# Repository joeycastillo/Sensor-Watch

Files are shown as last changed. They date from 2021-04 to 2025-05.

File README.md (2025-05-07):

The Sensor Watch
================

The [Sensor Watch](https://www.sensorwatch.net) is a board replacement for the classic Casio F-91W wristwatch. It is powered by a Microchip SAM L22 microcontroller with built-in segment LCD controller. You can write your own programs for the watch using the provided watch library, program the watch over USB using the built-in UF2 bootloader, and then install the board in your existing watch case to run your own software on your wrist.

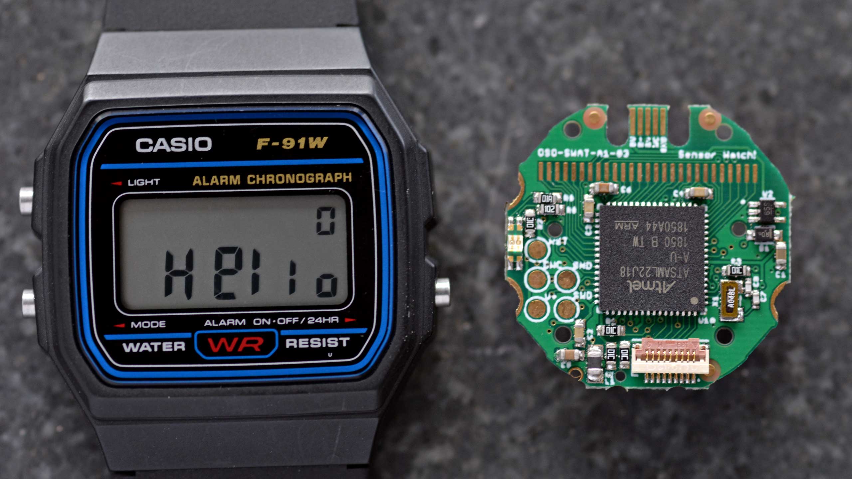
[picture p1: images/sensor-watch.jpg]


Features:
* ARM Cortex M0+ microcontroller
* 32KHz crystal for real-time clock with alarm function
* Ten digit segment LCD, plus five indicator segments
* Three interrupt capable buttons
* Red / green PWM’able LED backlight
* Optional piezo buzzer (requires some light soldering)
* On-board USB Micro B connector
* Reset button with double-tap UF2 bootloader
* Nine-pin flex PCB connector

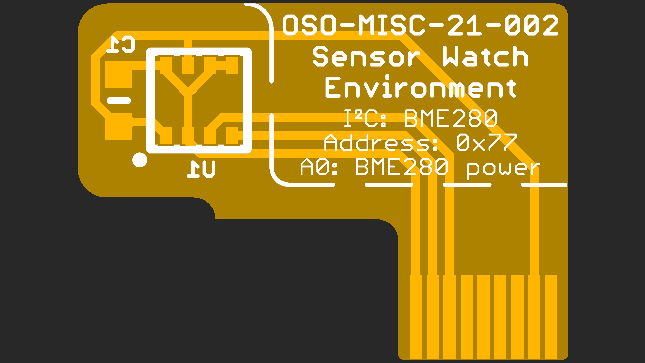
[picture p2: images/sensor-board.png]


You may have noticed that there are no sensors on this board. That is by design: rather than pick sensors for you, the goal is to add a tiny flexible PCB with the sensors YOU want, and interface them over the nine-pin connector. The connector provides the following options for power and connectivity:

* 3V power (nominal voltage from a CR2016 coin cell, can drop to ~2.7V)
* An I²C interface with built-in pull-up resistors
* Five general purpose IO pins, which can be configured as:
    * Five analog inputs
    * Five interrupt-capable digital inputs, with internal pull-up or pull-down resistors
    * Five digital outputs
    * SPI controller (with one spare analog / GPIO pin leftover)
    * One UART TX/RX pair (with three GPIO leftover)
    * Up to four PWM pins on two independent TC instances
    * Two external wake inputs that can wake from the ultra-low-power BACKUP mode

| **Pin** | **Digital** | **Interrupt** | **Analog** | **I2C** | **SPI** | **UART** | **PWM**  | **Ext. Wake** |
| :-----: | :---: | :---: | :---: | :---: | :---: | :---: | :---: | :---: |
| **A0**  | PB04 | EIC/EXTINT\[4\] | ADC/AIN\[12\] | — | — | — | — | — |
| **SCL** | — | — | — | SCL<br>SERCOM1\[1\] | — | — | — | — |
| **SDA** | — | — | — | SDA<br>SERCOM1\[0\] | — | — | — | — |
| **A1**  | PB01 | EIC/EXTINT\[1\] | ADC/AIN\[9\]  | — | SCK<br>SERCOM3\[3\]  | RX<br>SERCOM3\[3\] | TC3\[1\] | — |
| **A2**  | PB02 | EIC/EXTINT\[2\] | ADC/AIN\[10\] | — | MOSI<br>SERCOM3\[0\] | TX or RX<br>SERCOM3\[0\] | TC2\[0\] | RTC/IN\[1\] |
| **A3**  | PB03 | EIC/EXTINT\[3\] | ADC/AIN\[11\] | — | CS<br>SERCOM3\[1\] | RX<br>SERCOM3\[1\] | TC2\[1\] | — |
| **A4**  | PB00 | EIC/EXTINT\[0\] | ADC/AIN\[8\]  | — | MISO<br>SERCOM3\[2\] | TX or RX<br>SERCOM3\[2\] | TC3\[0\] | RTC/IN\[0\] |

These tiny “sensor boards” have a set outline, and the available area for your electronics is quite small (5.7 × 5.7 × 1 mm). Still, this is plenty of room for an environmental sensor, MEMS accelerometer or magnetometer and a couple of decoupling capacitors. Note that you will likely be limited to QFN and LGA type parts; SOICs are too large, and even SSOP packages are generally too thick. You can find reference designs for several sensor boards in the `PCB/Sensor Boards` directory within this repository.

Getting code on the watch
-------------------------
The watch library in this repository is very work-in-progress, but it should allow you to get started. To create a new project, copy the “starter-project” folder in the apps folder, and write your code in the app.c file.

You will need to install [the GNU Arm Embedded Toolchain](https://developer.arm.com/tools-and-software/open-source-software/developer-tools/gnu-toolchain/gnu-rm/downloads/) to build projects for the watch. The watch library has been tested with the `9-2019-q4-major` version and the `10.3-2021.07` versions. If you're using Debian or Ubuntu, it should be sufficient to `apt install gcc-arm-none-eabi`.

To build your project, open your terminal and navigate to the project's `make` folder, then type `make`.

To install the project onto your Sensor Watch board, plug the watch into your USB port and double tap the tiny Reset button on the back of the board. You should see the LED light up red and begin pulsing. (If it does not, make sure you didn’t plug the board in upside down). Once you see the “WATCHBOOT” drive appear on your desktop, type `make install`. This will convert your compiled program to a UF2 file, and copy it over to the watch.

Using the Movement framework
----------------------------
If you just want to make minor modifications and use existing code, start with the `movement` directory. You can build the default watch firmware with:

```
cd movement/make
make
```

Then copy `movement/make/build/watch.uf2` to your watch. If you'd like to modify which faces are built, see `movement_config.h`.

You may want to test out changes in the emulator first. To do this, you'll need to install [emscripten](https://emscripten.org/), then run:

```
cd movement/make
emmake make
python3 -m http.server -d build-sim
```

Finally, visit [watch.html](http://localhost:8000/watch.html) to see your work.

Hardware Schematics and PCBs
----------------------------

| Name | Color | Schematic | Gerbers |
| ---- | ----- | --- | --- |
| Sensorwatch Lite | RED | [PCB/Main Boards/OSO-SWAT-B1](PCB/Main%20Boards/OSO-SWAT-B1) | [OSO-SWAT-B1-03](PCB/Main%20Boards/OSO-SWAT-B1/OSO-SWAT-B1-03.zip) |
| Sensorwatch | GREEN | [OSO-SWAT-A1-05](PCB/Main%20Boards/OSO-SWAT-A1/OSO-SWAT-A1-05.sch) (Eagle format) | ? |
| Sensorwatch Pro  | TBD | TBD  | TBD |

License
-------
Different components of the project are licensed differently, see [LICENSE.md](https://github.com/joeycastillo/Sensor-Watch/blob/main/LICENSE.md).

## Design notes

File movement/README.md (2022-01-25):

Movement: the community watch face app
======================================

The Sensor Watch Library allows you to write your own bare-metal applications for the Sensor Watch. This is great if you want full control over the code running on the device, but it also means that you may have to implement your own UI for many common tasks like setting the time or illuminating the screen.

**Movement** is an application that manages the display of different screens of content on the watch. These screens are called **watch faces**. Watch faces can be passive displays of information like a clock or a calendar, or they can be fully interactive user interfaces like the Preferences face, which allows the user to customize Movement's behavior. Movement handles the instantiation of your watch face and manages transitions between screens. It also provides a low-power sleep mode, triggered after a period of inactivity, to preserve the watch battery.

Several faces are provided that offer baseline functionality like a clock, a settings screen and an interface for setting the time. You can change and reorder the watch faces that Movement displays by editing `movement_config.h`, and you can write your own watch face using the guidance in this document.

Watch Face API
--------------

You can implement a watch face using just four functions: 

* `watch_face_setup`
* `watch_face_activate`
* `watch_face_loop`
* `watch_face_resign`

A fifth optional function, `watch_face_wants_background_task`, will be added to the guide at a later date. You may omit it.

To create a new watch face, you should create a new C header and source file in the watch-faces folder (i.e. for a watch face that displays moon phases: `moon_phase_face.h`, `moon_phase_face.c`), and implement these functions with your own unique prefix (i.e. `moon_phase_face_setup`). Then declare your watch face in your header file as follows:

```c
#define moon_phase_face ((const watch_face_t){ \
    moon_phase_face_setup, \
    moon_phase_face_activate, \
    moon_phase_face_loop, \
    moon_phase_face_resign, \
    NULL, /* or moon_phase_face_wants_background_task, if you implemented this function */ \
})
```

You will also have to add your watch face to the `Makefile` so that it will be compiled in, and to `movement_faces.h` so that it will be available to add to the carousel. A good example of the changes required [can be found here](https://github.com/joeycastillo/Sensor-Watch/commit/2a59ae950f653a1730686ede8f77d74aea125efe).

This section will go over how each function works. The section headings use the watch_face prefix, but know that you should implement each function with your own prefix as described above.

### watch_face_setup

If you have worked with Arduino, this function is similar to setup() in that it is called at first boot. In our case, it is also called when waking from sleep mode. You will be passed three parameters:

* `settings` - a pointer to the global Movement settings. You can use this to inform how you present your display to the user (i.e. taking into account whether they have silenced the buttons, or if they prefer 12 or 24-hour mode). You can also change these settings if you like.
* `position` - The 0-indexed position of your watch face in the list of faces.
* `context_ptr` - A pointer to a pointer. On first run, the pointee will be NULL. If you need to keep track of any state within your watch face, you should check if it is NULL, and if so, set its value to a pointer to some value or struct that will keep track of that state. For example, the Preferences face needs to keep track of which page the user is viewing (just an integer), whereas the Pulsometer face needs to track several different properties in a struct.

Beyond setting up the context pointer, you may want to configure any peripherals that your watch face requires; for example, a temperature watch face that reads a thermistor output may want to configure the ADC here. Still, to save power, you should avoid leaving the peripheral enabled, and wait to set pin function in the activate function.

It was mentioned above but it's worth mentioning again: this function will be called again after waking from sleep mode, since sleep mode disables all of the device's pins and peripherals. This would give the temperature watch face a chance to re-configure the ADC.

### watch_face_activate

This function is called just before your watch enters the foreground. If your watch face has any segments or text that is always displayed, you may want to set that here. In addition, if your watch face depends on data from a peripheral (like that temperature watch face), you will likely want to enable that peripheral and set any required pin modes here. This function is also passed a pointer to the settings and your application context.

### watch_face_loop

This is a lot like your loop() function in Arduinoland in that it is called repeatedly whenever your watch face is on screen. There is one crucial difference though: it is called less often. By default, this function is called once per second, and in response to events like button presses. You can request a more frequent tick interval by calling `movement_request_tick_frequency` with any power of 2 from 1 to 64. (there is a 128 Hz prescaler tick, but Movement reserves that for its own use)

In addition to the settings and context, this function receives another parameter: an `event`. This is a struct containing information about the event that triggered the update. You mostly need to check the `event_type` to determine what kind of event triggered the loop. A detailed list of all events is provided at the bottom of this document. 

There is also a `subsecond` property on the event that contains the fractional second of the event. If you are using 1 Hz updates, subsecond will always be 0.

You should set up a switch statement that handles, at the very least, the `EVENT_TICK` and `EVENT_MODE_BUTTON_UP` event types. The mode button up event occurs when the user presses the MODE button. **Your loop function SHOULD call the movement_move_to_next_face function in response to this event.** If you have a very good reason to override this behavior (e.g. your user interface requires all three buttons), you may do so, but the user will have to long-press the Mode button to advance to the next watch face.

Note that `watch_face_loop` returns a boolean value. This boolean value indicates to Movement whether the watch can enter standby mode after handling your loop (true), or whether it should stay awake (false). You SHOULD almost always return true here, as the watch uses significantly more power when idling as opposed to standing by. The only times you would return false here are if you are PWM'ing the LED or emitting a sound from the buzzer. Your watch face would want to keep the watch awake in this case because the PWM driver does not run in standby.

### watch_face_resign

This function is called just before your watch face goes off screen. You should disable any peripherals you enabled in `watch_face_activate`. The watch_face_resign function is passed the same settings and context as the other functions.

Putting it into practice: the Pulsometer watch face
---------------------------------------------------

Let's take a look at a watch face to see how these pieces fit together. A *pulsometer* is [a mechanical watch complication designed to determine someone's pulse](https://www.ablogtowatch.com/longines-pulsometer-chronograph-watch/) by counting their heartbeats: you start the pulsometer, count heartbeats, and stop it when you reach the specified number. The needle will point to the pulse rate.

Let's implement a pulsometer for the Sensor Watch. These files are in the repository as `pulsometer_face.h` and `pulsometer_face.c`, but we'll walk through them inline here. 

### pulsometer_face.h

First, let's take a look at the header file. First we include the Movement header file, which defines the various types we need to build a watch face:

```c
#include "movement.h"
```

The pulsometer needs to track certain state to do its job, so we define a struct to contain our watch face's context:

```c
typedef struct {
    bool measuring;
    int16_t pulse;
    int16_t ticks;
} pulsometer_state_t;
```

Finally, we define the four required functions, and define the watch face struct that users will use to add the face to their watch:

```c
void pulsometer_face_setup(movement_settings_t *settings, uint8_t watch_face_index, void ** context_ptr);
void pulsometer_face_activate(movement_settings_t *settings, void *context);
bool pulsometer_face_loop(movement_event_t event, movement_settings_t *settings, void *context);
void pulsometer_face_resign(movement_settings_t *settings, void *context);

#define pulsometer_face ((const watch_face_t){ \
    pulsometer_face_setup, \
    pulsometer_face_activate, \
    pulsometer_face_loop, \
    pulsometer_face_resign, \
    NULL, \
})
```

### pulsometer_face.c

Now let's look at the implementation of the Pulsometer face. First up, we have a couple of definitions that we'll reference in the code: 

```c
#define PULSOMETER_FACE_FREQUENCY_FACTOR (4ul) // refresh rate will be 2 to this power Hz (0 for 1 Hz, 2 for 4 Hz, etc.)
#define PULSOMETER_FACE_FREQUENCY (1 << PULSOMETER_FACE_FREQUENCY_FACTOR)
```

These define the tick frequency: when the pulsometer widget is updating the screen, it will request 16 Hz updates (2^4).

#### Watch Face Setup

```c
void pulsometer_face_setup(movement_settings_t *settings, uint8_t watch_face_index, void ** context_ptr) {
    (void) settings;
    if (*context_ptr == NULL) *context_ptr = malloc(sizeof(pulsometer_state_t));
}
```

The `(void) settings;` line just silences a compiler warning about the unused parameter. The next line checks if the context pointer is NULL, and if so, allocates a `pulsometer_state_t`-sized chunk of memory to hold our state.

#### Watch Face Activation

```c
void pulsometer_face_activate(movement_settings_t *settings, void *context) {
    (void) settings;
    memset(context, 0, sizeof(pulsometer_state_t));
}
```

The pulsometer face doesn't need to keep track of context in between appearances; there's no need to keep displaying an old pulse reading hours or days after it was taken. So this line just sets the context to all zeroes before the watch face goes on screen.

#### Watch Face Loop

Next we have the loop function. First things first: it fetches our application context, and casts it to a `pulsometer_state_t` type so we can make use of it. It also creates a buffer for any text we plan to put on screen, and declares a switch statement for handling events:

```c
bool pulsometer_face_loop(movement_event_t event, movement_settings_t *settings, void *context) {
    (void) settings;
    pulsometer_state_t *pulsometer_state = (pulsometer_state_t *)context;
    char buf[14];
    switch (event.event_type) {
```

Let's go through each case one by one. In response to the user releasing the MODE button, we tell Movement to move to the next watch face.

```c
case EVENT_MODE_BUTTON_UP:
    movement_move_to_next_face();
    break;
```

Similarly in response to the user pressing the LIGHT button, we tell Movement to illuminate the LED. Movement does not do this automatically, in case your watch face UI has another use for the LIGHT button.

```c
case EVENT_LIGHT_BUTTON_DOWN:
    movement_illuminate_led();
    break;
```

The ALARM button is the main button the user will use to interact with the pulsometer. In response to the user pressing the ALARM button, we begin a measurement. We also request a faster tick frequency, so that we can update the display at 16 Hz.

```c
case EVENT_ALARM_BUTTON_DOWN:
    pulsometer_state->measuring = true;
    pulsometer_state->pulse = 0xFFFF;
    pulsometer_state->ticks = 0;
    movement_request_tick_frequency(PULSOMETER_FACE_FREQUENCY);
    break;
```

When the user releases the ALARM button, we finish the measurement. We also scale the update frequency back down to 1 Hz.

```c
case EVENT_ALARM_BUTTON_UP:
case EVENT_ALARM_LONG_PRESS:
    pulsometer_state->measuring = false;
    movement_request_tick_frequency(1);
    break;
```

The tick event handler is long, but handles all display updates. The first half of this conditional handles the case where we haven't yet measured anything: it just loops through five screens with instructions, and increments the tick count. 

```c
case EVENT_TICK:
    if (pulsometer_state->pulse == 0 && !pulsometer_state->measuring) {
        switch (pulsometer_state->ticks % 5) {
            case 0:
                watch_display_string("  Hold  ", 2);
                break;
            case 1:
                watch_display_string(" Alarn", 4);
                break;
            case 2:
                watch_display_string("+   Count ", 0);
                break;
            case 3:
                watch_display_string("  30Beats ", 0);
                break;
            case 4:
                watch_clear_display();
                break;
        }
        pulsometer_state->ticks = (pulsometer_state->ticks + 1) % 5;
```

The second half of the conditional handles the case where we are measuring or have a measurement to display. It does the math, updates the screen, and increments the tick count if needed.

```c
    } else {
        if (pulsometer_state->measuring && pulsometer_state->ticks) {
            pulsometer_state->pulse = (int16_t)((30.0 * ((float)(60 << PULSOMETER_FACE_FREQUENCY_FACTOR) / (float)pulsometer_state->ticks)) + 0.5);
        }
        if (pulsometer_state->pulse > 240) {
            watch_display_string("        Hi", 0);
        } else if (pulsometer_state->pulse < 40) {
            watch_display_string("        Lo", 0);
        } else {
            sprintf(buf, "    %-3dbpn", pulsometer_state->pulse);
            watch_display_string(buf, 0);
        }
        if (pulsometer_state->measuring) pulsometer_state->ticks++;
    }
    break;
```

Finally, the timeout event. After a period of inactivity (configurable from one to thirty minutes), Movement will send this event to indicate that the user has not interacted with your watch face in some time. Watch faces do not need to resign when they receive the timeout event, but depending on what kind of information your watch face displays, you may want to resign by asking Movement to return to the first watch face (usually a clock). The pulsometer widget has no need to remain on screen, so it opts to return to the clock when it receives the timeout event.

```c
case EVENT_TIMEOUT:
    movement_move_to_face(0);
    break;
```

#### Watch Face Resignation

The resign function doesn't have anything to do; it just has to be there.

```c
void pulsometer_face_resign(movement_settings_t *settings, void *context) {
    (void) settings;
    (void) context;
}
```

And that's that!

Low Energy Mode
---------------

To save energy, the watch enters a low energy mode after a timeout period (confugurable from 1 hour to 7 days). In this mode, the watch will turn off all pins and peripherals except for the screen and real-time clock, and will wake up once a minute to allow the current watch face to update its display.

Movement Event Types
--------------------

### EVENT_ACTIVATE

You will receive this event when your watch face is entering the foreground. You can treat it like a tick event and just update the display.

### EVENT_TICK

This is the most common event type. Your watch face is being called as a result of the real-time clock ticking. By default this tick occurs once per second, but you can request more frequent updates.

### EVENT_LIGHT_BUTTON_DOWN, EVENT_MODE_BUTTON_DOWN, EVENT_ALARM_BUTTON_DOWN

Your watch face receives these events when one of the buttons is initially depressed, but before it is released.

### EVENT_LIGHT_BUTTON_UP, EVENT_MODE_BUTTON_UP, EVENT_ALARM_BUTTON_UP

Your watch face receives these events when one of these buttons is released quickly after being depressed (i.e. held for less than one second).

### EVENT_LIGHT_LONG_PRESS, EVENT_MODE_LONG_PRESS, EVENT_ALARM_LONG_PRESS

Your watch face receives these events when one of these buttons is released after having been held down for more than two seconds.

### EVENT_TIMEOUT

Your watch face receives this event after it has has been inactive for a while. You may want to resign here, depending on your watch face's intended use case.

### EVENT_LOW_ENERGY_UPDATE

If your watch face is in the foreground when the watch goes into low energy mode, you will receive an `EVENT_LOW_ENERGY_UPDATE` event once a minute (at the top of the minute) so that you can update the screen. Note however that when you receive this event, all pins and peripherals other than the RTC will have been disabled to save energy. If your display is clock or calendar oriented, this is fine. But if your display requires polling an I2C sensor or reading a value with the ADC, you won't be able to do this. You should either display the name of the watch face in response to the low power tick, or ensure that you resign before low power mode triggers (you can do this by calling `movement_move_to_face(0)` in your `EVENT_TIMEOUT` handler).

**Your watch face MUST NOT wake up peripherals in response to a low energy update event.** The purpose of this mode is to consume as little energy as possible during the (potentially long) intervals when it's unlikely the user is wearing or looking at the watch.

### EVENT_BACKGROUND_TASK

The `EVENT_BACKGROUND_TASK` event is not yet implemented, but the plan is for this event type to allow waking peripherals even in low power mode. More information will be added in a future version of this guide.

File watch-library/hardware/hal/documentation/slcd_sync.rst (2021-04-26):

SLCD Synchronous driver
=======================

An LCD display is made of several segments (pixels or complete symbols) which
can be block light or let light through. In each segment is one electrode
connected to the common terminal (COM pin) and one is connected to the segment
terminal (SEG pin). When a voltage above a certain threshold level is applied
across the liquid crystal, it will change orientation and either let light
through or block it.

The driver supports segment on/off/blink, animation and character display.

Each segment has a unique int32 segment id which is used by the driver. The id is
combined by common number(COM) and segment number(SEG), the COM and SEG start from 0.
The unique segment id is calculated by this formula: (COM << 16) | SEG
For example a 8(coms)*8(segments)SLCD, the unique segment id for segment should be

    +-----+-----+---------+
    | COM | SEG |   ID    |
    +-----+-----+---------+
    |  0  |  0  | 0x00000 |
    +-----+-----+---------+
    |  1  |  0  | 0x10000 |
    +-----+-----+---------+
    |  7  |  7  | 0x70007 |
    +-----+-----+---------+

Segment ID can be calculated using the pre-defined macro SLCD_SEGID(com, seg).

For character display, the "segment character mapping table" and "character mapping table"
should be setup in configuration. The driver have no API to setup/change those
mapping setting.
There are two pre-defined "segment character mapping table" in this driver, 7 segments
and 14 segments. The 7 segment character mapping can display 0-9 and a-f, the 14
segments character mapping can display 0-9, A-Z and some special ASCII, for more
details please refer to hpl_slcd_cm_7_seg_mapping.h and hpl_slcd_cm_14_seg_mapping.h.
Application can also adjust this mapping table in the configuration header file,
to add more character mapping or remove some unused character.

The "character mapping" is used to setup each character in SLCD display screen.
The driver supports multiple character mapping, the max number varies on different
MCU/MPU. For example if an LCD display screen has five "7-segments character" and
eight "14-segments character", and the MCU support max 44 characters setting, then
the 13 character should be setup in configuration. Application can select any
position from those 44 characters setting to save those 13 character.
The index of character setting will be used in the driver API. For example:
five "7-segments character" setting to 0 to 4 and eight "14-segments character" setting
to 10 to 17. Then the application can use index from 0 to 4 to display the
"7-segments character" and use index from 10 to 14 to display "14-segments character".

Features
--------

* Initialization and de-initialization
* Enabling and Disabling
* Switching segment on/off
* Set segment blink
* Autonomous animation
* Character display

Applications
------------
* SLCD display control, segment on/off/blink
* Play battery animation, running wheel, wifi signal, etc.
* Display Time Clock by 7 segments character mapping
* Display ASCII character by 14 segments character mapping

Dependencies
------------
* SLCD capable hardware

Concurrency
-----------
N/A

Limitations
-----------

Known issues and workarounds
----------------------------
N/A

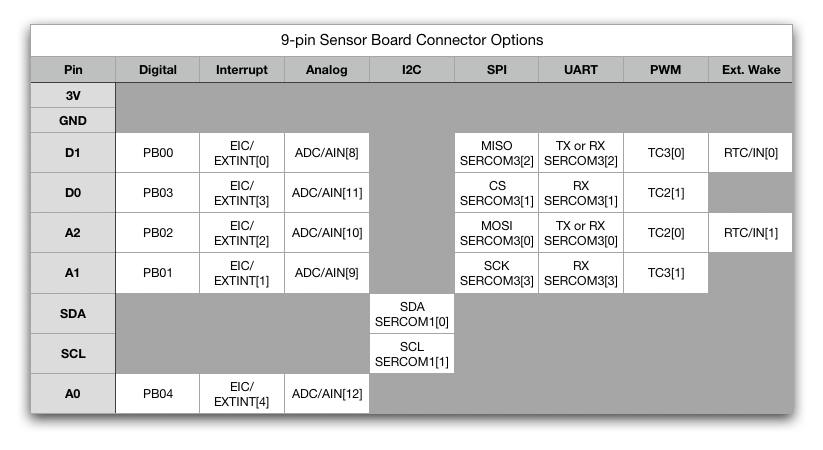
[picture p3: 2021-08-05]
images/sensor-board-pinout.png

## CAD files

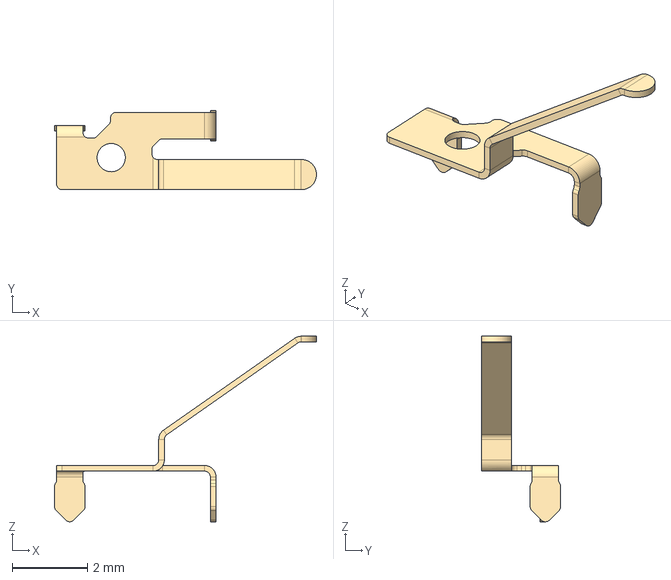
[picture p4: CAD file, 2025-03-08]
PCB/Main Boards/OSO-SWAT-C1/contact_adjusted_angle.step
6.95 x 2.10 x 4.92 mm

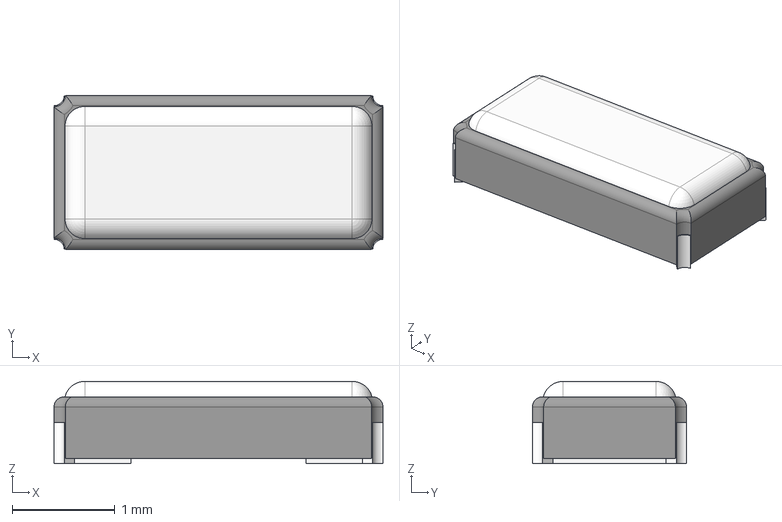
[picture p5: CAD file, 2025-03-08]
PCB/Main Boards/OSO-SWAT-C1/NX3215SA.step
3.20 x 1.50 x 0.8 mm

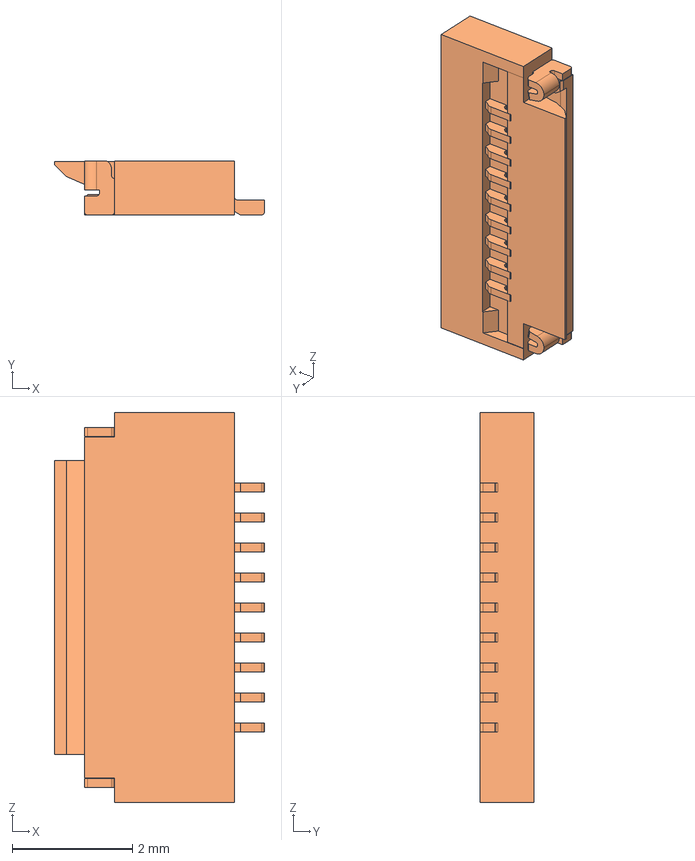
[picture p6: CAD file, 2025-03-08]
PCB/Main Boards/OSO-SWAT-C1/FH19C-9S-0.5SH.stp
3.50 x 0.9 x 6.50 mm

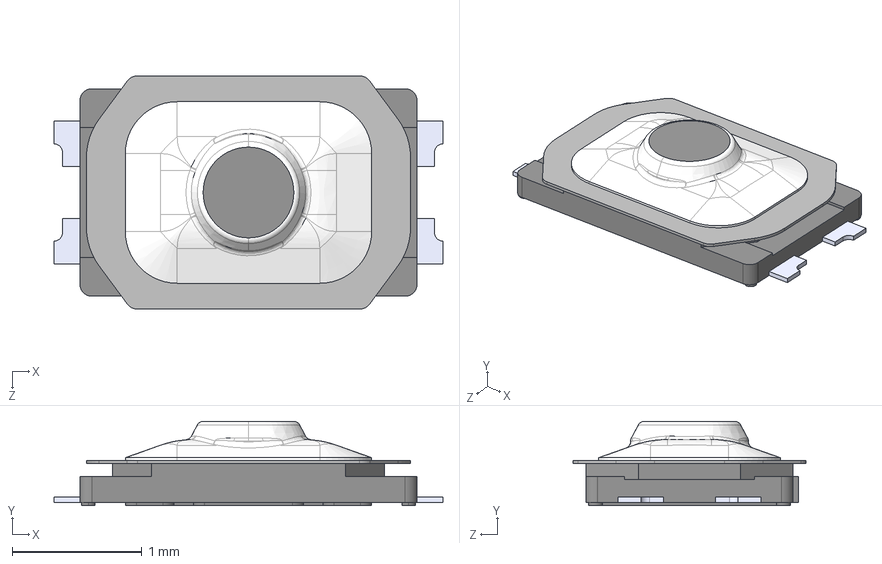
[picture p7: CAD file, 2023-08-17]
PCB/Main Boards/OSO-SWAT-C1/EVP-BB4A9B000--3DModel-STEP-56544.STEP
3.00 x 0.65 x 1.80 mm

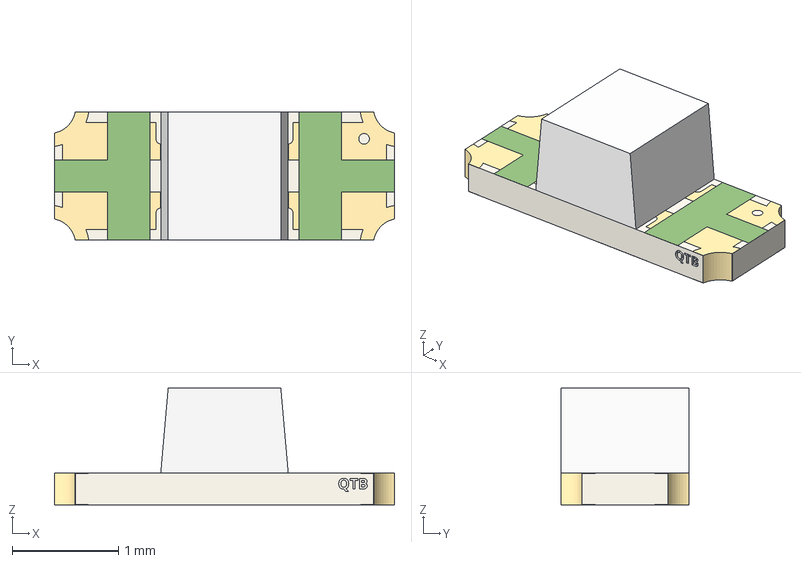
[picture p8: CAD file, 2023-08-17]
PCB/Main Boards/OSO-SWAT-C1/QBLP655_QBLP655R_BI_TRI.step
3.20 x 1.20 x 1.10 mm

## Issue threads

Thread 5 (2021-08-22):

Possibly ~8% (~5µA) Power Savings By Disabling The EIC

gennyble, 2021-08-22:
Looking at the docs, `watch_enable_buttons()` has this note attached:

> The BTN_ALARM button runs off of an interrupt in the the RTC controller, not the EIC. If your application ONLY makes use of the alarm button, you do not need to call this method; you can save ~5µA by leaving the EIC disabled and only registering a callback for BTN_ALARM.

I wonder if we can disable the EIC when we don't need it. I'll describe the strategy I'm trying in my application below. I've implemented it successfully, but I can't measure current as low as this is so I don't know if the EIC is *actually* powered down.

The watch is idle most of the time which probably means we don't need all the buttons to work. In my app I have a 5 second timeout where if no buttons were pressed, the EIC is deinitialized ([here][deinit]) and reinitialized when the alarm button is preesed ([here][reinit]). There's a 250ms green LED flash on deinit and reinit that tells the user it's gone into/come out of idle.

[deinit]: https://github.com/gennyble/neralie-sensor-watch/blob/main/app.c#L119-L129
[reinit]: https://github.com/gennyble/neralie-sensor-watch/blob/main/app.c#L95-L108

gennyble, 2021-08-22:
I looked a bit further in to the code and the SAML22's docs, and it seems it's possible to disable and enable the EIC without having to reinitialize. I ripped some code out of `hpl_eic.c` ([here](https://github.com/joeycastillo/Sensor-Watch/blob/42f0eac6d12bb354ce34f1cee42ad43f8a023282/watch-library/hpl/eic/hpl_eic.c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) and [here](https://github.com/joeycastillo/Sensor-Watch/blob/42f0eac6d12bb354ce34f1cee42ad43f8a023282/watch-library/hpl/eic/hpl_eic.c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)) and have it working as demonstrated [here](https://github.com/gennyble/neralie-sensor-watch/blob/e3730bdf09e0b594e7c1b85e995527c8e8c99d95/app.c#L50-L65).

joeycastillo, 2021-08-23:
I would definitely like to add a function to the library disable the EIC. There are also a couple of other functions missing that would disable e.g. the segment LCD controller or the ADC; I just haven't gotten around to them.

If you added this function to the library I would totally merge it in; otherwise I will take a crack at it later this week.

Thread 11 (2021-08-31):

CC2640

MstrVLT, 2021-08-31:
Can we expect a project with CC2540 / CC2640 in the future? (The BeetleBle uses a CC2540 with ATmega328, but it's a huge size 6 x 6 mm)
CC2640 size is 4 × 4 mm RSM VQFN32 (10 GPIOs)
Add a vibration motor from junk mobile phone and you have a great smartwatch (actually still need e-inc screen)

joeycastillo, 2021-09-10:
I do not have any plans in this direction, but if the required components are small enough, they may fit on a sensor board; alternatively, it may be possible to incorporate this component into another design based off of this one. The designs are open source; I'd encourage you to build on it! But I don't think this needs to be tracked an issue.

Thanks for the suggestion!

Closed 2021-09-10.

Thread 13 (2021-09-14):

App contributions?

tahnok, 2021-09-14:
I've finished writing my first app for the sensor watch, witch displays the current Swatch Internet time. You can check out the code over here (https://github.com/tahnok/Sensor-Watch/commit/bd4626ab2f1af79674947f793fff01268f459724) but before I open an PR with it, I'm curious to know you want to handle contributed apps / firmware.

I quite like the way that the [Goodwatch](https://github.com/travisgoodspeed/goodwatch/tree/master/firmware) handles this, which that there is a single firmware codebase. A user can configure what functionality they want at build time by changing a Makefile. App writers don't have to worry about code for the 'core' functionality of watch (like setting the time).

Basically, I would love if there was a way to have firmware with some normal watch functionality (like a stopwatch or a countdown timer) and some weird watch functionality (like a random number generator or weird time keeping systems) combined into a single codebase somehow, while still allowing someone to toss it all and use the (wonderful) framework you are putting together

joeycastillo, 2021-09-15:
This is awesome!! I totally agree that a system like what's offered by the Goodwatch would be ideal, but I haven't finished thinking through the UI for it. Whereas the Goodwatch has a button matrix as well as a side button, the F91-W only has three buttons; claiming the Mode button for switching apps only leaves two buttons for apps to work with. Perhaps a two-button gesture or a press-and-hold could move between apps? Either way, I think that whatever "launcher" app ends up making sense will be one level of abstraction up from this library; that is to say, it will probably be another project at the root of the repo, and apps that want to be a part of it will go inside of that project and interact with a more high-level API.

For now, though, I think that there should probably be an 'apps' folder for apps like yours that work with the low-level library directly, but I think I need to do a Makefile tweak to make that make sense. I will update this issue when I make that change (tho it may require a small change to your project's Makefile).

joeycastillo, 2021-09-16:
OK! I've rearranged the repo slightly: there is now an "apps" directory, and your project can go in there.

The Makefile changes required are small and you can see them [here](https://github.com/joeycastillo/Sensor-Watch/blob/main/apps/Sensor%20Watch%20BME280%20Project/make/Makefile). In short:

* add `TOP = ../../..` at the beginning
* change the make.mk line to `include $(TOP)/make.mk`
* change the rules.mk line to `include $(TOP)/rules.mk`

tahnok, 2021-09-25:
Yeah, the 3 buttons certainly poses a user interface challenge. I think a long press would be easier to use then a double tap, but I think a more complex 'button input handling + callback' library would be useful. I'd like to take a crack at that, but I might not get to it for a week or 2. My dream is to have a quick and easy shortcut from the main watchface to start a 3min tea timer

I've applied the Makefile changes you've suggested and opened up a PR: https://github.com/joeycastillo/Sensor-Watch/pull/15

joeycastillo, 2021-10-04:
Renamed this issue to focus on what you mentioned in your initial comment (firmware with some normal watch functionality and some weird watch functionality). I've been working on something like that [in this branch](https://github.com/joeycastillo/Sensor-Watch/compare/wip-launcher); it's not ready to merge and the nomenclature / API is likely to change, but figured I'd put it forward as a source for ideas.

The gist is that the "launcher" is a bare metal app much like the apps we've been writing so far, and it manages the display of a number of "widgets" that can take over the display, one at a time. Each widget has:

* a setup function (called at boot and wake from sleep)
* an activate function (called before coming on screen)
* a loop function, which is also passed an event (like a button press) that caused the function to be called
* a resign function (called before going off-screen)

I made a few widgets just to test out the system (clock, preferences, and set time), and it seems like it might be workable. This may not be as powerful or customizable as someone rolling their own app from scratch, but could be a starting point for folks who want to add one interesting screen without having to worry about core functions like setting the time.

Open to thoughts and comments from anyone!

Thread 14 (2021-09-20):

Build PCB

elalemanyo, 2021-09-20:
Hi,
Maybe this is a rookie question, but how can I get/build the PCB?

Thanks

joeycastillo, 2021-09-20:
I'm working on having a run of 100 manufactured in the near future; that will be a way to get the fully assembled gadget.

You can order the PCB yourself using the gerbers; they're in the `OSO-SWAT-A1-05-BLUE_2021-09-20.zip` file in [PCB/Main Boards](https://github.com/joeycastillo/Sensor-Watch/tree/main/PCB/Main%20Boards). Note that if you do this, you will need to order the PCB in 0.6 mm thickness for it to fit in the watch case.

Still, I would recommend waiting for the fully assembled boards; the ATSAML22J18A-MUT that I'm using is out of stock basically everywhere right now, so you would have a hard time building it on your own right now regardless.

tangbao, 2021-09-29:
Hi,

It is exciting to know that I can buy fully assembled boards in the future!!

For ATSAML22J18A-MUT, have you ever tried to find sellers from China (like AliExpress)? For example, you can buy 10 pcs for $37.8 at https://www.aliexpress.com/item/4000775253513.html. I believe that it will be cheaper if you buy 100 or more. Some other things like resistances, sensors, and PCB manufacturing are cheaper in China as well. The only thing we need to worry about is the shipping time, which could take one month or more (but the shipping is cheap as well).

I'm glad to help you if you think it could be a good idea (I'm not sure) to contact AliExpress sellers / PCB manufacturers in Chinese.

Thank you for your great project! I cannot wait to get my own sensor watch!

tangbao, 2021-10-08:
Would you please consider this suggestion? @joeycastillo

tangbao, 2021-10-11:
> > Would you please consider this suggestion? @joeycastillo
>
> I am currently on track to produce a first run of 100 boards domestically, using chips sourced from Mouser before the shortage. I am not as certain about sourcing chips from Aliexpress; either way, right now my focus is on getting this run produced and in folks’ hands before considering anything like that.

Yes, I fully understand that. I thought you did not have enough chips to make 100 boards. I was just providing some suggestions on where to buy chips and other supplies.

Thank you for your work and looking forward to its publish day!

Closed 2021-09-20.

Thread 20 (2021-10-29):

Enabling BLE

trash-anger, 2021-10-29:
Hi Joey,

Do you think there space for tiny ble antena and ship ?

joeycastillo, 2021-11-11:
I have my doubts, if I'm being perfectly honest. The only space available for something like this would be on a small sensor board connected over the 9-pin connector, and there's just not a lot of room in there. Additionally, the power budget for this device has a hard ceiling at 100 milliampere hours due to the size and shape of the coin cell involved. To keep the thing as small as it is, and to make it work for as long as we want it to, my sense is that BLE is going to be out of scope.

Having said that, far be it from me to say what is and isn't possible. The sensor board spec is open, and [others have suggested chips that may make this possible](https://github.com/joeycastillo/Sensor-Watch/issues/11). It's not something I personally foresee putting on the roadmap (which is why I'm closing the issue), but if the someone wants to try making a tiny BLE add-on board for the watch, I'd be thrilled to see what they can do.

Closed 2021-11-11.

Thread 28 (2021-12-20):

Movement: more granular timing of background tasks

tahnok, 2021-12-20:
I've been thinking on and off how to implement some kind of countdown timer and I wanted to start a discussion around it.

From what I understand, the SAM L22 only has the one RTC. The alarm is being used to fire the once a minute wake up in low power mode. Movement apps can hook into background task callbacks if they want, but the 'granularity' is limited to once a minute.

Given the above, I don't see a way to make a timer that runs in the background that can fire at a granularity of more than a minute. I think that could be fine for some use cases (I'm thinking a pomodoro app would be neat) but I like to make tea using a 3 minute timer.

The best I can come up with at the moment is to have 2 kinds of timers, a short accurate one that must run in the foreground so it can receive 1Hz updates and a long / low power one that is limited to firing on the minute

joeycastillo, 2021-12-20:
The granularity thing is a problem with movement as implemented, but I think with some changes we can get there. The main thing isn't necessarily that the watch face needs to be in the foreground, just that as long as a countdown is running, someone needs to be checking for a match every second. I think we can have Movement do this, and notify the watch face when there is a match. It would mean the watch can't enter low energy mode while a timer is running, but I sense we only need second-level granularity for minutes to hours at a time; a daily alarm or weeks-long countdown can work fine on the minute boundary.

I'm going to play with this today; my instinct is to add a function like:

```void movement_schedule_background_task(watch_date_time date_time)```

Each watch face can schedule one background task, and as long as a background task is scheduled, the watch won't enter low energy mode. Each tick, Movement will compare the current timestamp to the scheduled task's timestamp, and on a match, call the watch face's `loop` function with an `EVENT_BACKGROUND_TASK`. The watch face can then use the background task event to play a sound.

I would like for there to be some way for the watch face to request a move to the foreground (i.e. to play an alarm and display a message), but for now I think allowing a more granular background task will be enough to implement a countdown timer.

joeycastillo, 2021-12-20:
I think [this code](https://github.com/joeycastillo/Sensor-Watch/compare/scheduled-background-tasks) should do what we need; let me know what you think?

The one big limitation is, you can only schedule a background task while active and in the foreground. This is probably fine for a countdown timer since the task will be scheduled in response to the wearer pressing a button, but it may be a challenge for something like a pomodoro app that would want to start a new timer as soon as a previous timer fires. We'd likely need to implement forced foregrounding to allow for that use case, or add an index parameter to this API (which is a challenge since currently watch faces don't know their index in the list of watch faces).

tahnok, 2021-12-21:
Code looks good, I don't see anything that would stop a countdown face from being written. From the background, can watch face play a tone?

I agree that having a face be able to bring itself to the foreground would be really handy though. Maybe when the faces are initialized they can be handed their index which they can store if they want? Or when processing background tasks maybe the face can return true/false if it wants to be brought to the foreground?

joeycastillo, 2021-12-21:
A watch face can play a short two-beep signal (`movement_play_signal`) from the background; alas the longer alarm sound (`movement_play_alarm`) wouldn't work. You could play a longer signal by using a series of `watch_buzzer_play_note` calls, but these block the UI while playing a note or a rest.

Anyway! I merged in changes that address two items in this thread:

* You can now schedule one background task per watch face. As long as the background task is active, the watch won't enter low energy mode, and whether you're in the foreground or not, you'll get an EVENT_BACKGROUND_TASK at the specified time.
* Watch faces now receive their index in the watch face array in the setup function. Watch faces can [stash this index in their context](https://github.com/joeycastillo/Sensor-Watch/blob/6256e709bf0e29444f6d5383897bc77acd242529/movement/watch_faces/clock/simple_clock_face.c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), and use it later to [force themselves into the foreground](https://github.com/joeycastillo/Sensor-Watch/blob/6256e709bf0e29444f6d5383897bc77acd242529/movement/watch_faces/clock/simple_clock_face.c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). One issue is that if you have a blocking task like playing a sound on the buzzer, the display won't refresh and display your watch face until after the sound finishes playing and control is returned to Movement. Fixing this could be a useful enhancement later.

I also added an option in simple_clock_face to turn on an hourly signal, just like the F-91W's hourly signal, that [can trigger both in the normal and low energy modes](https://github.com/joeycastillo/Sensor-Watch/blob/6256e709bf0e29444f6d5383897bc77acd242529/movement/watch_faces/clock/simple_clock_face.c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). This can be a template for folks who want to implement alarms in response to a background task.

Closed 2021-12-21.

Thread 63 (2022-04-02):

Milestone: getting to version 0.1.0

joeycastillo, 2022-04-02:
The first 90 Sensor Watch boards are going to be going out to the first backers later this month, and as such I would like to move the library toward something resembling a production quality release. There are a few changes I want to make that I don't think will break what anyone has done so far, but I want to announce them here just in case.

First: I plan to remove all deprecated functions from the library, including the Debug UART. I don't expect this to be an issue; as far as I can tell, no existing watch faces or apps use any deprecated functions at this time.

The bigger change for folks with early hardware: I plan to make the default board `OSO-SWAT-A1-05` instead of `OSO-SWAT-A1-04`. This won't have any impact on builds once the watch is installed in a watch case. _However:_ the USB serial console (which you print to with printf) will not function, as the pin for detecting a USB connection has changed. You will still be able to build firmware for the old boards by running `make BOARD=OSO-SWAT-A1-04`, but if you are not using printf to log things over USB, there should be no difference whatsoever if you just run `make`.

In addition, if anyone has suggestions for other things that we might want to do before this first milestone release, please let me know in this thread!

davidskeck, 2022-04-05:
Hi Joey, as far as suggestions would you want to perform any static analysis before this release?

joeycastillo, 2022-04-05:
I would love to perform static analysis; I'm down with anything that improves the firmware's reliability and correctness. Do you have a particular tool that you would suggest using?

davidskeck, 2022-04-06:
I really like [Cobra](http://spinroot.com/cobra/).

I use the built in rule sets, not the interactive portion (though that is cool too).

I'm not sure if you want to try to adhere to MISRA or anything, but the basic ruleset and cwe are pretty good. I can help configure it if you want to try it out!

davidskeck, 2022-04-06:
I got this working in the previous version of Cobra. Here's an attachment of the basic ruleset output.
[cobra_basic.txt](https://github.com/joeycastillo/Sensor-Watch/files/8422924/cobra_basic.txt)

davidskeck, 2022-04-06:
'metrics' is the rule file that Cobra is wanting to use. There are a few rulesets that come with Cobra. I ran 'basic' and 'misra2012'. Typically I run all of them but I didn't add all of that to the Makefile yet.

There is a configuration step in the Cobra docs that puts the path to the rulesets where Cobra can see them. Did you run that step?

It is on [this page](http://spinroot.com/cobra/downloads.html) -- 'cobra -configure $COBRA/rules'

joeycastillo, 2022-04-06:
Ah, got it! I had put the binaries in kind of an odd spot so the rules directory was configured awkwardly. Also it looks like the `bad field type 'fct'` lines aren't going to stdout (maybe to stderr?) so they're likely not related to the analysis.

There are definitely some actionable things in there, but I'm a bit confused by some of the other results; for example, I'm getting several of these:

```
=== Inconsistent checks of function return values:
 1: _update checked 2 times out of 4
```

The thing is, _update is a void function and we never seems to check the return value at all. I can silence the warning by changing lines like

```
if ((date_time.unit.minute == 0) && (date_time.unit.second == 0)) _update(settings, state, state->offset);
```

to

```
if ((date_time.unit.minute == 0) && (date_time.unit.second == 0)) {
    _update(settings, state, state->offset);
}
```

but I'm unclear as to whether what I was doing previously is actually incorrect, or if this is a false positive.

Similarly it's firing on some "empty while statements" like `while(!SUPC->STATUS.bit.VREGRDY);`. I get this one: since the condition is just a bit in memory, static analysis sees it as a while(0) or while(1). But since the register's value will change when the underlying state of the hardware changes, this is actually correct.

Basically I'm wondering how I should interpret what it's telling me, whether the goal is to get to zero warnings, and if in cases where some of what's there is known to be correct, if there's a way to tell this to the tool so it can become part of the build steps and alert us when something is really off.

davidskeck, 2022-04-10:
Hey there. Sorry for the delayed reply.

Great point about the lines potentially going to stderr.

Yes, so I have used Cobra on a few projects, and it does generate some false positives, The void function one appears to be one,

For the while loops, itt isn't saying that the value won't change, just that the `while` doesn't contain any statements, like there are no curly braces that contain code to be executed as part of the `while`. I get it for the same reason though -- waiting on a register to change.

The goal is not to get zero warnings, and yes there are cases where it can be incorrect. I always check the results however to determine for myself if it is a false positive. So far there isn't a way that I know of to silence any particular warning though there is an `[effort](https://github.com/nimble-code/Cobra/issues/20)` to have Cobra support `[SARIF](http://docs.oasis-open.org/sarif/sarif/v2.0/csprd01/sarif-v2.0-csprd01.html)` which would allow it to work with some static analysis tool sets.

Basically I like using Cobra since it is freely available and has caught many true issues when using CWE/MISRA/JPL/P10 rulesets. Though you have described some of the rough edges. I have a tool (that I unfortunately can't open source at the moment) that interprets Cobra logs and allows you do perform some filtering on them to make things a little easier in the meantime.

joeycastillo, 2022-04-10:
Thanks so much, this is very helpful! It did expose several actionable things, both style and substance. One of the inconsistently checked return value warnings helped explain a glitch in the World Clock when exiting settings mode! And it also seemed wise to add comments to those empty loops to make it clear what they're for.

One other thing it exposed is some lazy coding on my part: the underlying IO calls for SERCOMs (SPI, I2C, UART) return status codes to indicate whether reads and writes were successful. Ideally, the watch API for this would return at least boolean values for success or failure, but as of now all my calls are `void` (or in the case of `watch_uart_getc`, the received character). This feels like a good place for future improvement, but it's not something I addressed in this round.

Closed 2022-04-21.

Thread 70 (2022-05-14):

Automated settings restore

davidskeck, 2022-05-14:
Hello,

I've been wondering if it would be possible to create a script that runs at build time to automatically set a few things.

It could set Lat Long,  date, Time + some offset to allow for reassmbly, and some things like world clock, timeout, etc.

Would this even be possible? I tried to find a place to set some of these, but I'm not sure where to look for everything.

A user could, for example, set their desired settings in JSON file and the initial setting could be inserted into the code where appropriate. Just something I've been thinking about.

joeycastillo, 2022-05-14:
I love this idea and there are a couple of places where I think it could hook in nicely. For situations where we want a given firmware to have certain presets, we could do it at build time; for example, the Deep Space Now firmware uses the `MOVEMENT_CUSTOM_BOOT_COMMANDS` definition to [preset the World Clocks to Goldstone, Madrid and Canberra](https://github.com/joeycastillo/Sensor-Watch/blob/main/movement/alt_fw/deep_space_now.h#L30). Stargazer does something similar to [preset the LED to red](https://github.com/joeycastillo/Sensor-Watch/blob/main/movement/alt_fw/the_stargazer.h#L30) for night vision reasons.

Location is something I've thought about, but I don't think it would make a huge amount of sense to be compiled in. Instead I wonder if we could add it as a command the wearer could issue after flashing the firmware. Now that we have 7-8 kilobytes of nonvolatile storage (in [the LFS branch](https://github.com/joeycastillo/Sensor-Watch/tree/lfs)), I could see either writing a lat/lon to a text file that we parse, or adding a command like `setloc 40.70, -73.95` that would write the location to a hidden file that Movement could expect to read in at boot. Right now Movement just reads from the USB serial console and lets the "filesystem.c" file [parse out a command](https://github.com/joeycastillo/Sensor-Watch/blob/lfs/movement/movement.c#L432) (itself a pattern I'm not wild about). But if we gave Movement more of a command line interface while plugged in to USB, we could let folks store all kinds of settings on the filesystem that watch faces could then read back when installed in a watch case.

Date+time offset, perhaps we could add a "save" option somewhere in settings that would write the current configuration to the file system, and a "load" option that would read it back out after i.e. disassembling to replace the battery?

davidskeck, 2022-05-18:
Oh nice! I love LFS! I have used that on another project and it was a wonderful project.

I like the idea of putting the location, time, and possible future data into files via command. That makes a lot of sense and would, as you said, persist across battery replacements which is nice.

In the meantime, if you have any questions about LFS let me know and I'll field them as best as I can. The issues page for that project is pretty active as well.

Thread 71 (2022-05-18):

Stange behavior with side light

davidskeck, 2022-05-18:
Hello,

I was using my watch, and attempted to use the side light and got some odd behavior.

For context, I did have the light set to mix the green and red colors to make a somewhat yellow color. This had worked previously, but I had noticed it was a little slower to respond, and then the attached video occurred. I was able to stop this but only by going into settings and turning off the red portion of the light.

Any ideas? I have since reflashed my board (to get the new tomato face!)

https://user-images.githubusercontent.com/1740630/168938319-c504408b-673a-4f4b-a52f-2a2dafda4e32.mp4

joeycastillo, 2022-05-18:
interesting! I would expect the light to get stuck on red when the watch enters standby mode, as the PWM driver stops running in standby. But Movement should prevent the watch from entering standby for as long as the LED is on.

My guess is that this is a glitch with the `light_ticks` property in movement_state; I'll see if I can replicate it.

davidskeck, 2022-05-19:
I wanted to mention that when I disassembled the watch after this occurred I noticed that the metal tab to press the light button was flaky due to it being bent. I replaced it and it works well now, but it could have been hammering the contact multiple times a press if it was making intermittent contact.

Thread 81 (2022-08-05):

Easier UF2 mode?

tahnok, 2022-08-05:
While working on #76 I find myself flashing firmware repeatedly and getting annoyed at finding the reset button to double tap each time. Is there a way to reboot into UF2 mode with code in normal mode? That way you could extend the movement USB cli to have a `reboot` command, or do some other trick so that the programming computer could reset the sensorwatch into UF2 mode

joeycastillo, 2022-08-14:
This is a great idea! And sorry for the delay in responding; this issue caught me during a week I was traveling. I'm adding a new function, `watch_reset_to_bootloader()`, that does exactly this.

Background: to realize the double tap reset function, the UF2 bootloader sets a magic number at a specific location in RAM when the board resets. It then waits 500 ms and clears it. If the user taps reset a second time within that 500 ms interval, the magic number is still set; the bootloader recognizes that case, and takes control.

The `watch_reset_to_bootloader` function fakes out the bootloader by setting the magic number, and immediately calling `NVIC_SystemReset()`. At that point, the bootloader believes that this is the second tap of the reset button, and enters bootloader mode. Try it out and reopen if you find any issues, but I think it should be good to go as soon as I close this!

Closed 2022-08-14.

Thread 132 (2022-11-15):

Inconsistent bell/signal indicator usage

wryun, 2022-11-15:
Previously, faces (e.g. wake/countdown/tomato) used the `WATCH_INDICATOR_BELL` to say that there was an alarm coming up. The cool new alarm face (and the 'alarm_enabled' bit of simple_clock) now use `WATCH_INDICATOR_SIGNAL`.

I'm guessing that those faces should be changed to use `WATCH_INDICATOR_SIGNAL`.

On the other hand, I'm not sure I like the change. The thermistor/voltage/accelerometer faces use `WATCH_INDICATOR_SIGNAL` when they read data, and this fits better than the bell IMO. i.e. we're now overloading SIGNAL, and under-using BELL (which will be left with only the hourly chime?).

Thoughts - @TheOnePerson , @joeycastillo ?

joeycastillo, 2022-11-15:
For the hourly signal, this was originally a mistake of mine: the usage on the original F-91W is that the bell icon indicates the status of the hourly signal, and the signal icon indicates the status of the alarm. To make it feel consistent for folks, we swapped them to match.

I'm of the opinion that watch faces should feel free to use whatever indicator makes the most sense for their UI:

* Wake should probably switch over to signal, since it is an alarm.
* In the case of sensor faces, I think the signal icon also makes sense; it feels to me like data being sampled.
* In the case of countdown/tomato, I'm agnostic about which one is used. Signal would match the "alarm"iness of the main face, but the bell could indicate a warning or alert condition, like “Be vigilant, you have cookies in the oven”.

I think it's fine to underuse bell, especially if lots of watch faces do use it in that manner. Signal is kind of a versatile indicator that's useful in a lot of places, whereas bell is more specific.

joeycastillo, 2023-01-11:
I'm going to close this issue, as the transition from signal to bell for hourly chime seems to have gone over okay with folks. If there are other areas where indicator selection is causing confusion, feel free to reopen or start a discussion in the Discord.

Thanks for the feedback!

Closed 2023-01-11.

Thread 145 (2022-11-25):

Are the BOMs for the sensor boards?

danielzfranklin, 2022-11-25:
I couldn't find any sort of BOM for the sensor boards. Am I missing something, or is what specific component to use something I should figure out myself?

(I'm mainly interested in the hiking log board.)

tahnok, 2022-11-27:
I don't believe there are BOMs, you'll have to look at the schematic and
make your own (or maybe eagle can export one?)

On Fri, Nov 25, 2022, 17:34 Daniel Franklin ***@***.***>
wrote:

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

jackbondpreston, 2022-11-27:
Eagle can indeed export BOMs. For example, for the hiking log:
```
Partlist exported from C:/Users/jackb/Sensor-Watch/PCB/Sensor Boards/OSO-MISC-21-008 Hiking Log.sch at 27/11/2022 23:50

Part Value                 Device                Package                Description                                                                                    DESCRIPTION                                                              DIGI-KEY_PART_NUMBER DIGI-KEY_PURCHASE_URL                                                                                                                                     MF                 MP       PACKAGE          
C1   10µF                  CAP_CERAMIC_0402MP    _0402MP                Ceramic Capacitors                                                                                                                                                                                                                                                                                                                                                                                  
C2   0.1uF                 CAP_CERAMIC_0402MP    _0402MP                Ceramic Capacitors                                                                                                                                                                                                                                                                                                                                                                                  
R1   1% 10K                RESISTOR_0402MP       _0402MP                Resistors                                                                                                                                                                                                                                                                                                                                                                                           
RT1  NTC 10K               RESISTOR_0402MP       _0402MP                Resistors                                                                                                                                                                                                                                                                                                                                                                                           
U$3  FH19C-9S-0.5SH_10-FFC FH19C-9S-0.5SH_10-FFC FH19C9S05SH10-FFC                                                                                                                                                                                                                                                                                                                                                                                                          
U1   LIS2DHTR              LIS2DHTR              PQFN35P200X200X100-14N MEMS digital output motion sensor: ultra low-power high performance 3-axes femto accelerometer  Accelerometer X, Y, Z Axis ±2g, 4g, 8g, 16g 0.5Hz ~ 672Hz 14-LGA _2x2_  497-13795-1-ND       https://www.digikey.com/product-detail/en/stmicroelectronics/LIS2DHTR/497-13795-1-ND/4209308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 STMicroelectronics LIS2DHTR LGA-14 STMicroelectronics
```

note that `FH19C-9S-0.5SH_10-FFC` is not something you need as this is the watch-side connector for the sensor PCBs. so the only specific component you need is the `LIS2DHTR`, which you can google (or use the DigiKey link provided). the rest are fairly generic components, as long as you buy something fitting the specified package size, resistance/capacitance, etc.

joeycastillo, 2022-11-28:
So FYI, I haven't tested all of the boards in that folder. The project kind of migrated from "thing I'm hacking on" to "product that people use" without me doing a pass to clean up a lot of sort of draft work. Case in point: I never actually tested the Hiking Log board, as the LIS2DH was way too fine-pitched for me to place consistently. Instead I've moved on to using the LIS2DW. That accelerometer does technically have a temperature sensor inside, tho I haven't written code to make use of it yet or gotten a sense for its accuracy.

There's a tested design called Sensor Watch Motion II in there (OSO-MISC-21-021), and the BOM for that is just the LIS2DW and two 0603 capacitors (10µF and 100nF).

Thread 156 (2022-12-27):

GPS Sensor watch accessory board

Asalle, 2022-12-27:
First of all, thanks for this amazing project, it's high-key genius!

I wanted to ask if it's realistic to add a gps module, save gps data and offload it to a PC via usb(or somehow else)?

joeycastillo, 2022-12-28:
Hey and thanks for the kind words!

Unfortunately, a GPS module is unlikely to be a good fit for Sensor Watch. The antennas required for GPS reception are generally more bulky than could fit in the Casio watch enclosure, and even the most power efficient modules consume double digit milliamperes when getting a fix. For a device that has only 100 milliampere hours of energy to work with, this would kill the battery in a matter of days, instead of the year of battery life we get by sticking to the microampere range.

Hope this helps and sorry if it's not the answer you were hoping for!

Hein-NonesensE, 2023-01-22:
Just for the record, as I had the same thought and looked into it: I've found small package GPS sensors by u-blox that might just fit the watch, but only with a custom antenna. Some of these can operate in the single digit milliampere range in 1Hz power saving mode (don't know if that mode works right after cold start). Might just work when deactivated completely while GPS face not active, but requires a lot of work (as I said: Custom antenna etc). Maybe in a few years we'll see modules that are small and economical enough to simply drop in.

Closed 2022-12-28.

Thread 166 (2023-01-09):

movement_illuminate_led() mangles long press behavior

enthdegree, 2023-01-09:
`EVENT_LIGHT_LONG_UP` should happen when you release the light button after an `EVENT_LIGHT_LONG_PRESS`.
However, if you call `movement_illuminate_led()` when processing `EVENT_LIGHT_LONG_PRESS`, then when you release the button, a `EVENT_LIGHT_BUTTON_UP` happens instead.

Here is an example loop:

````
 bool test_face_loop(movement_event_t event, movement_settings_t *settings, void *context) {
    (void) settings;
    (void) context;
switch(event.event_type) {
        case EVENT_MODE_LONG_PRESS:
            movement_move_to_next_face();
            break;
        case EVENT_LIGHT_LONG_PRESS:
            movement_illuminate_led(); // If you comment out this line everything works properly
            watch_display_character('L', 4);
            watch_display_character(' ', 6);
            watch_display_character(' ', 7);
            break;
        case EVENT_LIGHT_LONG_UP:
            watch_display_character('L', 5);
            break;
        case EVENT_LIGHT_BUTTON_DOWN:
            watch_display_character('S', 6);
            break;
        case EVENT_LIGHT_BUTTON_UP:
            watch_display_character('S', 7);
            break;
        case EVENT_ALARM_BUTTON_UP:
            watch_display_string("    ", 4);
            break;
    }
}
````
-

TheOnePerson, 2023-01-11:
I think I found to source of this behavior: In `movement.c`, the function `movement_illuminate_led()` calls `_movement_enable_fast_tick_if_needed()`, which looks like this:
```
133    static inline void _movement_enable_fast_tick_if_needed(void) {
134        if (!movement_state.fast_tick_enabled) {
135            movement_state.fast_ticks = 0;
136            watch_rtc_register_periodic_callback(cb_fast_tick, 128);
137        }
138    }
```

The problem here is, that `_movement_enable_fast_tick_if_needed()` does not set `movement_state.fast_tick_enabled = true`. So each time this function is called, the fast_ticks counter is reset so zero. Since both the button long press timer *and* the timer for the led rely on fast_ticks, the timing for long pressing of a button gets messed up when you initiate the led.

The solution should be trivial: Just add a `movement_state.fast_tick_enabled = true` at line 135 and we should be good to go.

Could you perhaps test this with your build?

enthdegree, 2023-01-18:
Thank you for tracking this down @TheOnePerson . My test face has the expected behavior on your branch in #183 with the latest merged in from joeycastillo/Sensor-Watch:main ([5163cf1](https://github.com/joeycastillo/Sensor-Watch/commit/5163cf1fe1e8bf878bf8d4e54b1fa24dccb4e116)).

enthdegree, 2023-01-25:
I think that merge resolved it.

Closed 2023-01-25.

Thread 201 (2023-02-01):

Watch locked/frozen up on interval face

kingannoy, 2023-02-01:
My watch locked up today.

I asked for help on the [discord](https://discord.com/channels/969627287429459988/1070303222297792573) and was asked to write a bug report, so the problem could be tracked. I'm going to put in all the information that I think might be relevant.

It got in this state when I long pressed the alarm button on the interval face. I think I was on the 5th default alarm, with the 25/5 pomodoro timer. This was about 10 hours ago, and it's currently still in that state.

It is only showing the starting time of the break period on the interval face. Not counting down, no way to move away from there. This was the first time I was attempting to use this face, so I'm unsure if this is a fluke. I'll open up the watch and see if I can reproduce if I restart the watch without changing the code. I'll update when I know more.

I think this is the relevant bit of my `movement_config.h`:

```
const watch_face_t watch_faces[] = {
    simple_clock_face,
    alarm_face,
    stopwatch_face,
    interval_face,
    countdown_face,
    totp_face,
    day_one_face,
    thermistor_logging_face,
    thermistor_readout_face,
    weeknumber_clock_face,
    preferences_face,
    set_time_face,
};
```

It was built on a friends computer on 21 Jan.

I've not been able to reproduce this behavior in the emulator

Now that I've played with the emulator (and understand better what the interval face is supposed to do) I think it is interesting that it's locked up on the starting time of the "break" period. So not on the "work" period where it is supposed to start. I'm including a photo because think the state it got stuck in might contain a hint for someone that knows the code :sweat_smile:

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

kingannoy, 2023-02-01:
I have not been able to reproduce the behavior after a restart, so it seems like I was just unlucky somehow.

I also think I was wrong. In the emulator the interval I used was the fifth one. I think my friend may have changed this, or the interval face defaults may have changed in the past month. But on my watch the first timer is set to be the pomodoro (I've not changed the timers from how they were set in the image).

I've included some photo's of the settings I see on the interval that I think triggered the lock-up, in the order in which they show in the carousel:
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

That explains why the top and bottom right numbers are 1 and 4, because that is also how they show in the carousel. So not as much of a hint as I had thought or hoped...

TheOnePerson, 2023-02-04:
Oh, this look really odd, esp. the last picture showing the cool-down phase. First of all, there is no regular way of setting this to 22 seconds, since the settings mode counts in steps of five. Secondly the lower right hand corner is supposed to be blank - I wonder where the 6 comes from? It looks to me like the internal settings state has been messed up. By what? No clue so far...

TheOnePerson, 2023-02-04:
You mentioned on discord that your friend has made some (minor) modifications to the face's code for you. Could you send me the version of interval_face.c that you actually used for your watch?

kingannoy, 2023-02-21:
I wish I could, but my friend is not sure he still has this file, and hasn't found the time to search for it yet. So I think based on the pictures not looking like they should, we can close this issue and say that it was probably a bug introduced by the editing of the face.

Closed 2023-02-21.

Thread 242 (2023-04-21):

Clock running too fast

EmiliaBlasten, 2023-04-21:
My watch seems to gain about 30 seconds every couple of months. This makes the 2-factor authentication watch face useless unless I reset the time once or twice a month. The gain seems to be consistent but I haven't measured it.

Do others have the same issue?
- If yes it's probably due to the code.
- If not then the issue is likely due to manufacturing tolerances of the quartz resonator in which case (if it's a consistent gain for each resonator) we should create a calibration watch face or code.

DefProc, 2023-04-21:
I used to see a higher drift than that, but there's a very accurate calibration procedure now: https://www.sensorwatch.net/docs/watchfaces/nanosec/

neutralinsomniac, 2023-04-21:
Have you flashed a recent version of the firmware? The frequency correction offset was changed within the last couple months to bring the watch closer to an acceptable average drift. You don't need the nanosec face unless you want extremely accurate precision.

EmiliaBlasten, 2023-04-21:
Thanks! The version I have flashed is more than a few months old. I will try the new version (and also look at the nanosec watch face for curiosity) and report if there's any noticeable drift in a few months.

EmiliaBlasten, 2023-05-06:
So 15 days ago (when I posted the last comment), I synchronized the watch with the clock on my phone. I used the old firmware till today. Today the watch is 24 seconds in the future. I will now pull and install the latest firmware.

814d3, 2023-05-10:
I experienced the same behavior, also with a newer firmware (Jan/Feb '23). But finetune and nanosec do a fantastic job. Try them out and your watch will be very precise compared to not using them.

EmiliaBlasten, 2023-06-25:
It's been a around 50 days after synchronizing time on the new firmware. It's 11 seconds late compared to the phone's time. That's good enough for using 2-factor authentication. I will try nanosec / finetune next, when I have time.

annuvin, 2024-11-06:
my watch ran far too fast also, investigation of the ceramic capacitors on the quartz oscillator revealed one had been placed incorrectly making it out of circuit. i had to resolder it, it's quite tiny so if this is your issue i wish you good luck. my watch is dead accurate now.

EmiliaBlasten, 2024-11-07:
Forgot to close earlier. The issue was solved by upgrading to newer firmware.

Closed 2024-11-07.

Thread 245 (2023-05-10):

timer face only shows 5 of 9 presets

814d3, 2023-05-10:
Hi all and hi @TheOnePerson,

I'm using my Sensor Watch since Jan/Feb '23 without any changes in the firmware and without battery replacements and I recognized today, that I can only scroll from preset 1 to 5. After 5 it jumps to 1 again. I remember that I scrolled through all 9 presets one or two weeks ago.
I tried to do some adjustments of the given presets, hoping this could bring back all 9 presets, but it didn't. Is there anything I can do/try?
Thanks and greetings

TheOnePerson, 2023-05-10:
Hi @814d3, I guess this is just a handling issue: When you „scroll“ through the timers in normal mode by short pressing the alarm button, only those timers with a valid pre-set time will show up. Empty timers are not shown there. This is to avoid forcing the user pushing all the way through all nine timers when he/she, perhaps by accident, has pressed the alarm button once. When you are in settings mode (light button long press) and the timer number is blinking, you can cycle through all of the timers, whether set or unset.
Does this solve your problem?

TheOnePerson, 2023-05-10:
Yes, please do so! I cannot rule out the possibility of some strange edge cases causing a messing up of the stored timers. But for now, I will close this issue.

Closed 2023-11-19.

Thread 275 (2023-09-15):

hourly chime not working in standby mode

Niehztog, 2023-09-15:
Some time ago I flashed a new firmware to my sensor watch built directly from the up-to-date main branch. Since then the hourly chime is not working in standby mode. My watches buzzer is working fine, so it is not related to that. It must have been some of the commits from the last few months which broke the feature.

Can anyone running a more resent built of movement on his watch confirm this?

CarpeNoctem, 2023-09-15:
Hmm. I'm running a pretty fresh build. I'll enable the chime and comment back here later today.

CarpeNoctem, 2023-09-16:
I can confirm that my watch is missing these hourly chimes in LE mode as well. I'll check my other watch when I get home. Its firmware was compiled (by me) from source as well, but sometime earlier. If it doesn't have the issue, that could help narrow down when the issue crept in.

CarpeNoctem, 2023-09-17:
So I haven't made it home yet, but did another check out of curiosity. I set an alarm for a time during LE mode. Paying closer attention the second time, I confirmed that it actually wakes the watch up out of LE mode into normal mode. I'm not sure whether or not this used to be the case for the hourly chime, but may be worth noting.

fedpost, 2023-09-18:
I have had this issue for a while. It has been intermittent and I haven't cared enough to investigate or give it any further thought, but I can confirm it happens with my build as well.

Niehztog, 2023-09-21:
Commit c1580b356d16cc49db873b020d72465a5f8b3a45 replaced the function call that plays the hourly chime from [watch_buzzer_play_note](https://github.com/joeycastillo/Sensor-Watch/blob/main/watch-library/hardware/watch/watch_buzzer.c#L171-L180) with [watch_buzzer_play_sequence](https://github.com/joeycastillo/Sensor-Watch/blob/main/watch-library/hardware/watch/watch_buzzer.c#L75-L91).
`watch_buzzer_play_note` works in low energy mode, `watch_buzzer_play_sequence` obviously doesn't. (I tested that on my watch by reverting the change and the hourly chime worked again in low energy mode).

@TheOnePerson and @neutralinsomniac , does maybe one of you have an idea how we can get the beautiful custom hourly chime tunes from #209 working in low energy mode?

TheOnePerson, 2023-09-22:
As far as I know does neither of `watch_buzzer_play_note` or `watch_buzzer_play_sequence` work in LE mode.
Just from looking at the code:

The changes in the internal logic of `movement_play_signal` have led to tunes being played asynchronously. Consequently, the function returns immediately after initializing the buzzer, rather than waiting for the tune to finish playing. This means that the implementation here in [simple_clock_face.c](https://github.com/joeycastillo/Sensor-Watch/blob/bc9b4ce700d3f12adc0daceaa880e3d638df0c2b/movement/watch_faces/clock/simple_clock_face.c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) does not work as expected any more. When an hourly chime is to be played while the watch is in LE mode, it first enables the buzzer (which is good), initializes the sequence - and immediately after that the buzzer is disabled again (which is bad).

My take on this problem would be:

a) Restore `movement_play_signal()` to its former version, using `watch_buzzer_play_note` again. This approach would also maintain compatibility with other watch faces that rely on this function (e.g., `tomato_face.c` or `rpn_calculator_alt_face.c`). (However, we could consider whether playing a more elaborate hourly chime is appropriate in these contexts.)

b) Implement the hourly chime sequence directly in `simple_clock_face.c`, utilizing the callback functionality of `watch_buzzer_play_sequence` to control when the buzzer is disabled. This approach may provide more control over the chime's behavior and timing, ensuring it works as expected in LE mode.

What do you think, @neutralinsomniac ?

neutralinsomniac, 2023-09-22:
How about this approach? https://github.com/joeycastillo/Sensor-Watch/pull/283

I kinda like this since it pulls the sleep-specific code into its own function for easier use by the watch faces (they don't have to manually enable/disable the buzzer). I left the tunes code in movement instead of moving it into simple clock face so that other watch faces can opt-in to playing hourly tunes if they want.

TheOnePerson, 2023-09-22:
I like your approach, too @neutralinsomniac . This looks fine to me (haven't had a chance to test it yet).

neutralinsomniac, 2023-09-23:
Thinking about this further, what if we moved the `watch_is_buzzer_or_led_enabled()` call and appropriate buzzer enabled/disable logic into `movement_play_signal()` and `movement_play_tune()` so that these functions always "just work" and don't require a decision to be made in every watch face before calling these library functions?

neutralinsomniac, 2023-09-23:
I pushed this change into my MR if you want to see what it looks like

synthead, 2023-10-16:
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

I have built and flashed my red board with the latest main at 5c94111ea20e50cb9dab8f416603403185e933b3, and I can still reproduce this bug.  I have `SIGNAL_TUNE_ZELDA_SECRET` defined in `movement/movement_config.h`, if it matters.

814d3, 2023-11-07:
I can confirm, that the `SIGNAL_TUNE_DEFAULT` is not working, when the watch is in low energy mode. I am using the latest ([67be6af](https://github.com/joeycastillo/Sensor-Watch/commit/67be6affd3367c4f6c302a57fdb35fc2bda50ce6)) version. Only two short clicks are recognizable, but no signal.
I did not test timers or the alarm sound, when in LE mode, but probably they won't work either.
Greetings

WesleyAC, 2023-11-13:
My PR above fixes this for the default tune by using the legacy functions, but I started looking into fixing this for custom tunes as well. The gist of it is that the main problem is that we are immediately turning the TCC off, because `watch_buzzer_play_sequence` is async, so as soon as we call that, the watch face exits its loop and calls `watch_enter_sleep_mode` which calls `_watch_disable_all_peripherals_except_slcd` which calls `_watch_disable_tcc`. The fix is probably for movement to know when a sequence has been requested to be played, and in that case, turn off all peripherals except slcd and tcc.

However, even doing that doesn't get it quite working — when I ensure the TCC is enabled the whole time, the tune still sounds quiet and muted. My phone mic can't really pick it up well, but https://hack.wesleyac.com/tune_sleep_mode.aac and https://hack.wesleyac.com/tune_no_sleep_mode.aac show the difference. My guess is some kind of clock scaling difference but I need to track it down.

underscorephil, 2023-12-25:
I put this fix on my watch today. Will report back on any issues.

maxz, 2024-01-08:
This issue still persists (or returned) in the current head of the main branch (Commit `63d6bc6aa0ddf4cc1ce1918ef7650852a25e581b`.)

WesleyAC, 2024-01-09:
@maxz that's because the PR fixing it (#325) hasn't been merged in yet. should be very soon, but you can grab the code from that PR if you want a fix now.

maxz, 2024-01-10:
Ah, thank you for the update.

I was not sure about the current state with various reverts I encountered when trying to check what's actually merged right now and already though about band-aid fixing it myself in my local copy.

Closed 2024-01-12.

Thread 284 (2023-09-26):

LED always on

roguepullrequest, 2023-09-26:
LITE pcb the LED just stays full YELLOW. Pressing the Light button does turn off the GREEN for the set duration.

Am i missing some default value or something.

roguepullrequest, 2023-09-27:
I did use the color RED. Sadly the Green led has burnt out because it was on too long.

aronhegedus, 2023-09-27:
I hit this today, and `make COLOR=RED` worked for me. I have a red board.

roguepullrequest, 2023-10-05:
So i have use clean repo and still the same issue. I always make sure color is RED.
i even tried other machines to rebuild and still same issue.

The LED both green/red stay on.

joeycastillo, 2023-10-05:
To be clear, you're running `make COLOR=RED` (with both COLOR and RED in all capital letters)?

roguepullrequest, 2023-10-05:
> To be clear, you're running `make COLOR=RED` (with both COLOR and RED in all capital letters)?

Yup. Had to triple check my shell history to be sure but using `make COLOR=RED` to build.

Thanks for everything.

h6y3, 2023-10-07:
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

I ran into this issue as well. I did a make clean before I issued the make command and that did the trick for me.

theorangerider, 2023-12-17:
Seems like this issue can be closed?

WesleyAC, 2024-01-21:
Going to close this as it seems to be the `COLOR` issue? @roguepullrequest if you're still having problems, definitely open a new issue.

Closed 2024-01-21.

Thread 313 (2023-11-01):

WATCHBOOT drive not showing up on Windows 10

stolksdorf, 2023-11-01:
Tried plugging my sensor watch board (red) into two different Windows 10 machines, and no additional disk drives popped up. Double tapped the reset button, the led was pulsing red, and tried both usb orientations just in case.

Can you only flash firmware via a unix machine?

joeycastillo, 2023-11-01:
It should work from Windows, Mac or Linux. Have you double checked that your USB cable isn’t a charge-only cable?

stolksdorf, 2023-11-01:
I tried two different cables, but third time's a charm! The cable was definitely the problem, thanks for the assist.

BrianBinFL, 2023-11-01:
> I tried two different cables, but third time's a charm! The cable was definitely the problem, thanks for the assist.

Also note that it matters which direction you face the board when you plug it in to the cable. You have to ensure that the side of the board with the contacts is facing the inside edge of the connector that has contacts. I've talked to at least one person who did not realize that.

Closed 2023-11-01.

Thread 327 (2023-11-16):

Simple Watch Face Softlocked at Midnight w/ Hourly Chime Enabled

sntyj-dev, 2023-11-16:
I flashed firmware back on October 16th this year with only a few complications. I've also set the hourly chime to be the Zelda Tune.

This morning, when I went to look at my watch it is stuck on midnight from today. It has the animation like it is still in standby, but I cannot wake it with the normal Alarm button press.

This hasn't happened before, but the only thing that is different than normal is that I accidentally left the hourly chime on (typically I will keep that off, as I'm aware of issue #275  where the chime doesn't work in standby anyways.)

I have a few hours before I'm able to crack into the watch to pull the battery to reset. Is there something I should be dumping or checking?

WesleyAC, 2023-11-16:
If you wanted to give #325 a shot (it fixes the problem with the buzzer not working in LE mode), that would be useful — I'm curious if that would fix this or not, although it sounds like it isn't very reproducible, so it'd be hard to say for sure.

sntyj-dev, 2023-11-17:
Thank you for the suggestion. I've compiled new firmware from your fork, and will leave the hourly chime on overnight to see if it at least gets past midnight tonight.

I have copied the same modifications from my previous build into the new build. Specifically the `movement_config.h` and `totp_face.c` files.

While I won't share what I'm doing in `totp_face.c` for obvious reasons, I will share the parts of  my `movement_config.h`  config that are different for reference just in case:
```

const watch_face_t watch_faces[] = {
    simple_clock_face,
    timer_face,
    world_clock2_face,
    sunrise_sunset_face,
    thermistor_readout_face,
    totp_face,
    time_left_face,
    rpn_calculator_face,
    voltage_face,
    preferences_face,
    set_time_face,
    finetune_face,
    nanosec_face
};

#define MOVEMENT_NUM_FACES (sizeof(watch_faces) / sizeof(watch_face_t))

/* Determines what face to go to from the first face on long press of the Mode button.
 * Also excludes these faces from the normal rotation.
 * In the default firmware, this lets you access temperature and battery voltage with a long press of Mode.
 * Some folks also like to use this to hide the preferences and time set faces from the normal rotation.
 * If you don't want any faces to be excluded, set this to 0 and a long Mode press will have no effect.
 */
#define MOVEMENT_SECONDARY_FACE_INDEX (MOVEMENT_NUM_FACES - 8) // or (0)

/* Custom hourly chime tune. Check movement_custom_signal_tunes.h for options */
#define SIGNAL_TUNE_ZELDA_SECRET
#include "movement_custom_signal_tunes.h"
```

sntyj-dev, 2023-11-17:
Update on this. My original issue has been resolved probably, as it made it past midnight without freezing with the chime on. Thanks again!

However, the chime itself still doesn't technically work as it should in LE mode. I can hear faint clicks when the buzzer is supposed to kick off, but the actual tune doesn't happen. Not sure if that's helpful @WesleyAC

sntyj-dev, 2023-11-18:
New build with proper branch and edits in place, the chime does work as expected! Even in LE mode using the Zelda tune. Nice work.

As you said, the issue itself doesn't seem to be reproducible, so I'll close this out assuming that it has been worked out for now. Since I don't have anything else to try/troubleshoot. :shrug:

theorangerider, 2023-12-13:
I ran into the same issue and don't use totp, but do have the hourly chime with zelda. Thanks for the patch, @WesleyAC, I'll also give it a go.

theorangerider, 2023-12-13:
I wonder if the fact that it gets soft locked at midnight means it's conflicting with some other daily activity or default alarm.

Closed 2023-11-18.

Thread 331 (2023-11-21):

Sensor-Watch Lite temperature offset

drtrigon, 2023-11-21:
Dear Sensor-Watch Makers

Thanks for this nice and clever product. I quite like it!

While using it as a thermometer I found that the temperature reported is about +1°C compared to other thermometers palced close to it.

Is there a easy way e.g. using preferences to calibrate respective set the temperature offset such that it shows the correct temperature?

Thanks and Greetings

bricewge, 2023-12-04:
I can confirm, the sensor watch lite report higher temperature than the actual temperature even after leaving it away of a wrist for some time.

If some settings have to be adjusted, it's probably these:
https://github.com/joeycastillo/Sensor-Watch/blob/1b90a4a07a591c6f074eacb0f0dae9cabc7e0f90/watch-library/shared/driver/thermistor_driver.h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

BrianBinFL, 2023-12-12:
> I can confirm, the sensor watch lite report higher temperature than the actual temperature even after leaving it away of a wrist for some time.

Of course there will be some delay for the temperature of the sensor inside the watch to rise and fall in response to changes in the environmental temperature and/or the presence or absence of a warm wrist. But I have generally found the watches to respond rather quickly to on/off wrist - likely due to the fact that the watches aren't very thick and the case back is metal.

I have two watches in a laboratory incubator for some rate experiments and keep the "thermistor face" active on them. The temperature shown on the watches is generally within about 0.4 degrees Celsius of the temperature the incubator is set to, and of course some of that will be variances in the actual temperature as the incubator works to keep it constant.

drtrigon, 2024-10-11:
Would it be possible to add configuration to the temperature watch face? E.g. an offset value that can be set for adjustment?

bricewge, 2024-10-11:
A few months ago I tried to reproduce the issue again, but I wasn't, this time the temperature reported by the watch left on a desk for a few hours was in sync with other thermometer in the room. I didn't update it since my first test in December of last year.

A week ago, in the [second project update for the Sensor Watch Pro](https://www.crowdsupply.com/oddly-specific-objects/sensor-watch-pro/updates/fully-funded-in-under-a-week-also-a-tour-of-second-movement-the-new-community-firmware-fo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) I spotted this:

 > Things like cleaning up brittle ADC code for the temperature [...]

I didn't managed to find the commit(s) in question.

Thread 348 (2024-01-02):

TOTP no longer works as of 2 January 2024

matthewcmead, 2024-01-02:
I've had working a totp face since February 2023.  I haven't used the watch in a couple weeks for totp, and much to my surprise, it doesn't work today.  I've validated with another totp generator which has the same seeds that the values the watch is producing are different.  I used the watch for totp successfully three weeks ago.  The timezone is still set the same and the time is synchronized.

Any idea what might be going on?  Nothing's changed with the watch -- it's been sealed since I installed the firmware last February.

Thanks!

tahnok, 2024-01-02:
I think there was a bug in the timestamp calculation that was fixed, you
may want to see if upgrading your firmware fixes it

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

matthewcmead, 2024-01-03:
That did it.  Thanks!  Please feel free to close the issue.

joeycastillo, 2024-01-03:
I’d like to leave this issue open until I address it in the posted firmware images on sensorwatch.net

thanks so much to everyone for reporting and recognizing the issue!

EmilienCourt, 2024-01-07:
For completeness (and since I encountered this issue myself), this bug occurred on the 1st January of 2024, since it's a leap year and (as @tahnok pointed out) there was a bug in the timestamp calculation for those years.

The bug was raised [here](https://github.com/joeycastillo/Sensor-Watch/issues/261) and fixed [here](https://github.com/joeycastillo/Sensor-Watch/pull/262)

joeycastillo, 2024-01-09:
Thanks so much to everyone for identifying and addressing this bug, and sorry for being asleep at the wheel deploying the fix. As mentioned, this bug has been fixed in main; you will need to rebuild and reflash your board to get the fix.

I've also updated all the [prebuilt firmware images on sensorwatch.net](https://www.sensorwatch.net/docs/firmware/prebuilt/); while none of these firmware images contained the TOTP function, some contained [timers](https://github.com/joeycastillo/Sensor-Watch/issues/353) and [countdowns](https://github.com/joeycastillo/Sensor-Watch/issues/352) that were affected. Reflashing with an updated firmware image should address the issue folks were seeing as we entered this leap year.

Closed 2024-01-09.

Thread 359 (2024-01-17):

Watch Freezes at Midnight in LE

Dabaraboo, 2024-01-17:
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
I've woken up to find the sensor watch frozen at midnight a couple times, its unresponsive to an alarm press to wake, and the second ticker is still running. I'm wondering if anyone else has experienced this issue?
I've been using the unofficial firmware builder.

814d3, 2024-01-20:
How did you solve the issue? Was it because of an outdated firmware version?

Dabaraboo, 2024-01-22:
> How did you solve the issue? Was it because of an outdated firmware version?

Dabaraboo, 2024-01-22:
It may be solved with the updated firmware. closed the issue given the lack of relevant info I had.
Accidentally closed it again just now because I have no idea what i'm doing, lol

Closed 2024-01-22.

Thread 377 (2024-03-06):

timer_face sometimes no/aborted/quiet buzzing

814d3, 2024-03-06:
Hi there,

I use the timer_face regularly and recognized that sometimes it doesn't buzz after the time is over or if I start/stop and scroll through different presets.
What I can tell is that normal button pushes activate the buzzer normally. But when I use timer_face there is sometimes no beep. In addition there is no beep after the set timeout, when it switches back to simple_clock_face.

I'm not sure if I got it right, but there was one time I used timer_face but after the set time was over, there was no buzzing 5 times, but only 1 or 2 times. I can't  tell if the other 3-4 buzzes were just very quiet or nonexistent. But this reminded me of the general issue with the buzzer/hourly chime we had some weeks before.

matheusmoreira, 2024-03-08:
To me it sounds like there's a race condition in here somewhere. The watch face uses the following functions to activate the buzzer:

 - `watch_buzzer_play_note`
   - Synchronous
 - `watch_buzzer_play_sequence`
   - Asynchronous

They could get interrupted by ticks or user input. It's not immediately clear to me what's supposed to happen to the buzzer when that happens. It's possible that when we press buttons the buzzer state gets overwritten. What if that happens while it's in the middle of playing a sequence of notes? That operation probably gets cancelled.

The complexity of this project seems to be quickly approaching that of real time operating system.

814d3, 2024-03-09:
Well, I checked it again and I can somehow reproduce the behavior:
Just scroll through the presets fast and activate a timer and deactivate it afterwards (after ~1 second). (Maybe do it again) Then there is either no buzz/a short or aborted buzz or very quiet buzz when doing the above steps again.

But why it sometimes is not/very quiet buzzing if I just activate e.g. a 5 min. timer....idk

814d3, 2024-05-28:
I cleaned the buzzer contacts a while ago and somehow thought, that this has brought improvement. But I noticed it again: Set a 2 hours timer. After the time expired, there was only one really short buzz instead of 5 clear beeps...  :-(

814d3, 2024-06-29:
Thanks for your comment, so it seems to be no individual problem/cause. Hopefully someone could dive into it.
I'll try a W-59 to rule out that the cause lies with other hardware.

Closed 2024-08-05.

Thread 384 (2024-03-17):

Lite board fails to boot if too many totp codes are configured.

madhogs, 2024-03-17:
If, on the totp_face, I add more than just a few totp codes the watch fails to boot and doesn't display anything. I think this is to do with the new credentials configuration as I have the same credentials working on my other (also sensor watch lite) watch which is still on the old firmware.

I have created a branch here - https://github.com/joeycastillo/Sensor-Watch/compare/main...madhogs:Sensor-Watch:example-too-many-totp
The above has some example credentials that are the same length and number as the real ones i have. After building the above with 'make color=RED' and flashing the watch it no longer displays anything when the battery is connected. Reducing the list to 5 or less entries and it works again.

It always works when running in the emulator, it only fails on the physical watch, i wonder if it is some hardware limitation when converting these codes.

matheusmoreira, 2024-03-17:
I tested this on my watch with 5 entries. I suppose I was just under the limit. :(

Could it be running out of memory? In order to achieve that `CREDENTIAL` interface, I made the watch decode the base 32 strings at runtime. The TOTP LFS face works like that too so I thought it was OK. Now I'm assuming it's going to run into the same limitations you described. Looks like the impact on RAM usage was higher than expected...

There are some improvements I can make to both faces to immediately reduce memory usage: decoding the string every time the face activates instead of decoding them all at once during initialization. Can you help me test these fixes and confirm whether it resolves the issue?

The other alternative is to go back to storing the raw decoded byte arrays in the source code which in my opinion made the face very hard to use since web sites don't output that format. @maxz has submitted a Python script to generate those arrays from a separate file at compile time, we should probably make that a priority.

madhogs, 2024-03-17:
Not sure really how to even work out what is failing on the physical watch as the emulator works fine. I was also unable to get the lfs face to work on the physical watch too, could be related? In that case it would load the first two but the rest would not appear (possible i've done something wrong there though).

More than happy to test your changes if you have some ideas already on how to reduce the memory usage.

I definitely prefer not having to input the raw decodes bytes, but obviously if that works better/allow more credentials than happy to go back to that method.

matheusmoreira, 2024-03-17:
> More than happy to test your changes if you have some ideas already on how to reduce the memory usage.

Thanks!! I'm developing a hot patch right now, I'll post the branch here once it's compiling.

> I was also unable to get the lfs face to work on the physical watch too, could be related?

Yes. I used the same algorithm as the TOTP LFS face. That made it require more RAM.

> In that case it would load the first two but the rest would not appear (possible i've done something wrong there though).

That's weird. I expected the limitations to be around the same but TOTP LFS supports even less codes? I didn't touch the TOTP LFS face in the latest commits either, so I conclude this problem must have been there for a while now.

If the hot patch fixes the issue for you, I'll apply it to the LFS version as well.

> I definitely prefer not having to input the raw decodes bytes, but obviously if that works better/allow more credentials than happy to go back to that method.

Wish C had better compile time code generation support. Macros are extremely crude tools. Something like Zig's `comptime` would completely solve this.

Guess we'll have to make do with a Python script.

> Not sure really how to even work out what is failing on the physical watch as the emulator works fine.

QEMU would have been really useful right now. I need to figure out how to port the Sensor Watch board to it.

matheusmoreira, 2024-03-17:
Okay, I developed a hot patch which refactors the face's memory allocation.

https://github.com/matheusmoreira/sensor-watch/tree/totp-hot-patch

Please verify if it solves the problem. I'll submit a pull request immediately if it does.

madhogs, 2024-03-17:
That branch seems to fix the issue :+1: , was able to load the example codes from the above branch no problem.

I've only done a quick test as its quite late here, only checked it loaded, happy to test it more + check the values tomorrow.

Thanks for looking into this so quickly.

matheusmoreira, 2024-03-17:
Great! Thanks for testing!

maxz, 2024-03-18:
Oh boy. Unless you find another solution to the possible repeated runtime allocation (on a quick glance it at least does not seem to call malloc for the same entry twice but to use memset) and decoding I guess I would prefer for the solution in the main branch to be the one from my PR #356 which has to deal with the explicit key array but has very little runtime overhead.
I will at least maintain my own patch for my watch if this behaviour remains.

@joeycastillo also spoke out against runtime heap allocation within faces in the past (But I can't find the PR right now, it was some PR by @theAlexes so they might remember which one it was.)
In that particular case I think he accepted the allocation in the face's initialisier.

matheusmoreira, 2024-03-18:
@maxz I have eliminated the dynamic memory allocation. Now there is a single user overridable 128 byte buffer. Only the runtime decoding overhead remains which will also be eliminated when the Python script is integrated.

> Frankly I'd prefer a more complicated setup over increased battery usage.

Me too... But we are programmers. Users might not be comfortable with munging bytes and editing them into source code. The watch face's documentation also suggests using a web service to decode the bytes which could leak the secret. I really wanted to avoid the need for that.

> @joeycastillo also spoke out against runtime heap allocation within faces
> In that particular case I think he accepted the allocation in the face's initialisier.

Yes, [in the discord][joey]:

> fwiw I think it’s a best practice to avoid dynamic memory allocation outside of the watch face setup function. As it stands now (at least in the case where the watch is on-wrist and not plugged into USB) memory is only allocated once, at boot, and that doesn’t change until the battery dies. this feels good for the stability of the thing when it has to run for, y’know, two years

I agree with him and have therefore removed the dynamic memory allocation.

[joey]: https://discord.com/channels/969627287429459988/1029086310192918538/1216075700965212220

Closed 2024-03-31.

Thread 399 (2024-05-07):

How to get serial output from USB?

RubenSandwich, 2024-05-07:
I just got my sensor watch a week ago and have already started developing for it. ([I just finished creating a watch face](https://github.com/RubenSandwich/Sensor-Watch/commit/fa35b8bb77f687fdd0eba09a6d8e3b49e72ab272).)

I am now interested in using the accelerator data from the `lis2dw` to create a simple pedometer using [existing open source algorithms](https://github.com/nerajbobra/embedded_pedometer). However because getting accurate reading from this sensor requires the actual watch board, and not just he simulator, I am struggling to debug certain parts of my code.

So my question is, how do I get serial output from the watch board when plugged into it with USB? (So I can view my `printf` statements.)

wryun, 2024-05-11:
It should come up on your computer as a standard serial port when you connect it via USB, and you can use the terminal program of your choice to communicate with it.

What OS are you using?

By the way, if you got your sensor watch a week ago I'm guessing you got the sensor watch lite, so it doesn't have the port to add an accelerometer. Not sure if you've already hacked your way around this :)

(PS might be good to open this sort of thing in 'Discussions' next time)

RubenSandwich, 2024-05-13:
I was able to get serial output with minicom. I'm till new to embedded development, for forgiven my ignorance.

You're right that I have a sensor watch lite. When looking through the code I got confused between OSO-SWAT-B1 (the sensor watch lite board) and OSO-SWAB-B1-00 (the upcoming sensor board) which has the LIS2DW12TR accelerometer on it.

It does look like it _might_ be possible to wire the sensor watch lite to the LIS2DW12TR sensor board with the pins:
* 59 - SDA
P (as used in the original sensor watch, but unused on sensor watch lite)
* 60 - SCL (as used in the original sensor watch, but unused on sensor watch lite)
* 61 - A4 pad
* 64 - CS (as used in the original sensor watch, but unused on sensor watch lite)
* 3v - through debugging pins
* GND - through debugging pins

However, I think micro soldering to microcontrollers unused pins is currently beyond my soldering ability.

Closed 2024-05-13.

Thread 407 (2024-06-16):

Yellow LED constantly on for red board

rieck, 2024-06-16:
The yellow LED on my red board stays on continuously, which typically signals an incorrect firmware version (color). However, I have compiled the firmware correctly using `make COLOR=red`, and the watch is actuially functioning normally. The only issue is that the yellow LED remains lit. It’s not due to a short circuit from the case, as the LED remains on even when connected to USB. Does anyone have any ideas about what might be causing this?

joeycastillo, 2024-06-16:
Alas the issue is with uppercase vs lowercase: you have to `make COLOR=RED` for it to work.

Is there some make-fu we can use to make [these lines](https://github.com/joeycastillo/Sensor-Watch/blob/main/make.mk#L220) case insensitive? Or uppercase whatever the input is?

rieck, 2024-06-16:
Oh, thanks for the swift response!!

`COLOR := $(shell echo $(COLOR) | awk '{print toupper($$0)}')`

or

`COLOR := $(shell echo $(COLOR) | tr '[:lower:]' '[:upper:]')`

would be two options. They require the `shell` subcommand, which is not present in BSD make to my knowledge, and likely they both do not work on Windows.

wryun, 2024-06-16:
I think the best thing to do is to have it abort if the COLOR line has an unrecognised colour.

chris-v8, 2024-06-16:
or modify the makefile to skip the COLOR argument, and always run it with your watch colour

orhun, 2024-06-27:
I'm having the same issue. Is there way to turn this off for the pre-built firmware? Do I need to build the firmware with the flag?

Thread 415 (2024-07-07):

Battery drain

shmoun, 2024-07-07:
I have the green Sensor-Watch board and have been experiencing extreme battery drain ever since i first installed it in January 2023. I have done the following steps to troubleshoot the issue:

- Tried different battery brands: Panasonic, Varta and Duracell, all brand new and measured before install
- Removed thermistor
- Tried different screens
- Tried different housings
- With piezo contact soldered
- Without piezo contact soldered
- With another piezo metal contact soldered
- With another battery metal spring thing
- With only minimal faces (watch, volt, countdown, settings) and always latest clean main pulled

Every time the battery is down to ~1.5V within 60 to 70 days, then it will stop displaying things. If I leave it in longer it will end up at ~0V.

What other things can I try?

814d3, 2024-07-08:
Maybe you could measure the current that the controller/board is drawing?
The watch should run until ~2,2 V. What do you mean with 1,5 V?

shmoun, 2024-07-08:
Thanks for your suggestion! I will try to measure the current drawn and come back with a number.

> What do you mean with 1,5 V?

The ~1.5V reading i got from the voltage face, the lowest reading I got before the display went blank. It was already hovering around 2V a bit below and then a bit above. But when trying the light while in the voltage face it dived to 1.5V display blanking and never got back.

That was yesterday evening (17 hours ago).  Now I took out battery and it seems to have continued draining, my multi meter measures 0.10V

shmoun, 2024-07-08:
My cheap multimeter reading for 30 seconds after boot is as follows (multimeter set to 2000uA):
Boot -> 380
Wake operation -> varying rhytmically between 010, 012, 019

I didn't have the patience and steady hand to get to LE mode (yet)

814d3, 2024-07-08:
I remember runtime measurements done by Joey while testing and optimizing the green boards. Maybe you can find those and compare with your values.

shmoun, 2024-07-10:
Thank you @814d3

I found the Sensor-Watch discord and someone reporting what I'm seeing with the same board:
https://discord.com/channels/969627287429459988/1029086310192918538/1107111421940076555

>I'll dig up the message chain... in particular I (and I think another person) were observing fresh coin cells deplete in ~30 min to 1 hour (on the voltage face I saw the battery start well above 3V and quickly tank to, like, 2.7V, confirmed with multimeter)

I see that behavior, the battery starts at 3V and goes down in the first hour(s) to the 2.7V.

shmoun, 2024-07-16:
My battery drain issue is fixed \o/

Using a tiny USB magnifying camera I noticed a lot of chunky pieces of what i think is flux residue spreaded over the board. The biggest chunk was covering a large part of led. It was such a big piece that on previous inspections i thought it was some kind of hard epoxy cover to protect the led, but when carefully prying it with plastic tweezers it moved and was soft and rubbery. Very sticky too. I removed all the big blobs i could find from the board.

Battery drain has stopped, I can actually watch the battery recovering, voltage increasing since yesterday when i did the clean-up.

I included a picture of the LED blob after i already loosened it and moved it to the side of the LED.
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

nrob81, 2024-08-04:
Hello, I have the same problem now. I have my clock one week now and my first battery drained in ~6 days. Yesterday I replaced my battery. It has 3.30V, today the clocks voltage meter displayed 3.13V. I used custom FW with simple clock, sun times, moon phases, countdown, tomato, alarm, thermistor readout, voltage. today replaced it to prebuild FW Focus. Hope it helps. I did not find anything on my board with microscope.

Closed 2024-07-16.

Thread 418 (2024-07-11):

Watch resets every 2 days

sajingeo, 2024-07-11:
Here is my config and my watch resets every 2 days.

```
const watch_face_t watch_faces[] = {
    simple_clock_face,
    stopwatch_face,
    alarm_face,
    world_clock2_face,
    sunrise_sunset_face,
    counter_face,
    timer_face,
    totp_face,
    preferences_face,
    set_time_face,
    thermistor_readout_face,
    voltage_face
};
```
battery voltage is at 3.2 v (tried with the new battery - same issue).  I don't think it is a hardware issue, I have tried to apply some force on the watch to see if the power drops out or tried to recreate the resets with button press or motion. It only happens at night, since I always see the time reset first thing in the morning. So the reset is happening when I am not actively using the watch.

shmoun, 2024-07-13:
In the original F91W watches I've opened I have found a tiny piece of good quality double sided tape/sticky material keeping the battery in place. I put a piece of 3M double sided adhesive ~2mm width when installing fresh batteries.

Another thing to pay attention to is the little clips of the metal cover, are they really all settled over the plastic base? Since the fit of the board is tight, it needs some extra attention to fit the clips properly.

On the software side you can start with excluding watch faces one by one. Or start with the most minimal set of faces.

sajingeo, 2024-07-16:
Its fixed now... not exactly sure what fixed it here are all the steps.

1. Removed the tape under the battery and put a new one in
2. cleaned all the contacts with alcohol
3. removed the totp_face

Watch has been running for 3 days wihout any issues.

Closed 2024-07-16.

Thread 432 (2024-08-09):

VCC element

tomekskuta, 2024-08-09:
Hello 👋 I bought my sensor watch some time ago and i broke it 😬 I broke it during soldering the buzzer connector. probably temperature was too high. the sensor watch works correctly, but it drains battery really fast (it's empty in 1 hour). I made some debugging on the pcb elements and my suspicion goes to VCC element. now it has no resistance when I check it with multimeter. I am no good in electronics so I am not sure if it is accurate shot but it's all I have in my mind for now. Could you please give me some info about what element is used there? thanks in advance 🙌

BarsMonster, 2024-09-03:
VCC is power supply line - it's not an element.

Unfortunately, rough handling of buzzer can damage microcontroller pin, it apparently causes internal silicon damage. So full fix requires microcontroller replacement.

The only potential easier solution is disable all sounds (hourly chime, alarms e.t.c) and disabling buzzer pin in software - switching it to high impedance input state permanently. I am not sure if this partial fix is available as a patch.

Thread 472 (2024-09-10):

beep_face causes build failure

CarpeNoctem, 2024-09-10:
Testing out the next branch, and beep_face causes the build to fail for both firmware and for the simulator.

**Branch:** [next](https://github.com/joeycastillo/Sensor-Watch/tree/next)
**Revision:** [44b5434](https://github.com/joeycastillo/Sensor-Watch/commit/44b543421da5a310c53cc9c68bdd47c0eb2c9cf3)
**Board color:** GREEN

**Customizations:** Only adding the below faces list to movement_config.h
```
const watch_face_t watch_faces[] = {
    simple_clock_face,
    world_clock2_face,
    french_revolutionary_face,
    alarm_face,
    timer_face,
    stock_stopwatch_face,
    tachymeter_face,
    sunrise_sunset_face,
    moon_phase_face,
    minimal_clock_face, // Helping test these from next branch
    close_enough_clock_face,
    countdown_face,
    alarm_thermometer_face,
    beeps_face,
    higher_lower_game_face,
    thermistor_readout_face, // These last 6 via long press from simple_clock_face
    voltage_face,
    preferences_face,
    set_time_face,
    finetune_face,
    nanosec_face
};

```

**Hardware FW build errors:**
```
LD build/watch.elf
/usr/lib/gcc/arm-none-eabi/12.2.1/../../../arm-none-eabi/bin/ld: ./build/movement.o:(.rodata.watch_faces+0x104): undefined reference to `beeps_face_setup'
/usr/lib/gcc/arm-none-eabi/12.2.1/../../../arm-none-eabi/bin/ld: ./build/movement.o:(.rodata.watch_faces+0x108): undefined reference to `beeps_face_activate'
/usr/lib/gcc/arm-none-eabi/12.2.1/../../../arm-none-eabi/bin/ld: ./build/movement.o:(.rodata.watch_faces+0x10c): undefined reference to `beeps_face_loop'
/usr/lib/gcc/arm-none-eabi/12.2.1/../../../arm-none-eabi/bin/ld: ./build/movement.o:(.rodata.watch_faces+0x110): undefined reference to `beeps_face_resign'
Memory region         Used Size  Region Size  %age Used
      bootloader:          0 GB         8 KB      0.00%
             rom:      131760 B       240 KB     53.61%
          eeprom:          0 GB         8 KB      0.00%
             ram:       15824 B        32 KB     48.29%
collect2: error: ld returned 1 exit status
make: *** [../../rules.mk:27: build/watch.elf] Error 1

```

**Simulator build errors:**
```
[...]
HTML build-sim/watch.html
error: undefined symbol: beeps_face_activate (referenced by top-level compiled C/C++ code)
warning: Link with `-s LLD_REPORT_UNDEFINED` to get more information on undefined symbols
warning: To disable errors for undefined symbols use `-s ERROR_ON_UNDEFINED_SYMBOLS=0`
warning: _beeps_face_activate may need to be added to EXPORTED_FUNCTIONS if it arrives from a system library
error: undefined symbol: beeps_face_loop (referenced by top-level compiled C/C++ code)
warning: _beeps_face_loop may need to be added to EXPORTED_FUNCTIONS if it arrives from a system library
error: undefined symbol: beeps_face_resign (referenced by top-level compiled C/C++ code)
warning: _beeps_face_resign may need to be added to EXPORTED_FUNCTIONS if it arrives from a system library
error: undefined symbol: beeps_face_setup (referenced by top-level compiled C/C++ code)
warning: _beeps_face_setup may need to be added to EXPORTED_FUNCTIONS if it arrives from a system library
Error: Aborting compilation due to previous errors
emcc: error: '/usr/bin/node /usr/share/emscripten/src/compiler.js /tmp/tmp14ordblc.json' failed (returned 1)
make: *** [../../rules.mk:19: build-sim/watch.html] Error 1
emmake: error: 'make COLOR=GREEN' failed (returned 2)
```

CarpeNoctem, 2024-09-10:
Found it: It was added to movement_faces.h, but not to the Makefile. Adding it to the latter resolves this.

```
user@a34e984b5762:/tmp/Sensor-Watch/movement/make$ git diff Makefile
diff --git a/movement/make/Makefile b/movement/make/Makefile
index 42c3106..a310c99 100644
--- a/movement/make/Makefile
+++ b/movement/make/Makefile
@@ -68,6 +68,7 @@ SRCS += \
   ../watch_faces/demo/lis2dw_logging_face.c \
   ../watch_faces/demo/demo_face.c \
   ../watch_faces/demo/hello_there_face.c \
+  ../watch_faces/demo/beeps_face.c \
   ../watch_faces/complication/pulsometer_face.c \
   ../watch_faces/complication/day_one_face.c \
   ../watch_faces/complication/stopwatch_face.c \

```

Closed 2024-09-17.

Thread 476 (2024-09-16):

Leading-Zero 24hr Bugs

CarpeNoctem, 2024-09-16:
Branch: [next](https://github.com/joeycastillo/Sensor-Watch/tree/next)
Most recent revision tested & present: [c9cbb82](https://github.com/joeycastillo/Sensor-Watch/commit/c9cbb8216365b07b9d8d8a9aa7fd521639fc155b)
Board color: GREEN

**Issue 1:** When switching from 024hr mode to 12hr mode, there is a leftover leading zero in front of the hour. This goes away if the user goes back to the usual 24hr mode, then back to 12hr mode. Seems like it could be a stuck "pixel" due to the way simple_clock_face conserves power, except that this happens in both am/pm and an example of this happening includes going from 16:xx to 04:xx PM. (note that the first digit is 1, not 0.) This only appears to be happening in simple_time_face, and not in others such as set_time_face, alarm_face

**Issue 2:** 24hr Indicator missing from `alarm_face` when in 024h mode.

matheusmoreira, 2024-09-16:
1. Ah, I see what you mean. The clock faces try to conserve power by comparing timestamps and only drawing what has changed. They do not currently take into account whether the display mode has changed. I'll try to push a fix!

2. Understood, I'll track it down and put it in.

CarpeNoctem, 2024-09-16:
> 1. Ah, I see what you mean. The clock faces try to conserve power by comparing timestamps and only drawing what has changed. They do not currently take into account whether the display mode has changed. I'll try to push a fix!

Well, just don't go down too much of a rabbit hole on that one. As I said, it's changing a 1 to a 0, so I'm not sure it's simply a matter of it not updating that digit. (Because it is indeed updating it.) I'm not sure how the leading-zero bit works, but maybe one of the display conditions just isn't quite right?

Thanks for looking into it!

matheusmoreira, 2024-09-16:
The `024h` mode works by ensuring there are always 2 digits in the hours display. So instead of ` 1:00` it displays `01:00`.

The relevant display logic in the `simple_clock_face` is just this:

https://github.com/joeycastillo/Sensor-Watch/blob/c9cbb8216365b07b9d8d8a9aa7fd521639fc155b/movement/watch_faces/clock/simple_clock_face.c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

I believe the problem happens because it does not unset the `0` pixels in LCD position 4 when the watch is not configured to display it. So if the watch was in `024h` mode before and it is switched back to `24h` or `12h`, the pixels are not cleared, they remain there until the screen fully updates.

Simply adding an `else` clause to that `if` should at least partially solve the issue.

```C
if (set_leading_zero) {
    watch_display_string("0", 4);
} else {
    watch_display_string(" ", 4);
}
```

In the refactored `clock_face` I already handled that case by using `snprintf` which has built in support for the leading zero format:

https://github.com/joeycastillo/Sensor-Watch/blob/c9cbb8216365b07b9d8d8a9aa7fd521639fc155b/movement/watch_faces/clock/clock_face.c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

A problem remains though: the above lines will only run when a full screen update is done, which occurs only when the current hour changes.

https://github.com/joeycastillo/Sensor-Watch/blob/c9cbb8216365b07b9d8d8a9aa7fd521639fc155b/movement/watch_faces/clock/simple_clock_face.c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

https://github.com/joeycastillo/Sensor-Watch/blob/c9cbb8216365b07b9d8d8a9aa7fd521639fc155b/movement/watch_faces/clock/clock_face.c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

In order to fully resolve this issue, I will decompose those hours/minutes checks into actual bits of information in the clock's state structure: `hours_dirty` and `minutes_dirty`. The display code will simply check those bits instead of concerning itself with computing them. I'll add functions which compute whether the hours or minutes are dirty and set those bits. Finally, the problem will be fixed by simply setting `hours_dirty = true` when the user changes the display mode via the watch face iself, causing the face to redraw the hours in the new format.

Compared to all this I expect the `alarm_face` fix to be much simpler, if not a one liner.

matheusmoreira, 2024-09-16:
OK issue should be fixed. Turned out to be much simpler than I initially thought it would be.

When I read the code again, I realized there was no way to change the display mode from inside the face, the user must go to preferences screen. That causes a face activation when the user returns to the clock face. Activating the clock face resets the previous time value's bits to all ones which ensures a full repainting. That means the bug actually had nothing to do with what I described above.

The _real_ problem turned out to be the fact that there's a `24h_mode` bit and a `leading_0` bit, switching from 024h mode back to 12h mode cleared `24h_mode` but not `leading_0`, and only `leading_0` was being taken into account when the time came to decide whether to add a leading zero. Changing it to `24h_mode && leading_0` solved the problem, at least in the simulator.

I have also added the 24h indicator back to the alarm face. All issues should be resolved. Would appreciate further testing for confirmation.

CarpeNoctem, 2024-09-16:
I've just run through all my testing again, and can confirm that these two issues are fixed. Good job and thanks!

> and only `leading_0` was being taken into account when the time came to decide whether to add a leading zero. Changing it to `24h_mode && leading_0` solved the problem

Doh. This is exactly what I meant when I said _"but maybe one of the display conditions just isn't quite right?"_ in [my comment above](#issuecomment-2353350822). Sorry for not being clearer; it was very late at night here. >__<

Thanks again!

Closed 2024-09-17.

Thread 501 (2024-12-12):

battery drained in several days on sensorwatch light board

vagrantc, 2024-12-12:
I finally installed my sensorwatch light, but the battery only lasts maybe 3-4 days.

At first, I just had the default firmware, but have since tried some of the prebuilt images and also a custom image.

I just swapped in a fresh battery last night, which was reading over 3.2v when i installed it, but as of this morning, it is down to 3v.

The seconds display does change behavior which *might* indicate it is going to low-power/sleep mode, although there is constant activity on it... e.g. not displaying numbers, but displaying some segment changes every second.
so i am not sure how low power that actually is.

Any thoughts or suggestions?

joeycastillo, 2024-12-12:
No worries! Your battery is doing fine. It’s normal for the battery voltage to decline from 3.2 volts to 3 volts over the first few days. It’ll then remain at 2.9-3.0 volts for six to nine months — that’s the first half of the battery’s life — before beginning a decline to 2.9, 2.8 and then 2.7 volts; that’s the normal discharge curve for a 3 volt coin cell. Below 2.65 volts you’re living on borrowed time, but that shouldn’t happen for many, many months :)

The change in the seconds display is also normal: it’s the watch going into low energy mode, which by default happens after an hour without pressing any buttons. You can wake it up by pressing the bottom right button, and configure the low energy timeout in the “LE” settings screen.

vagrantc, 2024-12-13:
I did have the first battery drained down all the way to 0V, though I did not measure the voltage on that one at the start, as it was from a newly purchased watch... so I guess that is why I am a bit nervous.

That said, we'll see how long this new one lasts... if it doesn't plummet wildly outside of the curve you describe in the next couple days I guess I will know.

:)

Thanks!

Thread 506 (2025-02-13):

Screen displays odd data after red board swap

whyleyc, 2025-02-13:
I recently bought a red board and followed [the tutorial](https://www.youtube.com/watch?v=Zr0pKeC2VFU) to swap out the buzzer connector and board in place of a standard F-91W version, but ran into some issues after re-assembling the watch. Specifically the display does not show any meaningful data:

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

To rule out any firmware issues I haven't installed any custom software on there, just the base ["Movement Standard" for red boards](https://www.sensorwatch.net/docs/firmware/download/standard-red.uf2) (I have also tried installing custom firmware with the same resulta).

The LED works fine:

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

And it is able to scroll through "modes", but doesn't show anything of use when doing that. It also appears to be possible to put it into the mode to set the time (or some version of it!):

https://github.com/user-attachments/assets/3a1ce4bc-fc0a-499c-8b4f-d5a69af6b9e2

I swapped the standard F-91W board back in thinking it might be an issue with the display, but this works fine - I can see all the usual functions on the display exactly as before the swap.

Here is the board in various stages of construction in case anyone is able to spot anything odd in the way I'm putting it back together (or any defects in the board itself):

**Side 1:**
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

**Side 2 (with battery connector):**
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

**With case:**
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

**With battery:**
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

**Assembled Back:**
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

**Assembled Front:**
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

Does anyone know what could be causing this issue or how to resolve? Could it be a defective board?

whyleyc, 2025-02-13:
> You have used a counterfeit watch. They are not compatible with the sensor watch board.

I'm not so sure - the watch came with Casio tags and the standard Casio F-91W branded manual - what makes you think the watch is a counterfeit?

Yometalc, 2025-02-13:
The pink zebra strip and the issue you have with the LCD.  The counterfeits are very good now but there are tell tale signs when you know what to look for.  Where did you purchase it? I see you are in the UK, Argos sells genuine ones for £11…

whyleyc, 2025-02-13:
Replacing the watch worked - I grabbed a new one from Argos, popped the board into it and everything sprang into life, so it looks like the first watch was indeed a fake.

Thanks for your assistance @Yometalc !

Closed 2025-02-13.

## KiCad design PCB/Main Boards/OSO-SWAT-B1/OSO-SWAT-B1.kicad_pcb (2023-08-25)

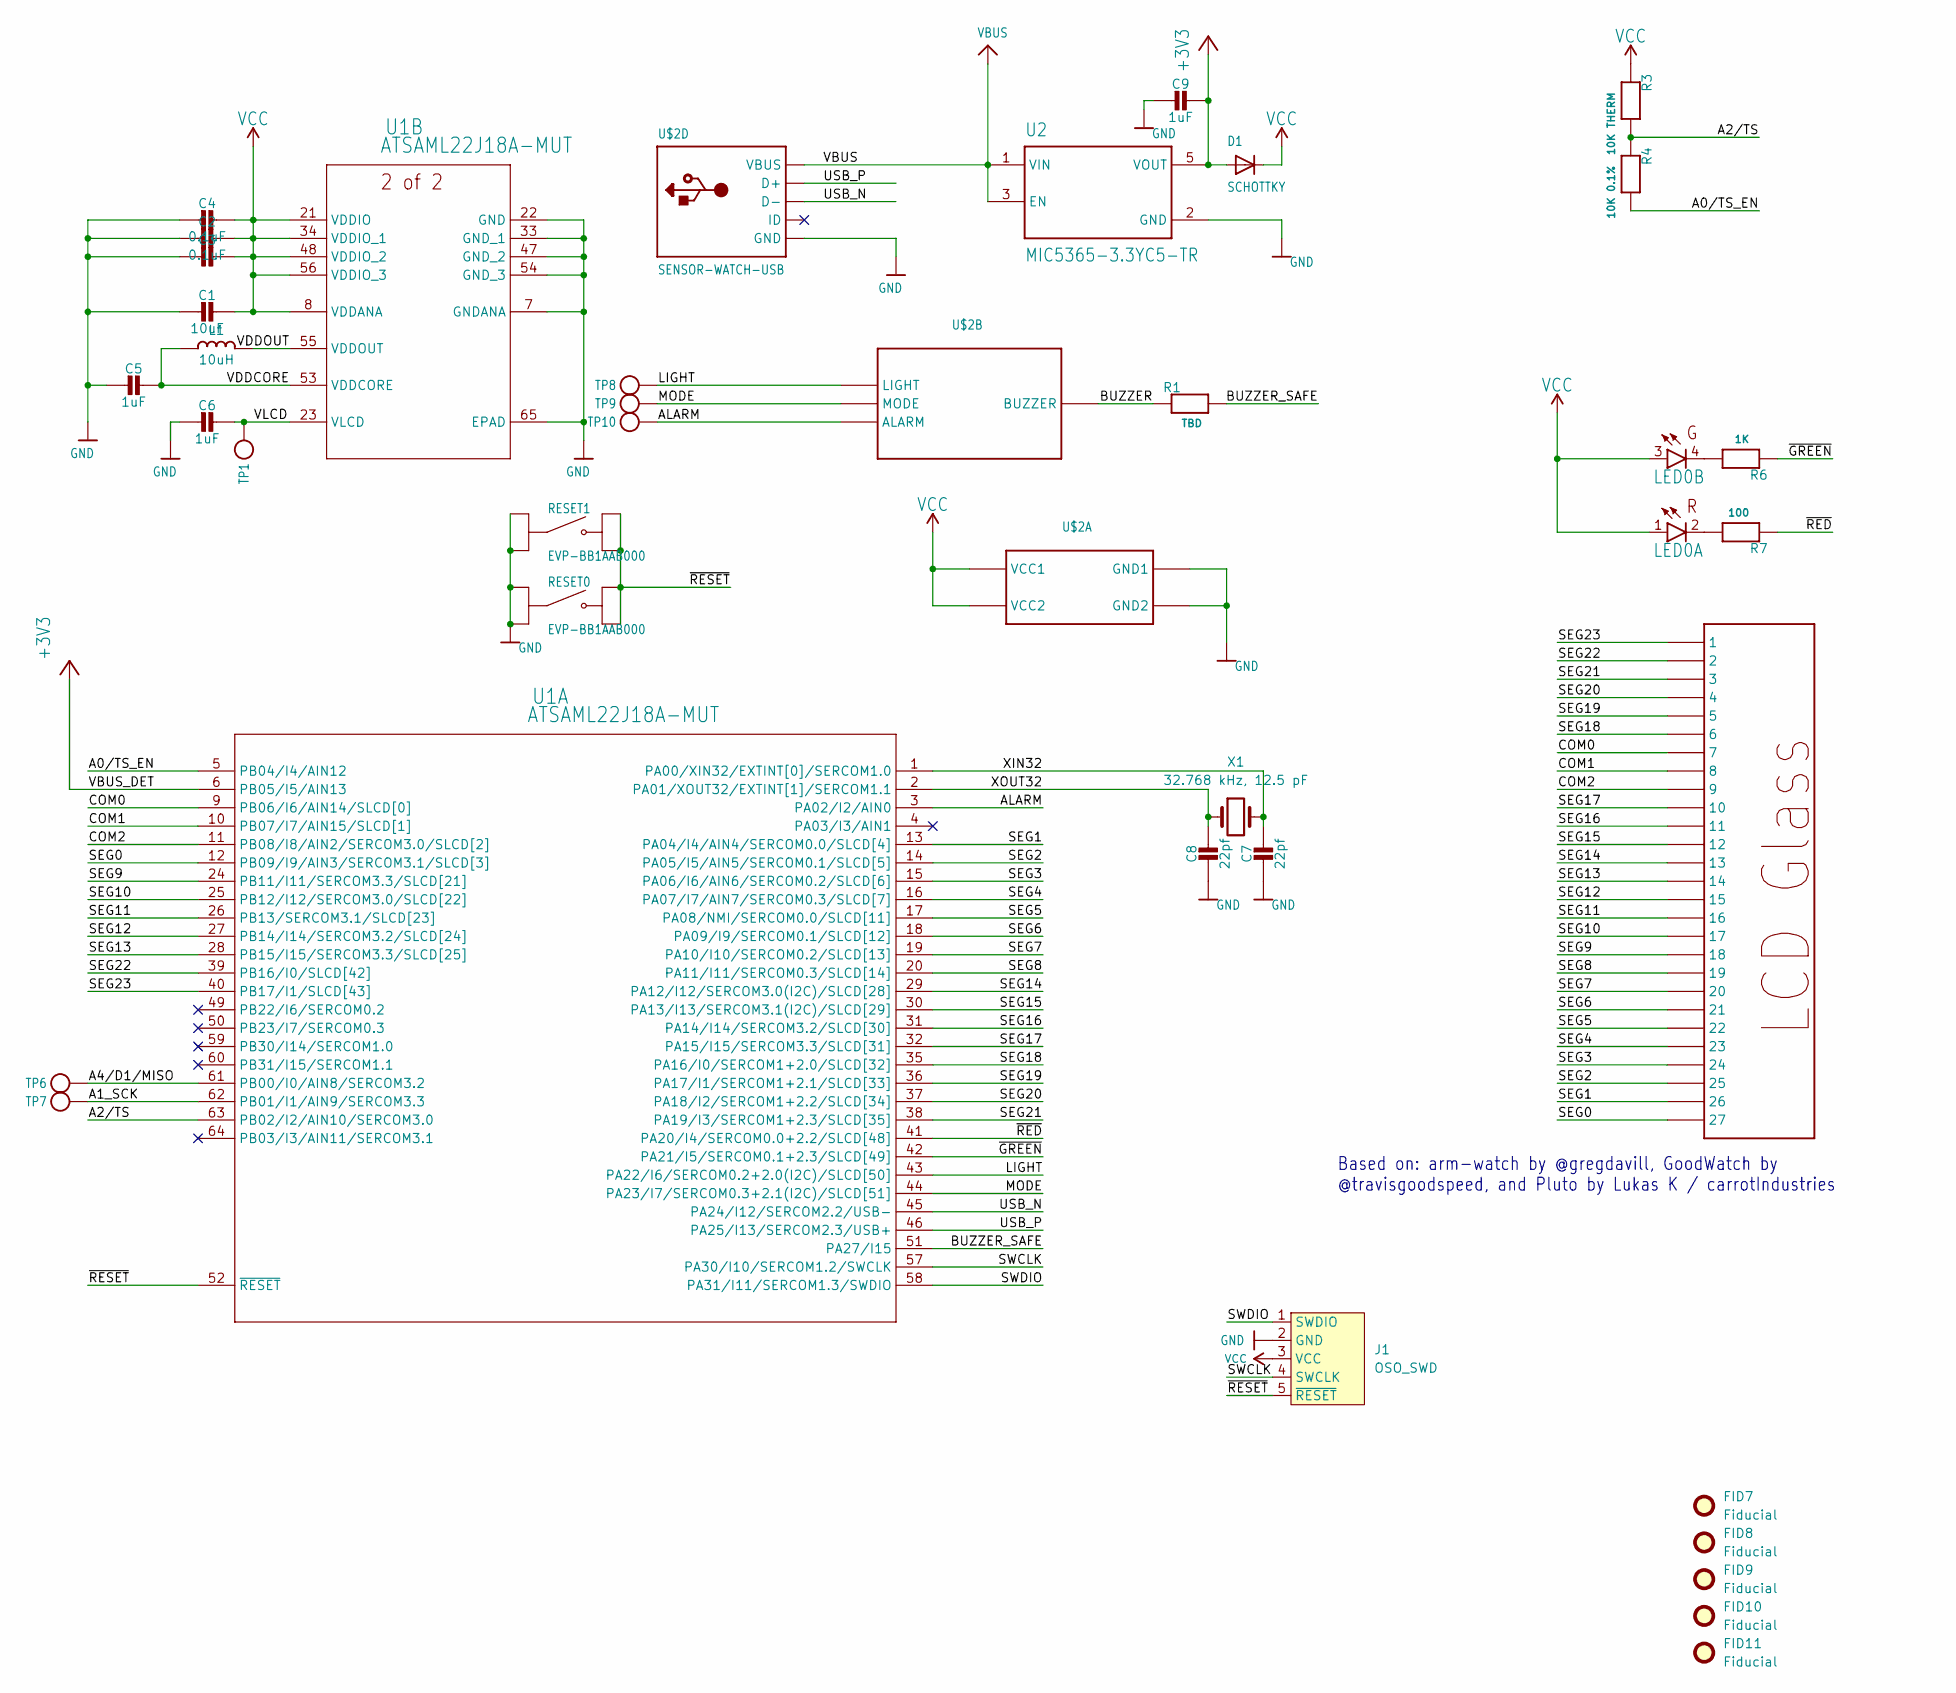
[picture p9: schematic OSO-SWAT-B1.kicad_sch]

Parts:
C1: 10uF; _0603MP
C2, C3, C4: 0.1uF; _0603MP
C5, C6, C9: 1uF; _0603MP
C7, C8: 22pf; _0402MP
D1: SCHOTTKY; SOD-323F
FID7, FID8, FID9, FID10, FID11: Fiducial; Fiducial_0.75mm_Mask1.5mm
J1: OSO_SWD; OSO_SWD_2x3
L1: 10uH; MICROBUILDER__0805MP
LED0: QBLP655-RIG; LED_QBLP655
R1: TBD; _0603MP
R3: 10K THERM; _0603MP
R4: 10K 0.1%; _0603MP
R6: 1K; _0603MP
R7: 100; _0603MP
RESET0, RESET1: EVP-BB1AAB000; SW_EVP-BB1AAB000
TP1, TP6, TP7, TP8, TP9, TP10: MICROBUILDER_TESTPOINTROUND1.5MM; MICROBUILDER_TESTPOINT_ROUND_1.5MM
U1: ATSAML22J18A-MUT; QFN64_9X9MC_MCH
U2: MIC5365-3.3YC5-TR; SOT65P210X110-5N
U$2: SENSOR-WATCH-USB; CASIO-F91W-OUTLINE-USB
X1: 32.768 kHz, 12.5 pF; Crystal_SMD_3215-2Pin_3.2x1.5mm

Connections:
+3V3: C9.1, D1.A, U1.6 (PB05/I5/AIN13), U2.5 (VOUT)
/A0/TS_EN: R4.2, U1.5 (PB04/I4/AIN12)
/A1_SCK: TP7.P$1, U1.62 (PB01/I1/AIN9/SERCOM3.3)
/A2/TS: R3.2, R4.1, U1.63 (PB02/I2/AIN10/SERCOM3.0)
/A4/D1/MISO: TP6.P$1, U1.61 (PB00/I0/AIN8/SERCOM3.2)
/ALARM: TP10.P$1, U1.3 (PA02/I2/AIN0), U$2.ALARM
/BUZZER: R1.1, U$2.BUZZER
/BUZZER_SAFE: R1.2, U1.51 (PA27/I15)
/COM0: U1.9 (PB06/I6/AIN14/SLCD[0]), U$2.7
/COM1: U1.10 (PB07/I7/AIN15/SLCD[1]), U$2.8
/COM2: U1.11 (PB08/I8/AIN2/SERCOM3.0/SLCD[2]), U$2.9
/LIGHT: TP8.P$1, U1.43 (PA22/I6/SERCOM0.2+2.0(I2C)/SLCD[50]), U$2.LIGHT
/MODE: TP9.P$1, U1.44 (PA23/I7/SERCOM0.3+2.1(I2C)/SLCD[51]), U$2.MODE
/SEG0: U1.12 (PB09/I9/AIN3/SERCOM3.1/SLCD[3]), U$2.27
/SEG1: U1.13 (PA04/I4/AIN4/SERCOM0.0/SLCD[4]), U$2.26
/SEG2: U1.14 (PA05/I5/AIN5/SERCOM0.1/SLCD[5]), U$2.25
/SEG3: U1.15 (PA06/I6/AIN6/SERCOM0.2/SLCD[6]), U$2.24
/SEG4: U1.16 (PA07/I7/AIN7/SERCOM0.3/SLCD[7]), U$2.23
/SEG5: U1.17 (PA08/NMI/SERCOM0.0/SLCD[11]), U$2.22
/SEG6: U1.18 (PA09/I9/SERCOM0.1/SLCD[12]), U$2.21
/SEG7: U1.19 (PA10/I10/SERCOM0.2/SLCD[13]), U$2.20
/SEG8: U1.20 (PA11/I11/SERCOM0.3/SLCD[14]), U$2.19
/SEG9: U1.24 (PB11/I11/SERCOM3.3/SLCD[21]), U$2.18
/SEG10: U1.25 (PB12/I12/SERCOM3.0/SLCD[22]), U$2.17
/SEG11: U1.26 (PB13/SERCOM3.1/SLCD[23]), U$2.16
/SEG12: U1.27 (PB14/I14/SERCOM3.2/SLCD[24]), U$2.15
/SEG13: U1.28 (PB15/I15/SERCOM3.3/SLCD[25]), U$2.14
/SEG14: U1.29 (PA12/I12/SERCOM3.0(I2C)/SLCD[28]), U$2.13
/SEG15: U1.30 (PA13/I13/SERCOM3.1(I2C)/SLCD[29]), U$2.12
/SEG16: U1.31 (PA14/I14/SERCOM3.2/SLCD[30]), U$2.11
/SEG17: U1.32 (PA15/I15/SERCOM3.3/SLCD[31]), U$2.10
/SEG18: U1.35 (PA16/I0/SERCOM1+2.0/SLCD[32]), U$2.6
/SEG19: U1.36 (PA17/I1/SERCOM1+2.1/SLCD[33]), U$2.5
/SEG20: U1.37 (PA18/I2/SERCOM1+2.2/SLCD[34]), U$2.4
/SEG21: U1.38 (PA19/I3/SERCOM1+2.3/SLCD[35]), U$2.3
/SEG22: U1.39 (PB16/I0/SLCD[42]), U$2.2
/SEG23: U1.40 (PB17/I1/SLCD[43]), U$2.1
/SWCLK: J1.4 (SWCLK), U1.57 (PA30/I10/SERCOM1.2/SWCLK)
/SWDIO: J1.1 (SWDIO), U1.58 (PA31/I11/SERCOM1.3/SWDIO)
/USB_N: U1.45 (PA24/I12/SERCOM2.2/USB-), U$2.USB_N (D-)
/USB_P: U1.46 (PA25/I13/SERCOM2.3/USB+), U$2.USB_P (D+)
/VDDCORE: C5.1, L1.1, U1.53 (VDDCORE)
/VDDOUT: L1.2, U1.55 (VDDOUT)
/VLCD: C6.1, TP1.P$1, U1.23 (VLCD)
/XIN32: C7.1, U1.1 (PA00/XIN32/EXTINT[0]/SERCOM1.0), X1.2
/XOUT32: C8.1, U1.2 (PA01/XOUT32/EXTINT[1]/SERCOM1.1), X1.1
/~GREEN: R6.1, U1.42 (PA21/I5/SERCOM0.1+2.3/SLCD[49])
/~RED: R7.1, U1.41 (PA20/I4/SERCOM0.0+2.2/SLCD[48])
/~RESET: J1.5 (~RESET), RESET0.B1, RESET0.B2, RESET1.B1, RESET1.B2, U1.52 (~RESET)
GND: C1.2, C2.2, C3.2, C4.2, C5.2, C6.2, C7.2, C8.2, C9.2, J1.2 (GND), RESET0.A1, RESET0.A2, RESET1.A1, RESET1.A2, U1.7 (GNDANA), U1.22 (GND), U1.33 (GND_1), U1.47 (GND_2), U1.54 (GND_3), U1.65 (EPAD), U2.2 (GND), U$2.GND, U$2.GND1, U$2.GND2
unnamed: LED0.2 (C), R7.2
unnamed: LED0.4 (C), R6.2
VBUS: U2.1 (VIN), U2.3 (EN), U$2.VBUS
VCC: C1.1, C2.1, C3.1, C4.1, D1.C, J1.3 (VCC), LED0.1 (A), LED0.3 (A), R3.1, U1.8 (VDDANA), U1.21 (VDDIO), U1.34 (VDDIO_1), U1.48 (VDDIO_2), U1.56 (VDDIO_3), U$2.VCC1, U$2.VCC2

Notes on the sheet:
Based on: arm-watch by @gregdavill, GoodWatch by @travisgoodspeed, and Pluto by Lukas K / carrotIndustries

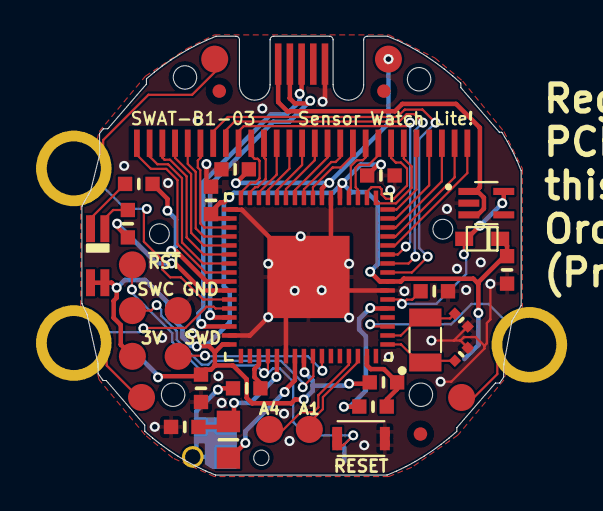
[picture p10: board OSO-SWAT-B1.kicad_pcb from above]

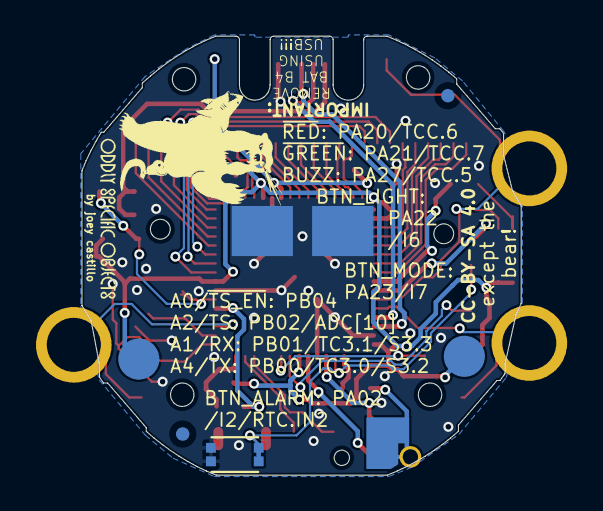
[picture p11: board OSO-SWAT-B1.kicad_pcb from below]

Board: 2 copper layers, 24.4 x 24.4 mm, 37 parts (5 on the bottom side), 54 nets.

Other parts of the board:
U$5: OSO_BEAR_250X360MIL_1000DPI
U$6: OSO_WORDMARK_ONELINE_350MIL_1000DPI

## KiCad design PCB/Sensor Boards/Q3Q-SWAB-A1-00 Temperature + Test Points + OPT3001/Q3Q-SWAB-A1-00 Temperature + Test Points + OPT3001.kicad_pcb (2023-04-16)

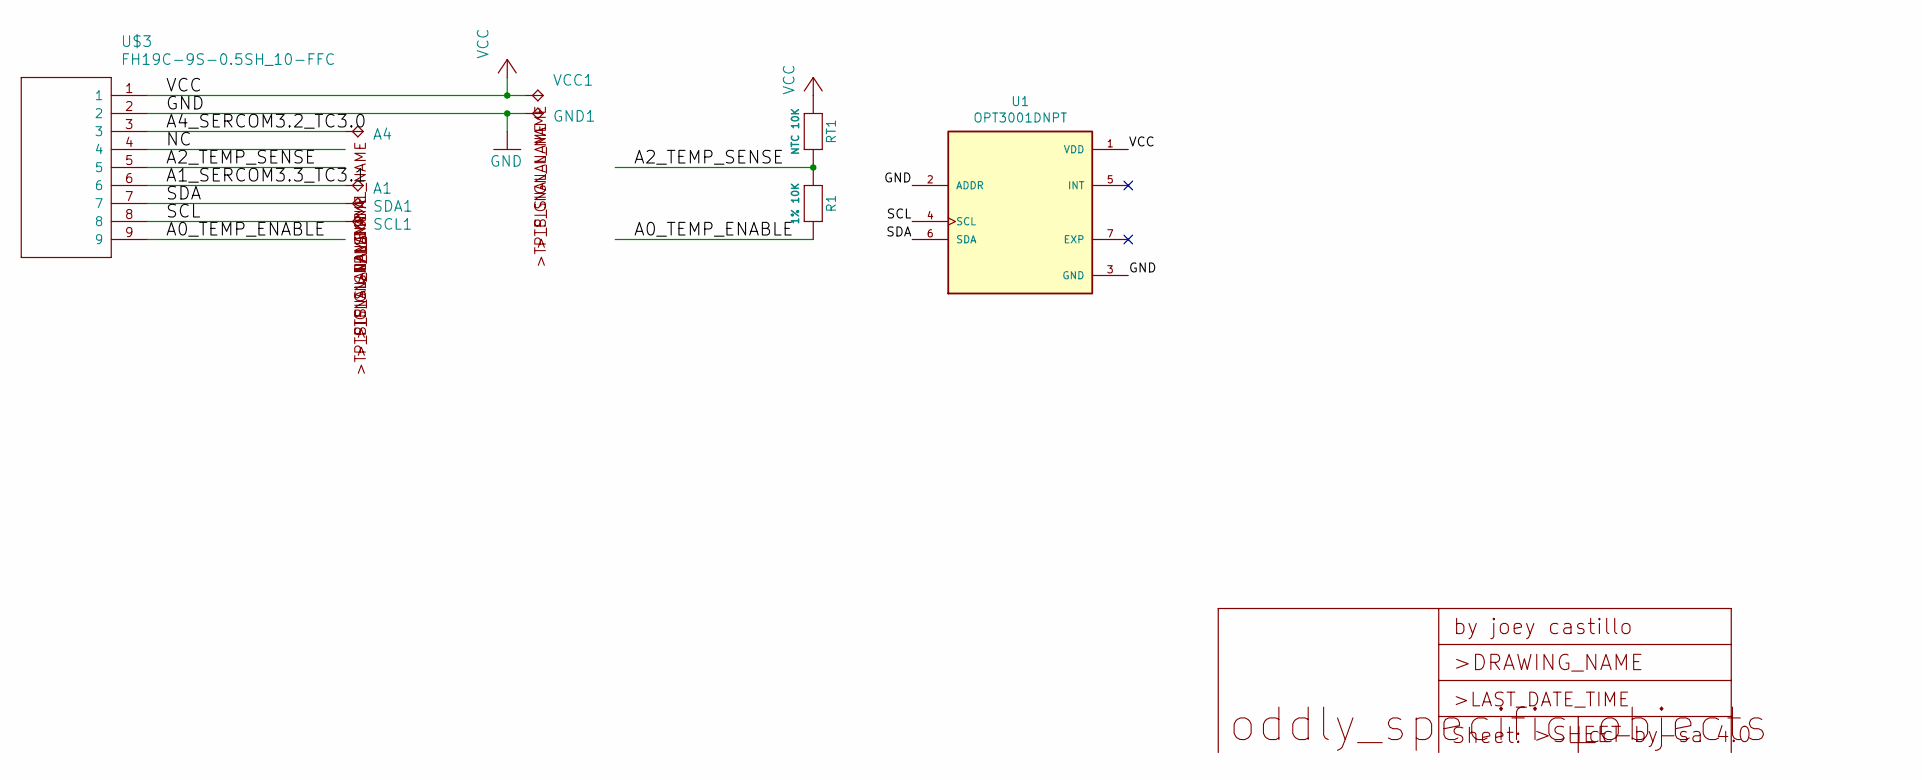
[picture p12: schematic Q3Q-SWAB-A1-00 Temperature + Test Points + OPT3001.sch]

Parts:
A1, A4: TPB1,27; B1,27
GND1: TPB1,27; B1,27
R1: 1% 10K; _0603MP
RT1: NTC 10K; _0603MP
SCL1: TPB1,27; B1,27
SDA1: TPB1,27; B1,27
U1: OPT3001DNPT; SON65P200X200X65-7N; PARTREV 01/2018
U$3: FH19C-9S-0.5SH_10-FFC; FH19C9S05SH10-FFC
VCC1: TPB1,27; B1,27

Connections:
/A0_TEMP_ENABLE: R1.2, U$3.9
/A1_SERCOM3.3_TC3.1: A1.TP, U$3.6
/A2_TEMP_SENSE: R1.1, RT1.2, U$3.5
/A4_SERCOM3.2_TC3.0: A4.TP, U$3.3
/NC: U$3.4
/SCL: SCL1.TP, U1.4 (SCL), U$3.8
/SDA: SDA1.TP, U1.6 (SDA), U$3.7
GND: GND1.TP, U1.2 (ADDR), U1.3 (GND), U$3.2
VCC: RT1.1, U1.1 (VDD), U$3.1, VCC1.TP

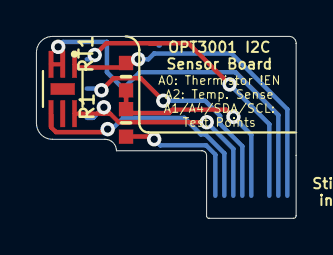
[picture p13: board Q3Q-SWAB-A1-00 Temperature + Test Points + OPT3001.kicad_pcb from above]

Board: 2 copper layers, 14.4 x 10.1 mm, 10 parts (0 on the bottom side), 8 nets.

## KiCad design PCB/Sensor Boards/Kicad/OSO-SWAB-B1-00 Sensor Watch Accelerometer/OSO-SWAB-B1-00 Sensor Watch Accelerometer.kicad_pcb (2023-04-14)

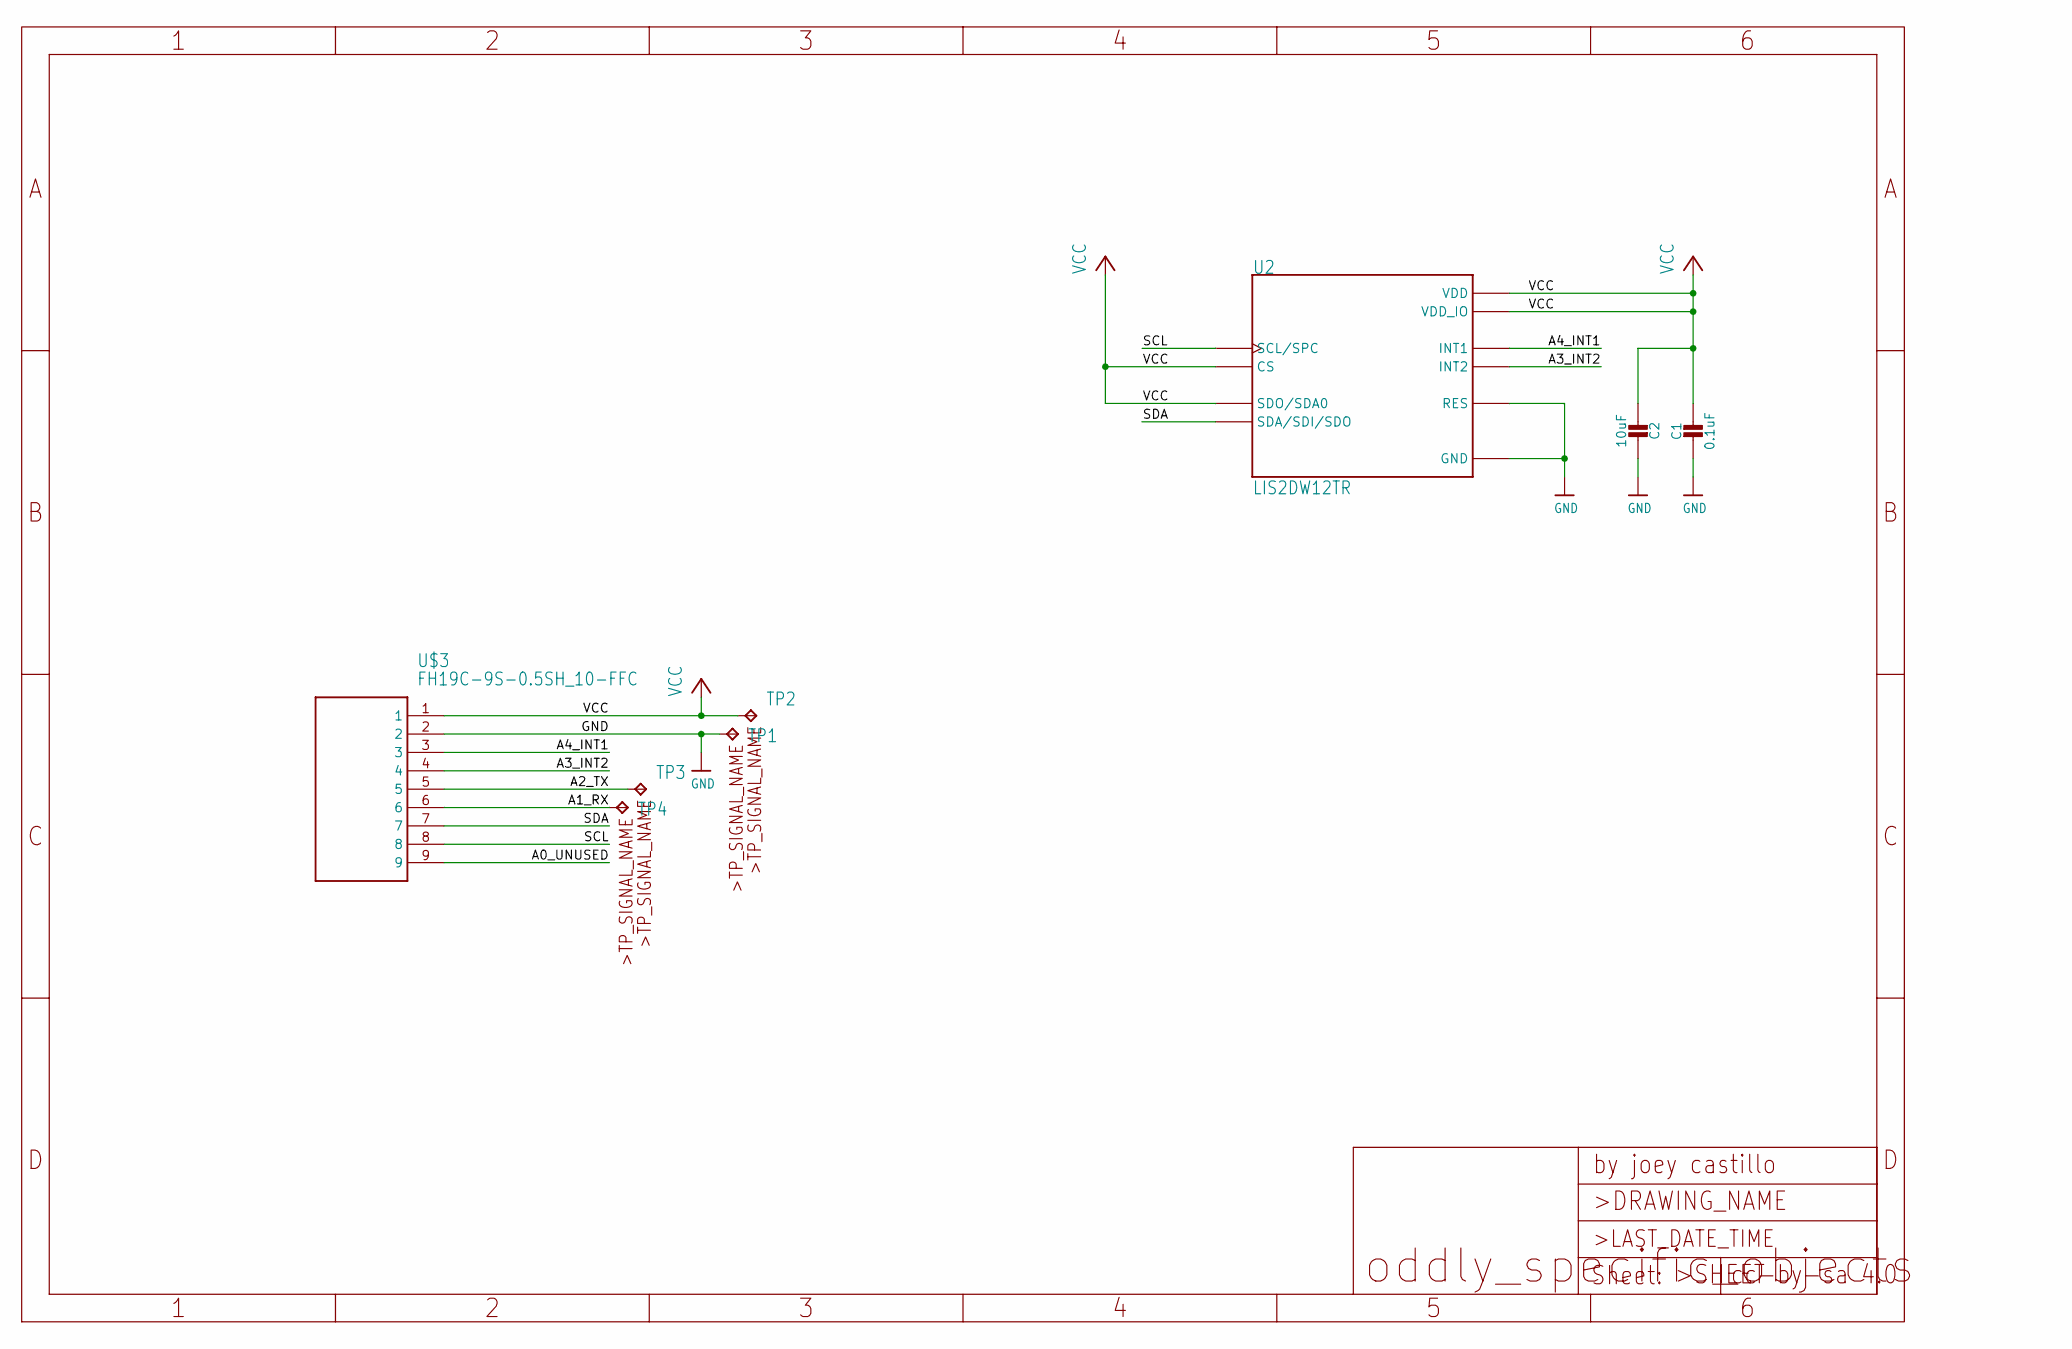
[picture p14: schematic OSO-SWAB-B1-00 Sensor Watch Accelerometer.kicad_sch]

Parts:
C1: 0.1uF; _0603MP
C2: 10uF; _0603MP
TP1, TP2, TP3, TP4: TPB1,27; B1,27
U2: LIS2DW12TR; LGA12R50P4X4_200X200X70
U$3: FH19C-9S-0.5SH_10-FFC; FH19C9S05SH10-FFC

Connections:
/A0_UNUSED: U$3.9
/A1_RX: TP4.TP, U$3.6
/A2_TX: TP3.TP, U$3.5
/A3_INT2: U2.11 (INT2), U$3.4
/A4_INT1: U2.12 (INT1), U$3.3
/SCL: U2.1 (SCL/SPC), U$3.8
/SDA: U2.4 (SDA/SDI/SDO), U$3.7
GND: C1.2, C2.1, TP1.TP, U2.6 (GND), U2.7 (RES), U2.8 (GND), U$3.2
VCC: C1.1, C2.2, TP2.TP, U2.2 (CS), U2.3 (SDO/SDA0), U2.9 (VDD), U2.10 (VDD_IO), U$3.1

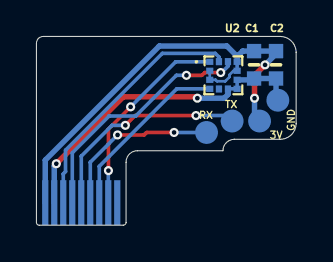
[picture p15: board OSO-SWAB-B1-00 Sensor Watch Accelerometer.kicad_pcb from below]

Board: 2 copper layers, 14.4 x 10.5 mm, 8 parts (7 on the bottom side), 8 nets.

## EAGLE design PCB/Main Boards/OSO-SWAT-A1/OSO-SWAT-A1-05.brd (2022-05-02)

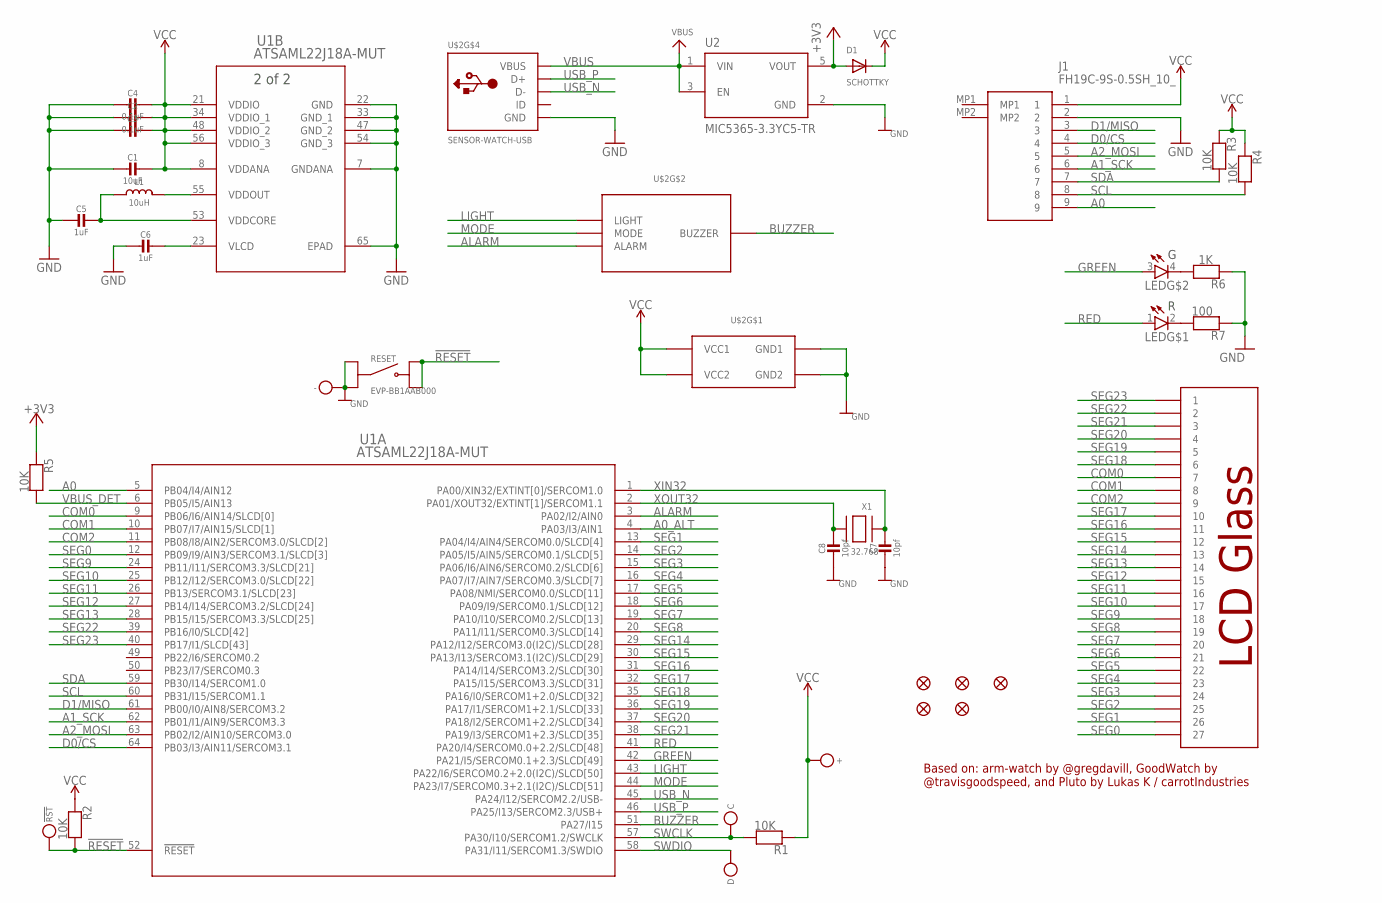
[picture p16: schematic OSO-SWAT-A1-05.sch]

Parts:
!RST: MICROBUILDER_TESTPOINTROUND1.5MM; MICROBUILDER_TESTPOINT_ROUND_1.5MM
+: MICROBUILDER_TESTPOINTROUND1.5MM; MICROBUILDER_TESTPOINT_ROUND_1.5MM
-: MICROBUILDER_TESTPOINTROUND1.5MM; MICROBUILDER_TESTPOINT_ROUND_1.5MM
C: MICROBUILDER_TESTPOINTROUND1.5MM; MICROBUILDER_TESTPOINT_ROUND_1.5MM
C1: 10uF; _0603MP
C2, C3, C4: 0.1uF; _0603MP
C5, C6: 1uF; _0603MP
C7, C8: 10pf; _0402MP
D: MICROBUILDER_TESTPOINTROUND1.5MM; MICROBUILDER_TESTPOINT_ROUND_1.5MM
D1: SCHOTTKY; SOD-323F
FID1, FID2, FID3, FID4, FID6: FIDUCIAL_1MM
J1: FH19C-9S-0.5SH_10_; FH19C9S05SH10
L1: 10uH; MICROBUILDER__0805MP
LED: QBLP655-RIG; LED_QBLP655
R1, R2, R3, R4, R5: 10K; _0603MP
R6: 1K; _0603MP
R7: 100; _0603MP
RESET: EVP-BB1AAB000; SW_EVP-BB1AAB000
U1: ATSAML22J18A-MUT; QFN64_9X9MC_MCH
U2: MIC5365-3.3YC5-TR; SOT65P210X110-5N
U$2: SENSOR-WATCH-USB; CASIO-F91W-OUTLINE-USB
X1: 32.768; XTAL3215

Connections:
!RESET: !RST.P$1, R2.2, RESET.B1, RESET.B2, U1.52 (!RESET)
+3V3: D1.A, R5.1, U2.5 (VOUT)
A0: J1.9, U1.5 (PB04/I4/AIN12)
A0_ALT: U1.4 (PA03/I3/AIN1)
A1_SCK: J1.6, U1.62 (PB01/I1/AIN9/SERCOM3.3)
A2_MOSI: J1.5, U1.63 (PB02/I2/AIN10/SERCOM3.0)
ALARM: U1.3 (PA02/I2/AIN0), U$2.ALARM
BUZZER: U1.51 (PA27/I15), U$2.BUZZER
COM0: U1.9 (PB06/I6/AIN14/SLCD[0]), U$2.7
COM1: U1.10 (PB07/I7/AIN15/SLCD[1]), U$2.8
COM2: U1.11 (PB08/I8/AIN2/SERCOM3.0/SLCD[2]), U$2.9
D0/CS: J1.4, U1.64 (PB03/I3/AIN11/SERCOM3.1)
D1/MISO: J1.3, U1.61 (PB00/I0/AIN8/SERCOM3.2)
GND: -.P$1, C1.2, C2.2, C3.2, C4.2, C5.2, C6.2, C7.2, C8.2, J1.2, R6.1, R7.1, RESET.A1, RESET.A2, U1.7 (GNDANA), U1.22 (GND), U1.33 (GND_1), U1.47 (GND_2), U1.54 (GND_3), U1.65 (EPAD), U2.2 (GND), U$2.GND, U$2.GND1, U$2.GND2
GREEN: LED.3 (A), U1.42 (PA21/I5/SERCOM0.1+2.3/SLCD[49])
LIGHT: U1.43 (PA22/I6/SERCOM0.2+2.0(I2C)/SLCD[50]), U$2.LIGHT
MODE: U1.44 (PA23/I7/SERCOM0.3+2.1(I2C)/SLCD[51]), U$2.MODE
unnamed: LED.4 (C), R6.2
unnamed: LED.2 (C), R7.2
RED: LED.1 (A), U1.41 (PA20/I4/SERCOM0.0+2.2/SLCD[48])
SCL: J1.8, R4.2, U1.60 (PB31/I15/SERCOM1.1)
SDA: J1.7, R3.2, U1.59 (PB30/I14/SERCOM1.0)
SEG0: U1.12 (PB09/I9/AIN3/SERCOM3.1/SLCD[3]), U$2.27
SEG1: U1.13 (PA04/I4/AIN4/SERCOM0.0/SLCD[4]), U$2.26
SEG2: U1.14 (PA05/I5/AIN5/SERCOM0.1/SLCD[5]), U$2.25
SEG3: U1.15 (PA06/I6/AIN6/SERCOM0.2/SLCD[6]), U$2.24
SEG4: U1.16 (PA07/I7/AIN7/SERCOM0.3/SLCD[7]), U$2.23
SEG5: U1.17 (PA08/NMI/SERCOM0.0/SLCD[11]), U$2.22
SEG6: U1.18 (PA09/I9/SERCOM0.1/SLCD[12]), U$2.21
SEG7: U1.19 (PA10/I10/SERCOM0.2/SLCD[13]), U$2.20
SEG8: U1.20 (PA11/I11/SERCOM0.3/SLCD[14]), U$2.19
SEG9: U1.24 (PB11/I11/SERCOM3.3/SLCD[21]), U$2.18
SEG10: U1.25 (PB12/I12/SERCOM3.0/SLCD[22]), U$2.17
SEG11: U1.26 (PB13/SERCOM3.1/SLCD[23]), U$2.16
SEG12: U1.27 (PB14/I14/SERCOM3.2/SLCD[24]), U$2.15
SEG13: U1.28 (PB15/I15/SERCOM3.3/SLCD[25]), U$2.14
SEG14: U1.29 (PA12/I12/SERCOM3.0(I2C)/SLCD[28]), U$2.13
SEG15: U1.30 (PA13/I13/SERCOM3.1(I2C)/SLCD[29]), U$2.12
SEG16: U1.31 (PA14/I14/SERCOM3.2/SLCD[30]), U$2.11
SEG17: U1.32 (PA15/I15/SERCOM3.3/SLCD[31]), U$2.10
SEG18: U1.35 (PA16/I0/SERCOM1+2.0/SLCD[32]), U$2.6
SEG19: U1.36 (PA17/I1/SERCOM1+2.1/SLCD[33]), U$2.5
SEG20: U1.37 (PA18/I2/SERCOM1+2.2/SLCD[34]), U$2.4
SEG21: U1.38 (PA19/I3/SERCOM1+2.3/SLCD[35]), U$2.3
SEG22: U1.39 (PB16/I0/SLCD[42]), U$2.2
SEG23: U1.40 (PB17/I1/SLCD[43]), U$2.1
SWCLK: C.P$1, R1.2, U1.57 (PA30/I10/SERCOM1.2/SWCLK)
SWDIO: D.P$1, U1.58 (PA31/I11/SERCOM1.3/SWDIO)
USB_N: U1.45 (PA24/I12/SERCOM2.2/USB-), U$2.USB_N (D-)
USB_P: U1.46 (PA25/I13/SERCOM2.3/USB+), U$2.USB_P (D+)
VBUS: U2.1 (VIN), U2.3 (EN), U$2.VBUS
VBUS_DET: R5.2, U1.6 (PB05/I5/AIN13)
VCC: +.P$1, C1.1, C2.1, C3.1, C4.1, D1.C, J1.1, R1.1, R2.1, R3.1, R4.1, U1.8 (VDDANA), U1.21 (VDDIO), U1.34 (VDDIO_1), U1.48 (VDDIO_2), U1.56 (VDDIO_3), U$2.VCC1, U$2.VCC2
VDDCORE: C5.1, L1.1, U1.53 (VDDCORE)
VDDOUT: L1.2, U1.55 (VDDOUT)
VLCD: C6.1, U1.23 (VLCD)
XIN32: C7.1, U1.1 (PA00/XIN32/EXTINT[0]/SERCOM1.0), X1.P$1
XOUT32: C8.1, U1.2 (PA01/XOUT32/EXTINT[1]/SERCOM1.1), X1.P$2

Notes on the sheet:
Based on: arm-watch by @gregdavill, GoodWatch by @travisgoodspeed, and Pluto by Lukas K / carrotIndustries

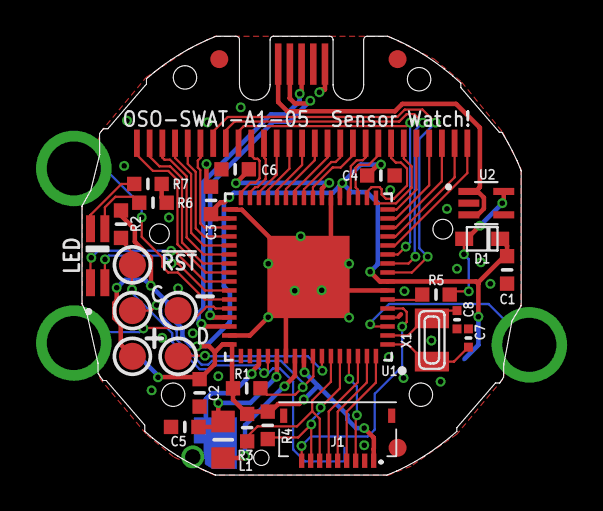
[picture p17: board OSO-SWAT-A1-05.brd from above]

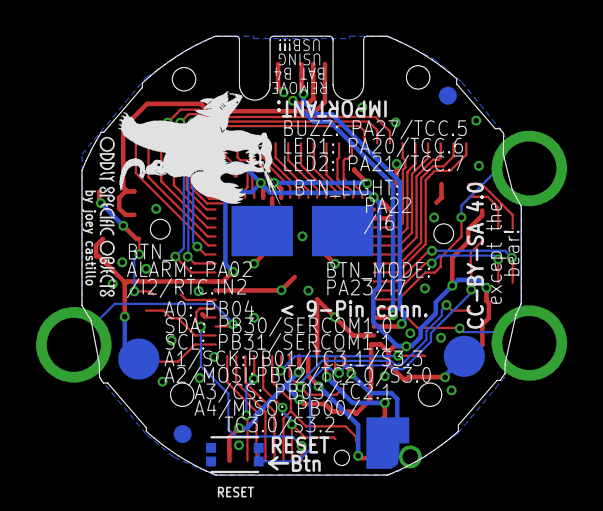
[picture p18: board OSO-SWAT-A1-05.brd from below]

Board: 2 copper layers, 24.4 x 24.4 mm, 36 parts (5 on the bottom side), 57 nets.

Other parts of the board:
U$5: OSO_BEAR_250X360MIL_1000DPI
U$6: OSO_WORDMARK_ONELINE_350MIL_1000DPI

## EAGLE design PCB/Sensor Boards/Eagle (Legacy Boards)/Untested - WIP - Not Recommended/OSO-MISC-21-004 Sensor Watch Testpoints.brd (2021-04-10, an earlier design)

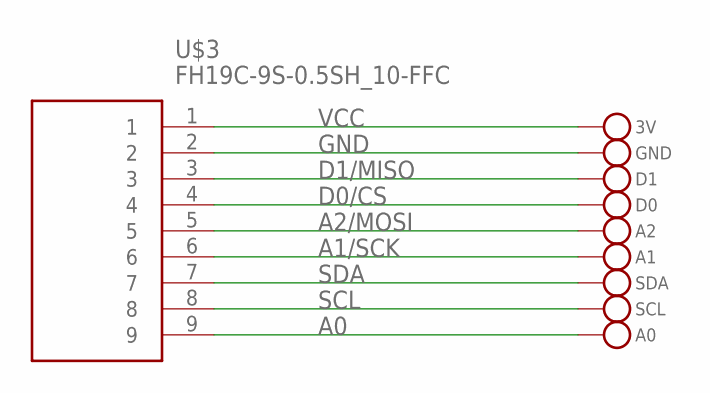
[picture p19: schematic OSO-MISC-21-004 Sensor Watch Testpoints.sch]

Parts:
3V: MICROBUILDER_TESTPOINT1.5X2.0MM_NOCREAM; MICROBUILDER_PAD-1.5X2.0
A0, A1, A2: MICROBUILDER_TESTPOINT1.5X2.0MM_NOCREAM; MICROBUILDER_PAD-1.5X2.0
D0, D1: MICROBUILDER_TESTPOINT1.5X2.0MM_NOCREAM; MICROBUILDER_PAD-1.5X2.0
GND: MICROBUILDER_TESTPOINT1.5X2.0MM_NOCREAM; MICROBUILDER_PAD-1.5X2.0
SCL: MICROBUILDER_TESTPOINT1.5X2.0MM_NOCREAM; MICROBUILDER_PAD-1.5X2.0
SDA: MICROBUILDER_TESTPOINT1.5X2.0MM_NOCREAM; MICROBUILDER_PAD-1.5X2.0
U$3: FH19C-9S-0.5SH_10-FFC; FH19C9S05SH10-FFC

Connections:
A0: A0.P$1, U$3.9
A1/SCK: A1.P$1, U$3.6
A2/MOSI: A2.P$1, U$3.5
D0/CS: D0.P$1, U$3.4
D1/MISO: D1.P$1, U$3.3
GND: GND.P$1, U$3.2
SCL: SCL.P$1, U$3.8
SDA: SDA.P$1, U$3.7
VCC: 3V.P$1, U$3.1

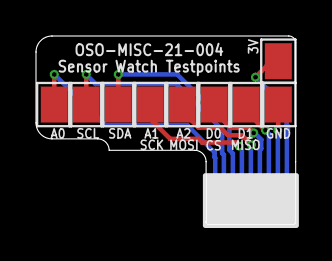
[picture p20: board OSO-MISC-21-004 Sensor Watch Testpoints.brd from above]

Board: 2 copper layers, 14.4 x 10.5 mm, 10 parts (0 on the bottom side), 9 nets.

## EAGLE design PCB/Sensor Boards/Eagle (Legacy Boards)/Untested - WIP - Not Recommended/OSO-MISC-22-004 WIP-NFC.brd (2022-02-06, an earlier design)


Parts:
C1: 1uF; _0603MP
U1: ST25DV64K-JFR8D3; UFDFPN12_3X3_STM
U$3: FH19C-9S-0.5SH_10-FFC; FH19C9S05SH10-FFC

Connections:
3.3V: C1.1, U1.10 (VDCG), U1.12 (VCC), U$3.1
AC0: U1.4 (AC0)
AC1: U1.5 (AC1)
GND: C1.2, U1.6 (VSS_2), U1.13 (VSS), U$3.2
INT: U1.11 (GPO(CMOS)), U$3.5
LPD: U1.1 (LPD), U$3.6
SCL: U1.8 (SCL), U$3.8
SDA: U1.7 (SDA), U$3.7


Board: 2 copper layers, 14.9 x 15.7 mm, 3 parts (2 on the bottom side), 6 nets.

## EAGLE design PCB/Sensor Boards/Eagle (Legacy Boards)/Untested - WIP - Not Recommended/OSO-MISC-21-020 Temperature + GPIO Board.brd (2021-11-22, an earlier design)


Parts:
A4: TPB1,27; B1,27
GND: TPB1,27; B1,27
R1: 1% 10K; _0603MP
RT: NTC 10K; _0603
U$3: FH19C-9S-0.5SH_10-FFC; FH19C9S05SH10-FFC
VCC: TPB1,27; B1,27

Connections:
A0_TEMP_ENABLE: R1.2, U$3.9
A2: U$3.6
A2_TEMP_SENSE: R1.1, RT.2, U$3.5
A3: U$3.4
A4_SERCOM3.2_TC3.0: A4.TP, U$3.3
GND: GND.TP, U$3.2
SCL: U$3.8
SDA: U$3.7
VCC: RT.1, U$3.1, VCC.TP


Board: 2 copper layers, 14.4 x 10.1 mm, 6 parts (5 on the bottom side), 5 nets.

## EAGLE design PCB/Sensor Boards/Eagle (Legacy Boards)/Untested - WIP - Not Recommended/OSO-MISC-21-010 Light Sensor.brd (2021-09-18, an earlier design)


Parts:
C1: 1uF; _0603MP
U1: TSL2591; DFN6_TAOS
U$3: FH19C-9S-0.5SH_10-FFC; FH19C9S05SH10-FFC

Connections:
3.3V: U$3.1
BOARD_POWER: C1.1, U1.5 (VDD), U$3.9
GND: C1.2, U1.3 (GND), U$3.2
INT: U1.2 (INT), U$3.5
SCL: U1.1 (SCL), U$3.8
SDA: U1.6 (SDA), U$3.7


Board: 2 copper layers, 14.4 x 10.5 mm, 3 parts (0 on the bottom side), 5 nets.

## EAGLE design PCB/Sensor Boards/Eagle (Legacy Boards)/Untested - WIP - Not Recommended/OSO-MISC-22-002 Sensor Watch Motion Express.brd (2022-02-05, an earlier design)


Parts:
C1: 0.1uF; _0603MP
C2: 10uF; _0603MP
R1: 10K; _0603MP
U1: 2MB Flash; USON8
U2: LIS2DW12TR; LGA12R50P4X4_200X200X70
U$3: FH19C-9S-0.5SH_10-FFC; FH19C9S05SH10-FFC

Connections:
A0_INT1: U2.12 (INT1), U$3.9
A1_SCK: U1.6 (SCK), U$3.6
A2_MOSI: U1.5 (MOSI), U$3.5
A3_CS: R1.2, U1.1 (SSEL), U$3.4
A4_MISO: U1.2 (MISO), U$3.3
GND: C1.2, C2.1, U1.4 (VSS), U2.6 (GND), U2.7 (RES), U2.8 (GND), U$3.2
SCL: U2.1 (SCL/SPC), U$3.8
SDA: U2.4 (SDA/SDI/SDO), U$3.7
VCC: C1.1, C2.2, R1.1, U1.3 (WP#/IO2), U1.7 (HOLD#/IO3), U1.8 (VCC), U2.2 (CS), U2.3 (SDO/SDA0), U2.9 (VDD), U2.10 (VDD_IO), U$3.1


Board: 2 copper layers, 14.4 x 10.6 mm, 6 parts (5 on the bottom side), 9 nets.

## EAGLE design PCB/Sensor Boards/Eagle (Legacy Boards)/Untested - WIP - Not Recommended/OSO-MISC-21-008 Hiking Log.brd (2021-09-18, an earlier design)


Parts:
C1: 10µF; _0402MP
C2: 0.1uF; _0402MP
R1: 1% 10K; _0402MP
RT1: NTC 10K; _0402MP
U1: LIS2DHTR; PQFN35P200X200X100-14N
U$3: FH19C-9S-0.5SH_10-FFC; FH19C9S05SH10-FFC

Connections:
3.3V: C1.1, C2.2, U1.3 (SD0/SA0), U1.4 (CS), U1.7 (VDD_IO), U1.8 (VDD), U$3.1
GND: C1.2, C2.1, R1.2, U1.9 (GND), U1.10 (RES), U1.11 (RES), U1.12 (RES), U1.13 (RES), U1.14 (RES), U$3.2
INT1: U1.6 (INT1), U$3.3
INT2: U1.5 (INT2), U$3.5
SCL: U1.1 (SCL/SPC), U$3.8
SDA: U1.2 (SDA/SDI/SDO), U$3.7
THERM_PWR: RT1.1, U$3.4, U$3.9
TSENSE: R1.1, RT1.2, U$3.6


Board: 2 copper layers, 14.4 x 10.5 mm, 6 parts (5 on the bottom side), 8 nets.

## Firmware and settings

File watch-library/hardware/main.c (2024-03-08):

/*
 * MIT License
 *
 * Copyright (c) 2021 Joey Castillo
 *
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
 * THE SOFTWARE IS PROVIDED "AS IS", WITHOUT WARRANTY OF ANY KIND, EXPRESS OR
 * IMPLIED, INCLUDING BUT NOT LIMITED TO THE WARRANTIES OF MERCHANTABILITY,
 * FITNESS FOR A PARTICULAR PURPOSE AND NONINFRINGEMENT. IN NO EVENT SHALL THE
 * AUTHORS OR COPYRIGHT HOLDERS BE LIABLE FOR ANY CLAIM, DAMAGES OR OTHER
 * LIABILITY, WHETHER IN AN ACTION OF CONTRACT, TORT OR OTHERWISE, ARISING FROM,
 * OUT OF OR IN CONNECTION WITH THE SOFTWARE OR THE USE OR OTHER DEALINGS IN THE
 * SOFTWARE.
 */

//-----------------------------------------------------------------------------
#include <stdlib.h>
#include <stdint.h>
#include <stdbool.h>
#include <string.h>
#include <stdio.h>
#include "saml22.h"
#include "hal_init.h"
#include "watch.h"
#include "tusb.h"

int main(void) {
    // ASF code. Initialize the MCU with configuration options from Atmel Studio.
    init_mcu();

    // check if we are plugged into USB power.
    watch_enable_digital_input(VBUS_DET);
    watch_enable_pull_down(VBUS_DET);
    if (watch_get_pin_level(VBUS_DET)) {
        // if so, enable USB functionality.
        _watch_enable_usb();
    }
    watch_disable_digital_input(VBUS_DET);

    // initialize the delay driver before any user code is called.
    delay_driver_init();

    // User code. Give the app a chance to initialize its data structures and state.
    app_init();

    // If the RTC is already enabled, we're either waking from BACKUP mode or a reset.
    // Ideally we should check if the TAMPER or CMP0 (alarm) flags are set.
    if (_watch_rtc_is_enabled()) {
        // User code. Give the application a chance to restore state from backup registers.
        app_wake_from_backup();

        // disable the tamper interrupt and clear the tamper bit
        hri_rtcmode0_clear_INTEN_TAMPER_bit(RTC);
        hri_rtcmode0_clear_interrupt_TAMPER_bit(RTC);
    }

    // Watch library code. Set initial parameters for the device and enable the RTC.
    _watch_init();

    // if date/time register is 0 (power on reset state), default year to 2023.
    watch_date_time date_time = watch_rtc_get_date_time();
    if (date_time.reg == 0) {
        date_time.unit.year = 3;
        watch_rtc_set_date_time(date_time);
    }

    // User code. Give the app a chance to enable and set up peripherals.
    app_setup();

    while (1) {
        bool usb_enabled = hri_usbdevice_get_CTRLA_ENABLE_bit(USB);
        bool can_sleep = app_loop();
        if (can_sleep && !usb_enabled) {
            app_prepare_for_standby();
            sleep(4);
            app_wake_from_standby();
        }
    }

    return 0;
}

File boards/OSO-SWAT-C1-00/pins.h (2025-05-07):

#ifndef PINS_H_INCLUDED
#define PINS_H_INCLUDED

// Detects if we are on USB power.
#define VBUS_DET GPIO(GPIO_PORTB, 5)

// Buttons
#define BTN_ALARM GPIO(GPIO_PORTA, 2)
#define WATCH_BTN_ALARM_EIC_CHANNEL 2
#define BTN_LIGHT GPIO(GPIO_PORTA, 30)
#define WATCH_BTN_LIGHT_EIC_CHANNEL 10
#define BTN_MODE GPIO(GPIO_PORTA, 31)
#define WATCH_BTN_MODE_EIC_CHANNEL 11

// Temperature Sensor
#define TS_ENABLE GPIO(GPIO_PORTB, 23)
#define TEMPSENSE GPIO(GPIO_PORTA, 3)

// Light Sensor
#define IR_ENABLE GPIO(GPIO_PORTB, 22)
#define IRSENSE GPIO(GPIO_PORTA, 4)

// Buzzer
#define BUZZER GPIO(GPIO_PORTA, 27)
#define WATCH_BUZZER_TCC_PINMUX PINMUX_PA27F_TCC0_WO5
#define WATCH_BUZZER_TCC_CHANNEL 1

// LEDs
#define WATCH_INVERT_LED_POLARITY

#define RED GPIO(GPIO_PORTA, 12)
#define WATCH_RED_TCC_CHANNEL 2
#define WATCH_RED_TCC_PINMUX PINMUX_PA12F_TCC0_WO6

#define BLUE GPIO(GPIO_PORTA, 13)
#define WATCH_BLUE_TCC_CHANNEL 3
#define WATCH_BLUE_TCC_PINMUX PINMUX_PA13F_TCC0_WO7

#define GREEN GPIO(GPIO_PORTA, 22)
#define WATCH_GREEN_TCC_CHANNEL 0
#define WATCH_GREEN_TCC_PINMUX PINMUX_PA22F_TCC0_WO4

// Segment LCD
#define SLCD0 GPIO(GPIO_PORTB, 6)
#define SLCD1 GPIO(GPIO_PORTB, 7)
#define SLCD2 GPIO(GPIO_PORTB, 8)
#define SLCD3 GPIO(GPIO_PORTB, 9)
#define SLCD4 GPIO(GPIO_PORTA, 5)
#define SLCD5 GPIO(GPIO_PORTA, 6)
#define SLCD6 GPIO(GPIO_PORTA, 7)
#define SLCD7 GPIO(GPIO_PORTA, 8)
#define SLCD8 GPIO(GPIO_PORTA, 9)
#define SLCD9 GPIO(GPIO_PORTA, 10)
#define SLCD10 GPIO(GPIO_PORTA, 11)
#define SLCD11 GPIO(GPIO_PORTB, 11)
#define SLCD12 GPIO(GPIO_PORTB, 12)
#define SLCD13 GPIO(GPIO_PORTB, 13)
#define SLCD14 GPIO(GPIO_PORTB, 14)
#define SLCD15 GPIO(GPIO_PORTB, 15)
#define SLCD16 GPIO(GPIO_PORTA, 14)
#define SLCD17 GPIO(GPIO_PORTA, 15)
#define SLCD18 GPIO(GPIO_PORTA, 16)
#define SLCD19 GPIO(GPIO_PORTA, 17)
#define SLCD20 GPIO(GPIO_PORTA, 18)
#define SLCD21 GPIO(GPIO_PORTA, 19)
#define SLCD22 GPIO(GPIO_PORTB, 16)
#define SLCD23 GPIO(GPIO_PORTB, 17)
#define SLCD24 GPIO(GPIO_PORTA, 20)
#define SLCD25 GPIO(GPIO_PORTA, 21)
#define SLCD26 GPIO(GPIO_PORTA, 23)
// This board uses a slightly different pin mapping from the standard watch, and it's not enough to
// just declare the pins. We also have to set the LCD Pin Enable register with the SLCD pins we're
// using. These numbers are not port/pin numbers, but the "SLCD/LP[x]" numbers in the pinmux table.
// If not defined in pins.h, the LCD driver will fall back to the pin mapping in hpl_slcd_config.h.
// LPENL is for pins SLCD/LP[0..31].
#define CONF_SLCD_LPENL (\
        (uint32_t)1 <<  0 | \
        (uint32_t)1 <<  1 | \
        (uint32_t)1 <<  2 | \
        (uint32_t)1 <<  3 | \
        (uint32_t)1 <<  5 | \
        (uint32_t)1 <<  6 | \
        (uint32_t)1 <<  7 | \
        (uint32_t)1 << 11 | \
        (uint32_t)1 << 12 | \
        (uint32_t)1 << 13 | \
        (uint32_t)1 << 14 | \
        (uint32_t)1 << 21 | \
        (uint32_t)1 << 22 | \
        (uint32_t)1 << 23 | \
        (uint32_t)1 << 24 | \
        (uint32_t)1 << 25 | \
        (uint32_t)1 << 30 | \
        (uint32_t)1 << 31 | 0)
// LPENH is for pins SLCD/LP[32..51], where bit 0 represents pin 32.
#define CONF_SLCD_LPENH (\
        (uint32_t)1 << (32 - 32) | \
        (uint32_t)1 << (33 - 32) | \
        (uint32_t)1 << (34 - 32) | \
        (uint32_t)1 << (35 - 32) | \
        (uint32_t)1 << (42 - 32) | \
        (uint32_t)1 << (43 - 32) | \
        (uint32_t)1 << (48 - 32) | \
        (uint32_t)1 << (49 - 32) | \
        (uint32_t)1 << (51 - 32) | 0)


// 9-pin connector
#define A0 GPIO(GPIO_PORTB, 4)
#define WATCH_A0_EIC_CHANNEL 4
#define A1 GPIO(GPIO_PORTB, 1)
#define WATCH_A1_EIC_CHANNEL 1
#define A2 GPIO(GPIO_PORTB, 2)
#define WATCH_A2_EIC_CHANNEL 2
#define A3 GPIO(GPIO_PORTB, 3)
#define WATCH_A3_EIC_CHANNEL 3
#define A4 GPIO(GPIO_PORTB, 0)
#define WATCH_A4_EIC_CHANNEL 0
#define SDA GPIO(GPIO_PORTB, 30)
#define SCL GPIO(GPIO_PORTB, 31)

// aliases for as A3/A4; these were mentioned as D0/D1 in early documentation.
#define D0 GPIO(GPIO_PORTB, 3)
#define D1 GPIO(GPIO_PORTB, 0)

// interrupt mapping
#define EXT_IRQ_AMOUNT 6
#define CONFIG_EIC_EXTINT_MAP {0, PIN_PB00}, {1, PIN_PB01}, {2, PIN_PA02}, {3, PIN_PB03}, {10, PIN_PA30}, {11, PIN_PA31},

#endif // PINS_H_INCLUDED

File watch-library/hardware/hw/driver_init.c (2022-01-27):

/*
 * Code generated from Atmel Start.
 *
 * This file will be overwritten when reconfiguring your Atmel Start project.
 * Please copy examples or other code you want to keep to a separate file
 * to avoid losing it when reconfiguring.
 */

#include "driver_init.h"
#include <peripheral_clk_config.h>
#include <utils.h>
#include <hal_init.h>

struct slcd_sync_descriptor SEGMENT_LCD_0;

struct i2c_m_sync_desc I2C_0;

struct spi_m_sync_descriptor SPI_0;

void I2C_0_PORT_init(void) {

	gpio_set_pin_pull_mode(SDA,
	                       // <y> Pull configuration
	                       // <id> pad_pull_config
	                       // <GPIO_PULL_OFF"> Off
	                       // <GPIO_PULL_UP"> Pull-up
	                       // <GPIO_PULL_DOWN"> Pull-down
	                       GPIO_PULL_OFF);

	gpio_set_pin_function(SDA, PINMUX_PB30C_SERCOM1_PAD0);

	gpio_set_pin_pull_mode(SCL,
	                       // <y> Pull configuration
	                       // <id> pad_pull_config
	                       // <GPIO_PULL_OFF"> Off
	                       // <GPIO_PULL_UP"> Pull-up
	                       // <GPIO_PULL_DOWN"> Pull-down
	                       GPIO_PULL_OFF);

	gpio_set_pin_function(SCL, PINMUX_PB31C_SERCOM1_PAD1);
}

void I2C_0_CLOCK_init(void) {
	hri_gclk_write_PCHCTRL_reg(GCLK, SERCOM1_GCLK_ID_CORE, CONF_GCLK_SERCOM1_CORE_SRC | (1 << GCLK_PCHCTRL_CHEN_Pos));
	hri_gclk_write_PCHCTRL_reg(GCLK, SERCOM1_GCLK_ID_SLOW, CONF_GCLK_SERCOM1_SLOW_SRC | (1 << GCLK_PCHCTRL_CHEN_Pos));
	hri_mclk_set_APBCMASK_SERCOM1_bit(MCLK);
}

void I2C_0_init(void) {
	I2C_0_CLOCK_init();
	i2c_m_sync_init(&I2C_0, SERCOM1);
	I2C_0_PORT_init();
}

void SPI_0_PORT_init(void) {

	gpio_set_pin_level(A2,
	                   // <y> Initial level
	                   // <id> pad_initial_level
	                   // <false"> Low
	                   // <true"> High
	                   false);

	// Set pin direction to output
	gpio_set_pin_direction(A2, GPIO_DIRECTION_OUT);

	gpio_set_pin_function(A2, PINMUX_PB02C_SERCOM3_PAD0);

	// Set pin direction to input
	gpio_set_pin_direction(A4, GPIO_DIRECTION_IN);

	gpio_set_pin_pull_mode(A4,
	                       // <y> Pull configuration
	                       // <id> pad_pull_config
	                       // <GPIO_PULL_OFF"> Off
	                       // <GPIO_PULL_UP"> Pull-up
	                       // <GPIO_PULL_DOWN"> Pull-down
	                       GPIO_PULL_OFF);

	gpio_set_pin_function(A4, PINMUX_PB00C_SERCOM3_PAD2);

	gpio_set_pin_level(A1,
	                   // <y> Initial level
	                   // <id> pad_initial_level
	                   // <false"> Low
	                   // <true"> High
	                   false);

	// Set pin direction to output
	gpio_set_pin_direction(A1, GPIO_DIRECTION_OUT);

	gpio_set_pin_function(A1, PINMUX_PB01C_SERCOM3_PAD3);
}

void SPI_0_CLOCK_init(void) {
	hri_gclk_write_PCHCTRL_reg(GCLK, SERCOM3_GCLK_ID_CORE, CONF_GCLK_SERCOM3_CORE_SRC | (1 << GCLK_PCHCTRL_CHEN_Pos));
	hri_gclk_write_PCHCTRL_reg(GCLK, SERCOM3_GCLK_ID_SLOW, CONF_GCLK_SERCOM3_SLOW_SRC | (1 << GCLK_PCHCTRL_CHEN_Pos));
	hri_mclk_set_APBCMASK_SERCOM3_bit(MCLK);
}

void SPI_0_init(void) {
	SPI_0_CLOCK_init();
	spi_m_sync_init(&SPI_0, SERCOM3);
	SPI_0_PORT_init();
}

void delay_driver_init(void) {
	delay_init(SysTick);
}

void SEGMENT_LCD_0_PORT_init(void) {
	gpio_set_pin_function(SLCD0, GPIO_PIN_FUNCTION_B);
	gpio_set_pin_function(SLCD1, GPIO_PIN_FUNCTION_B);
	gpio_set_pin_function(SLCD2, GPIO_PIN_FUNCTION_B);
	gpio_set_pin_function(SLCD3, GPIO_PIN_FUNCTION_B);
	gpio_set_pin_function(SLCD4, GPIO_PIN_FUNCTION_B);
	gpio_set_pin_function(SLCD5, GPIO_PIN_FUNCTION_B);
	gpio_set_pin_function(SLCD6, GPIO_PIN_FUNCTION_B);
	gpio_set_pin_function(SLCD7, GPIO_PIN_FUNCTION_B);
	gpio_set_pin_function(SLCD8, GPIO_PIN_FUNCTION_B);
	gpio_set_pin_function(SLCD9, GPIO_PIN_FUNCTION_B);
	gpio_set_pin_function(SLCD10, GPIO_PIN_FUNCTION_B);
	gpio_set_pin_function(SLCD11, GPIO_PIN_FUNCTION_B);
	gpio_set_pin_function(SLCD12, GPIO_PIN_FUNCTION_B);
	gpio_set_pin_function(SLCD13, GPIO_PIN_FUNCTION_B);
	gpio_set_pin_function(SLCD14, GPIO_PIN_FUNCTION_B);
	gpio_set_pin_function(SLCD15, GPIO_PIN_FUNCTION_B);
	gpio_set_pin_function(SLCD16, GPIO_PIN_FUNCTION_B);
	gpio_set_pin_function(SLCD17, GPIO_PIN_FUNCTION_B);
	gpio_set_pin_function(SLCD18, GPIO_PIN_FUNCTION_B);
	gpio_set_pin_function(SLCD19, GPIO_PIN_FUNCTION_B);
	gpio_set_pin_function(SLCD20, GPIO_PIN_FUNCTION_B);
	gpio_set_pin_function(SLCD21, GPIO_PIN_FUNCTION_B);
	gpio_set_pin_function(SLCD22, GPIO_PIN_FUNCTION_B);
	gpio_set_pin_function(SLCD23, GPIO_PIN_FUNCTION_B);
	gpio_set_pin_function(SLCD24, GPIO_PIN_FUNCTION_B);
	gpio_set_pin_function(SLCD25, GPIO_PIN_FUNCTION_B);
	gpio_set_pin_function(SLCD26, GPIO_PIN_FUNCTION_B);
}

/**
 * \brief SLCD initialization function
 *
 * Enables SLCD peripheral, clocks and initializes SLCD driver
 */
void SEGMENT_LCD_0_init(void) {
	hri_mclk_set_APBCMASK_SLCD_bit(SLCD);
	slcd_sync_init(&SEGMENT_LCD_0, SLCD);
	SEGMENT_LCD_0_PORT_init();
}

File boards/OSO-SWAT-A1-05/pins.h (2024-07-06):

#ifndef PINS_H_INCLUDED
#define PINS_H_INCLUDED

// Detects if we are on USB power.
#define VBUS_DET GPIO(GPIO_PORTB, 5)

// Buttons
#define BTN_ALARM GPIO(GPIO_PORTA, 2)
#define WATCH_BTN_ALARM_EIC_CHANNEL 2
#define BTN_LIGHT GPIO(GPIO_PORTA, 22)
#define WATCH_BTN_LIGHT_EIC_CHANNEL 6
#define BTN_MODE GPIO(GPIO_PORTA, 23)
#define WATCH_BTN_MODE_EIC_CHANNEL 7

// Buzzer
#define BUZZER GPIO(GPIO_PORTA, 27)
#define WATCH_BUZZER_TCC_PINMUX PINMUX_PA27F_TCC0_WO5
#define WATCH_BUZZER_TCC_CHANNEL 1

// LEDs
#ifdef WATCH_IS_BLUE_BOARD
    #define RED GPIO(GPIO_PORTA, 21)
    #define WATCH_RED_TCC_PINMUX PINMUX_PA21F_TCC0_WO7
    #define WATCH_RED_TCC_CHANNEL 3
    #define GREEN GPIO(GPIO_PORTA, 20)
    #define WATCH_GREEN_TCC_CHANNEL 2
    #define WATCH_GREEN_TCC_PINMUX PINMUX_PA20F_TCC0_WO6
#else
    #define RED GPIO(GPIO_PORTA, 20)
    #define WATCH_RED_TCC_PINMUX PINMUX_PA20F_TCC0_WO6
    #define WATCH_RED_TCC_CHANNEL 2
    #define GREEN GPIO(GPIO_PORTA, 21)
    #define WATCH_GREEN_TCC_CHANNEL 3
    #define WATCH_GREEN_TCC_PINMUX PINMUX_PA21F_TCC0_WO7
#endif

// Segment LCD
#define SLCD0 GPIO(GPIO_PORTB, 6)
#define SLCD1 GPIO(GPIO_PORTB, 7)
#define SLCD2 GPIO(GPIO_PORTB, 8)
#define SLCD3 GPIO(GPIO_PORTB, 9)
#define SLCD4 GPIO(GPIO_PORTA, 4)
#define SLCD5 GPIO(GPIO_PORTA, 5)
#define SLCD6 GPIO(GPIO_PORTA, 6)
#define SLCD7 GPIO(GPIO_PORTA, 7)
#define SLCD8 GPIO(GPIO_PORTA, 8)
#define SLCD9 GPIO(GPIO_PORTA, 9)
#define SLCD10 GPIO(GPIO_PORTA, 10)
#define SLCD11 GPIO(GPIO_PORTA, 11)
#define SLCD12 GPIO(GPIO_PORTB, 11)
#define SLCD13 GPIO(GPIO_PORTB, 12)
#define SLCD14 GPIO(GPIO_PORTB, 13)
#define SLCD15 GPIO(GPIO_PORTB, 14)
#define SLCD16 GPIO(GPIO_PORTB, 15)
#define SLCD17 GPIO(GPIO_PORTA, 12)
#define SLCD18 GPIO(GPIO_PORTA, 13)
#define SLCD19 GPIO(GPIO_PORTA, 14)
#define SLCD20 GPIO(GPIO_PORTA, 15)
#define SLCD21 GPIO(GPIO_PORTA, 16)
#define SLCD22 GPIO(GPIO_PORTA, 17)
#define SLCD23 GPIO(GPIO_PORTA, 18)
#define SLCD24 GPIO(GPIO_PORTA, 19)
#define SLCD25 GPIO(GPIO_PORTB, 16)
#define SLCD26 GPIO(GPIO_PORTB, 17)

// 9-pin connector
#define A0 GPIO(GPIO_PORTB, 4)
#define WATCH_A0_EIC_CHANNEL 4
#define A1 GPIO(GPIO_PORTB, 1)
#define WATCH_A1_EIC_CHANNEL 1
#define A2 GPIO(GPIO_PORTB, 2)
#define WATCH_A2_EIC_CHANNEL 2
#define A3 GPIO(GPIO_PORTB, 3)
#define WATCH_A3_EIC_CHANNEL 3
#define A4 GPIO(GPIO_PORTB, 0)
#define WATCH_A4_EIC_CHANNEL 0
#define SDA GPIO(GPIO_PORTB, 30)
#define SCL GPIO(GPIO_PORTB, 31)

// aliases for as A3/A4; these were mentioned as D0/D1 in early documentation.
#define D0 GPIO(GPIO_PORTB, 3)
#define D1 GPIO(GPIO_PORTB, 0)

// interrupt mapping
#define EXT_IRQ_AMOUNT 6
#define CONFIG_EIC_EXTINT_MAP {0, PIN_PB00}, {1, PIN_PB01}, {2, PIN_PA02}, {3, PIN_PB03}, {6, PIN_PA22}, {7, PIN_PA23},

#endif // PINS_H_INCLUDED

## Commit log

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2021-08-08 fix renaming of _watch_rtc_is_enabled
    [main.c]
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2021-08-09 fix LED part number, make boards identical
    [OSO-SWAT-A1-04-BLUE.brd, OSO-SWAT-A1-04.brd, OSO-SWAT-A1-04.sch]
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2021-08-18 reapprove dimension errors
    [OSO-SWAT-A1-04-BLUE.brd]
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2021-08-29 big PWM refactor: drive both LEDs and buzzer from TCC
    [driver_init.c]
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2021-09-30 fix LED resistor values
    [OSO-SWAT-A1-05-BLUE.brd, OSO-SWAT-A1-05-BLUE.sch]
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2021-12-06 fix missing prototype warnings
    [driver_init.h, flash_watch_pyruler.ino]
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2022-01-04 new temperature board rev (+20 mils to flex connector)
    [OSO-MISC-22-001 Temperature + GPIO + I2C.brd, OSO-MISC-22-001 Temperature + GPIO + I2C.sch]
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2022-01-09 set correct registers for range and rate
    [lis2dw.c]
2022-01-09 lis2dw: add low power / low noise mode
    [lis2dw.c, lis2dw.h]
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2022-01-19 Added ability to reset to default timer value
    Added option to reset to the default timer value when in waiting mode and on long press of alarm. This was useful to me as I sometimes accidentally increase the timer value and then would need to loop around to get back to the default value.
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2022-01-25 Sensor Watch Simulator (#35)
    * Put something on screen
    * Use the 32bit watch_date_time repr to pass from JS
    * Implement periodic callbacks
    * Clear display on enabling
    * Hook up watch_set_led_color() to SVG (green-only)
    * Make debug output full-width
    * Remove default Emscripten canvas
    * Implement sleep and button clicks
    * Fix time zone conversion bug in beats-time app
    * Clean up warnings
    * Fix pin levels
    * Set time zone to browser value (if available)
    * Add basic backup data saving
    * Silence format specifier warnings in both targets
    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
    [driver_init.c, driver_init.h]
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2022-01-27 Update main loop to fix reentrancy runtime errors
    [main.c]
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2022-02-05 fix paste layer on some sensor boards
    [OSO-MISC-21-011 RFID.brd, OSO-MISC-21-011 RFID.sch, OSO-MISC-21-017 Sensor Watch Flash.brd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]
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2022-02-18 lis2dw: bugfix, only read once
    [lis2dw.c]
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2022-05-09 fix warning re: buffer overrun
    [accelerometer_data_acquisition_face.c]
2022-05-19 Make submodule and directory rules order-only prerequisites on objects
    This instructs make to run the tinyusb and directory rules before
    building any objects. Docs: [1].
    After this change, `make clean` started running
    the tinyusb submodule rule before cleaning. This appears to have been
    caused by one of the `build/*.d` files overlapping with the `tinyusb`
    name, triggering that rule. I didn't trace this all the way down to a
    root cause, but switching the include to something less broad solved the
    issue. Roughly guided by [2].
    1: https://www.gnu.org/software/make/manual/html_node/Prerequisite-Types.html
    2: http://make.mad-scientist.net/papers/advanced-auto-dependency-generation/
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2022-07-25 movement: fix movement_request_wake() prototype
    This function has `void` args, currently it can throw a compiler warning
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2022-10-26 Add an Alarm face to movement (#96)
    * Add movement_play_alarm_beeps() to movement.c and make alarm sounds customizable. Add alarm indicator to simple watch face.
    * Add alarm face
    * alarm_face: fix problem with disabling alarms for 00:00.
    * Fix typos in comments and get rid of of unused variable warning
    * remove unnecessary constant
    * simple_clock_face: fix disappearing chime indicator after face switch, enable alarm indicator updates in app loop (for one-time alarms).
    movement: handle situations where watch is in sleep mode and chimes fire off at the same time as alarms properly.
    * alarm_face: tweak process of displaying things on the lcd. Add extra long and extra short al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
2022-11-22 WIP: Add support for bicolor led in the simulator
    I noticed that the bicolor led isn't supported in the simulator. Here is a quick mockup of how I would add support for it.
    I added an SVG filter to the #light rectangle in the SVG which lets us multiply the colours by a matrix in code. I then insert values so that the original green colour gets mixed into the combination of red and green requested by `watch_set_led_color`
    # Testing
    So far I've only tested this with the standard firmware build but it seems to work.
    # Possible issues
    I wasn't 100% sure what to do when red + green > 255, current behaviour is that it gets clamped to 255 in the simulator.
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2023-01-10 RPN Calculator face (#112)
    * Calculator face with guess a number
    * Add more functions, cleanup, and blinking
    * Display operations better in the first location
    * Clean up stack behaviour
    Add empty stack behaviour, check stack bounds, add stack operations.
    Also, make 'mode' always work to switch through faces on entering calculator
    (i.e. by defaulting to OPERATION rather than NUMBER).
    Some edge cases.
    * Tweak negative rounding behaviour; add basic doco
    * Add copyright name.
    * Flip ordering of binary operations
    * Fix compiler warnings
    * Remove watch_private_display hackery and give face a better name
    Also, slightly clearer documentation and a dupe function.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
2023-01-10 Add stock stopwatch face (#140)
    * buzzer sequences: first draft, does not work on hardware yet (but in simulator)
    * buzzer sequences: add changes to movement.c
    * buzzer sequences: add demo face to Makefile
    * buzzer sequences: fix problem of interrupted sounds. Add logic for repeating sub sequences. Tidy up (move logic to watch_buzzer files, remove buzzer_demo_face)
    * buzzer sequences: tidy up even more
    * buzzer sequences: disable registering a 32 Hz tick callback for watch faces, so it will be used exclusively by the buzzer sequences functionality
    * buzzer sequences: add callback slot functionality to watch_rtc and make watch_buzzer use it. Switch internal buzzer sequences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
2023-01-10 Add Tachymeter face (#165)
    * Create template for tachymeter
    * Basic working tachymeter
    * Improve UI for running and results
    * Allow editing distance
    * Alarm long-press to enter and exit editing mode
    * Improve light button behaviour
    * Set distance digit wise.
    * Use 250ms resolution for total time
    * Improve comments
    * Bugfix: Show distance when running and face becomes active
    * Update `%d` to `%lu` in `sprintf` call for `uint32_t`
    * Ignore Alarm button (Up and Long-press) when showing results
    * Improve GUI when running and face gets activated
    * Change speed indicator from `/H` to `/h`
    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
2023-01-10 Precision watch update (#152)
    * Intermediate changes
    * Databank working
    * Main commit for precision timing
    First version where all functions are supposed to be working
    * Fix math error in nanosec. File storage for location.
    * Remove obsolete comments
    * Missing page name on pages rotation - thanks to jeremy
    * Delete file.diff
    * Cleanup+tempchart
    1) finetune must always reset last calibration time when doing non-0 time correction, even when you are not applying ppm correction.
    2) Dithers over 31 periods not 10, more resolution with still no risk of overflow
    3) Minute-boundery finetune fix. I also just got this 1-minute error after finetune...
    4) Write frequency ca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
2023-01-11 Play sound sequences asynchronously (#122)
    * buzzer sequences: add callback slot functionality to watch_rtc and make watch_buzzer use it. Switch internal buzzer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
2023-01-11 Interval timers face (#130)
    * buzzer sequences: add callback slot functionality to watch_rtc and make watch_buzzer use it. Switch internal buzzer sequences tick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
2023-01-23 Minor enhancements for the countdown face (#177)
    * minor enhancements for the countdown face
    * Changed usage of countdown timer.
    - Long button presses have been removed.
    - The light button is used to restore the last countdown as well as enter setting mode when pressed again.
    - The visual state has been removed from the display.
    - The internal states have been renamed to reflect the new logic.
    * restore time when countdown finished.
    * support for fast forward on long press (untested).
    * support for beeps similar to stop watch
    * fixed bug wiht display when fast forwarding
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2023-02-10 countdown_face: implement holding light to reset the currently edited timer value (and everything below it)
2023-02-11 Sensor watch sailing face (#205)
    * Update sailing_face.c
    Modified sailing_face.
    Added features, some of which @niclashoyer already suggested in his initial PR:
    - stopwatch-like counter after start signal
    - lap counter after start signal
    - optional additional sounds at every minute, 30s, 10s countdown
    - sound options (no sound, start only, signals only, all)
    - maximum starting time up to 10min (instead of 9)
    - improved timing, display is no longer delayed by sound
    * Update sailing_face.h
    Modified sailing_face.
    Added features, some of which @niclashoyer already suggested in his initial PR:
    - stopwatch-like counter after start signal
    - lap counter after start signal
    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
2023-03-11 Activity face + Chirpy TX (#187)
    * chirpy demo face; activity face stub
    * activity face WIP: can log, pause and clear
    * activity face and chirpy demo: ready to flash to watch
    * activity face tweaks
    * hour display for hours < 10
    * fix: added rogue paused seconds when stopping activity
    * LE mode; lower power with 1Hz tick
    * fix: midnight is 12
    * Documentation in code comments
    * fixes from code review by @neutralinsomniac
    * chirpy_demo_face option to chirp out nanosec.ini + auto-format
    * UI tweaks
    * remove erroneously added file (content revoked)
    * UI tweaks: return from LE mode; time display vs LAP
    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
2023-04-16 Aperture priority light meter face (#230)
    * initial commit, added opt3001 light meter test app
    * tested working light meter board, i2c communication still has issues
    * fixed i2c; rudimentary lightmeter works!
    * added aperture priority ui
    * added aperture priority ui
    * added README
    * adjusted cal
    * fixed bugs (HI shutter speed, lux mode toggle)
    * made it possible to advance to the next face
    * initialized lux variable
    * lowered tolerance for HI and LO
    * Changed EV display from always showing EV100 to showing EV[iso setting]
    * dont display old ev when ISO changes
    * changed mode and light behavior
    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
    [Q3Q-SWAB-A1-00 Temperature + Test Points + OPT3001.kicad_pcb, Q3Q-SWAB-A1-00 Temperature + Test Points + OPT3001.sch]
2023-04-16 Dual Timer, a variant of the Stock Stopwatch (#236)
    * init
    * advanced latlon setting
    * simple functionality done
    * lat lon high precision fwd bwd
    * edit toggle
    * added readme for branch
    * DD DMS conversion & cleanup
    * DD to OLC conversion
    * olc encoding & decoding
    * OLC implementation
    * swapped bools for modes, code cleanup
    * place name editor
    * updated button logic, fixed display
    * load and save places in state array
    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
2023-04-16 Coin & Dice Toss & Geomantic Divination Watch Faces (#235)
    * todo list
    * simplified OLC functions
    * geohash conversion functions
    * geohash display & digit functions
    * todo
    * finished geohash implementation
    * code display function, defaults, bugfixes
    * read/write fil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
2023-04-16 Randonaut Watch Face (#233)
    * read/write file/reg logic
    * long light in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
2023-05-18 timer face: fix problem with messed up durations for repeating timers / always beep when starting a timer
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2023-07-29 Wyoscan .5 hz watchface (#256)
    * initial wyoscan commit
    * initial attempt at animation
    * kinda working
    * visually working but running out of memory
    * slower
    * little fixes
    * add hardware watch blink function
    * refine number animation
    * remove movement from config for merging
    * silence warnings
    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
2023-07-29 Fix lengthBytesUTF8 not a function (#255)
    * Add lengthBytesUTF8 as an exported runtime method
    * Also export printErr as a runtime method
    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
2023-10-15 Update timer_face.c
    Corrects the data type of the standard values in order to be able to configure seconds as well.
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2023-11-19 Fix simulator and hardware divergence in callback handling (#252)
    When using the simulator, I encountered cases where the light would become stuck on, and the watch
    would be unresponsive. In particular, this would occur when pressing the light button on the
    sunrise sunset watch face.
    I appears that this is caused by a divergence in out the callback mask is interpreted by the
    hardware interface, and in the simulator in the following function.
    void watch_rtc_disable_matching_periodic_callbacks(uint8_t mask)
    In particular, a mask of 0xFE is intended to disable all except the 128hz callback at index 0,
    but instead disables all except the 1hz callback at index 7 in the simulator.
2023-11-19 Simulator: Allow typing a, l & m in console input
    These keys are the shortcuts to "press" the alarm, light and mode
    buttons. However, they prevent these letters from being input in the
    debug console to send filesystem commands. Strangely, there was already
    some code to allow typing these letters in the console output, but not
    in the input.
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2023-11-28 Fix missing documentation for many clock faces:
    * Move from .c to .h as needed for consistency.
    * When missing from both, copy from pull request or wiki.
    * When missing entirely, infer functionality from source code.
    [accelerometer_data_acquisition_face.h]
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2024-01-07 USB Improvements
    * Introduce shell module for basic serial shell with argument parsing
    * Introduce shell_cmd_list module for basic compile-time command
    registration
    * Harden USB handling to hang less and drop fewer inputs
    - Service tud_task() with periodic TC0 timer interrupt
    - Service cdc_task() with periodic TC1 timer interrupt
    - Handle shell servicing in main app loop
    - Add a circular buffering layer for reads/writes
    * Change newline prints to also send carriage return
    * Refactor filesystem commands for shell subsystem
    * Introduce new shell commands:
    - 'help' command
    - 'flash' command to reset into bootloader
    - 'stress' command to stress CDC writes
    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
    [main.c]
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2024-02-25 faces/clock: simplify alarm indication function
    Deduplicates state in the clock state and movement settings.
    Makes the code simpler.
    Also makes it use the correct indicator.
    For some reason it had been switched
    with the hourly chime indicator.
    WATCH_INDICATOR_BELL
    The small bell indicating that an alarm is set.
    WATCH_INDICATOR_SIGNAL
    The hourly signal indicator.
    Also useful for indicating that sensors are on.
2024-02-25 faces/clock: simplify signal indication function
    Simplifies the code and makes it use the correct indicator.
    For some reason it had been switched with the alarm indicator.
    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
2024-03-05 faces/totp: update copyrights
    Update the copyrights to include full name attribution
    to Max Zettlmeißl whose code I've incorporated and who
    has explicitly licensed it as MIT.
    Max Zettlmeißl (@maxz) commented on 2024-01-20:
    > I provide all my changes under the MIT license
    GitHub-Comment: https://github.com/joeycastillo/Sensor-Watch/pull/356#issuecomment-1902114306
2024-03-05 faces/pulsometer: remember pulsometer calibration
    Avoid resetting it to default when the face is activated.
    Set the default pulsometer calibration once,
    only when the face is first set up.
    This makes it remember the calibration set by the user.
    It will no longer overwrite it.
2024-03-06 movement: fix unintended timeout short circuiting
    Currently, movement drops time out events in case the previous loop
    indicates that sleep is not possible due to short circuiting behavior
    of logical and in C: if the left-hand side is false, the right hand
    side is not evaluated at all, which means the loop is not called.
    This was not intended to happen.
    Fix it by storing the result in a second boolean variable
    and working out the logic after the fact.
2024-03-17 faces/totp: improve memory usage
    The TOTP face is working in the simulator but fails on the real hardware
    when loaded with lots of codes, just like the LFS version.
    This is likely caused by the recent refactoring of the TOTP face
    which introduced a declarative credential interface for ease of use.
    That's accomplished by decoding the secrets at runtime which increases
    the RAM requirements. Users are likely hitting memory limits.
    In order to mitigate this, the algorithm is changed from decoding
    all of the secrets only once during initialization to on the fly
    decoding of the secret for the current TOTP credential only.
    This converts this face's dynamic memory usage from O(N) to O(1)
    at the cos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
2024-03-18 faces/totp: remove dynamic memory allocation
    Allocate an unlimited extent 128 byte buffer once during setup
    instead of allocating and deallocating repeatedly. A static buffer
    was not used because it fails to be reentrant and prevents multiple
    instances of the watch face to be compiled by the user.
    The advantage is the complete prevention of memory management errors,
    improving the reliability of the watch. It also eliminates the overhead
    of the memory allocator itself since malloc is not free.
    The disadvantage is a worst case default size of 128 bytes was required,
    meaning about 90 bytes will be wasted in the common case since most keys
    are not that big. This can be overridden by the user vi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
2024-03-20 faces/totp: fix error message not displayed bug
    Forgot to call watch_display_string on the error message.
    Of course the message isn't going to be displayed.
    Also, increase the buffer size to 10 characters
    and output a space to the last position.
    This ensures the segments are cleared.
    Tested-by: Matheus Afonso Martins Moreira <matheus.a.m.moreira@gmail.com>
    Tested-on-hardware-by: madhogs <59648482+madhogs@users.noreply.github.com>
    GitHub-Pull-Request: https://github.com/joeycastillo/Sensor-Watch/pull/385
2024-03-20 faces/totp: avoid displaying when key is invalid
    Fixes a division by zero bug caused by calling getCodeFromTimestamp
    without having initialized the TOTP library with a secret first.
    This was happening because the face calls totp_display on activation,
    meaning the validity of the secret was not checked since this is
    done in the generate function.
    Now the validity of the key is determined solely by the size
    of the current decoded key. A general display function checks it
    and decides whether to display the code or just the error message.
    The size of the current decoded key is initialized to zero
    on watch face activation, ensuring fail safe operation.
    Tested-by: Matheus Afonso Martins Moreira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
2024-07-30 Revert "Leaving sleep with alarm button up doesn't trigger alarm button"
    This reverts commit 7d5aaf60caa943a248a7f635111ddfd50c230389.
2024-08-02 The timezone now auto-corrects with DST (but still displays the same offset in the settings screen to the user)
    [accelerometer_data_acquisition_face.c]
2024-08-11 Changed debounce to ignore button presses after a press down or up rathe rthan dact after a set amount of time due to an issue of delay_ms allowing a shoft-bricking
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2024-08-22 Update Devcontainer Dockerfile
    This PR updates the .devcontainer Dockerfile which was no longer
    working. Attempting to build an image from the Dockerfile would result
    in an error:
    ```
    E: The repository 'http://archive.ubuntu.com/ubuntu kinetic Release' does not have a Release file.
    ```
    AFAIU, this is because the 22.04 release is no longer supported. I
    changed the base image to the current LTS release, which should remain
    supported until 2029.
    In addition, the Dockerfile is also modified to install `emscripten` APT
    package. While this is not the recommented installation method from the
    Emscripten docs, it is much more convenient and works enough to build
    the simulator using the resulting D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
2024-09-07 Fixed bugs and improved watchface
    - A background task is only scheduled if the alarm option is activated. If the option is enabled, an alarm sounds when the next deadline is reached. If the option is disabled, no alarm sounds and the watch can enter low energy sleep.
    - Fixed tick frequency error. During running mode, the clock ticks at 1Hz. This is set in the init function `_running_init` and thus ensures that we do not run too fast when returning from the setting mode.
    - Minor corrections to comments and indentations.
2024-09-07 Alarm handled using background task.
    The alarm for deadlines is now handled via a background task. Instead of a scheduled task that prevents sleep mode, the face checks in the background every minute whether an deadline is due. If this is the case, the face wakes up from sleep mode and starts a scheduled task for the remaining seconds.
2024-09-10 make: add beeps face to build
    PR #386 did not add the C file to the makefile,
    causing the build to fail at the link stage
    due to the missing object file and the symbols
    that were supposed to be provided by it.
    Adding the file to the build fixes #472.
    Reported-by: CarpeNoctem <cryptomax@pm.me>
    Fixed-by: CarpeNoctem <cryptomax@pm.me>
    Reviewed-by: Matheus Afonso Martins Moreira <matheus@matheusmoreira.com>
    GitHub-Issue: https://github.com/joeycastillo/Sensor-Watch/issues/472
2024-09-10 Revert PR #387 - fixes LE state restoration
    This commit caused state restored from backup registers
    to be overwritten. It is thereby reverted until a better
    solution is found or movement is refactored.
    This reverts commit 524098b9258232964d7756d4d44f16b006d340bf.
    References: https://github.com/joeycastillo/Sensor-Watch/pull/474
    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
2024-09-16 faces/alarm: fix 24h indication in 024h mode
    The watch was not indicating to the user that it was in 24h mode
    when set to the leading zero 024h time format. This could lead
    to ambiguity and confusion, so make sure to indicate 24h mode.
    Closes #476.
    GitHub-Issue: https://github.com/joeycastillo/Sensor-Watch/issues/476
    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
2024-09-16 faces/alarm: use snprintf formats for 24h and 024h
    This ensures that the display is always in a consistent state.
    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
2024-09-16 faces/simple_clock: clear segments if not in 024h
    There was an issue where the simple clock's display would remain in
    024h mode even after switching back to 12h/24h mode because it only
    took into account the leading zero bit, whose value is meaningless
    unless the 24h mode bit is also set.
    The issue is fixed by taking both bits into account.
    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
2024-09-16 faces/clock: clear segments if not in 024h mode
    There was an issue where the clock's display would remain in 024h mode
    even after switching back to 12h/24h mode because it only took into
    account the leading zero bit, whose value is meaningless unless the
    24h mode bit is also set.
    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
2024-09-17 Revert PR #470 - implement automatic DST toggling
    The DST code has not yet been fully tested, the upcoming movement
    refactor is upon us and it will integrate with the micro timezone
    library anyway. Revert it so that next can be merged into main.
    This reverts commit ac5bf8cfce67cdb5662aeea618c2eb9511f0d190, reversing
    changes made to 5a8a49a8c77d6d5ba0f46f0e5b51dec2daba46db.
    [accelerometer_data_acquisition_face.c]
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

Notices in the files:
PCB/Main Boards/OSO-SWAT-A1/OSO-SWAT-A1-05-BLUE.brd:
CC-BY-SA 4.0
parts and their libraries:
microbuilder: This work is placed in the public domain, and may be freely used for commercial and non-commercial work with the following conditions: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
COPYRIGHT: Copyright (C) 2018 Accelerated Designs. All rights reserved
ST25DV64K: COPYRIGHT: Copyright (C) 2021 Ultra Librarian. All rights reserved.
